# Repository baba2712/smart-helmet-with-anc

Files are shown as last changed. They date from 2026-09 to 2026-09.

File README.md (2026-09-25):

# ANC Safety Helmet

An industrial safety helmet with **hybrid active noise cancellation** (feed-forward + adaptive feedback FxLMS) on an STM32H743. Target: take ~100 dB(A) plant noise down to **≤ 75 dB(A) at the ear** (passive earcup + ANC), below the 85 dB(A) 8-hour limit. Also a built-in **noise dosimeter**, **hear-through** for speech and alarms, a **seal monitor** that measures the cup's attenuation while it is worn and warns when the seal leaks (glasses, hair, a tilted helmet), and an optional **BLE** link.

> Status: **prototype design, not certified PPE.** Nothing has been built or measured on real hardware yet. See [Status](#status).

## Simulated results (100 dB(A) ambient)

| Noise | Open ear | Passive cup | Passive + ANC | Total reduction |
| --- | --- | --- | --- | --- |
| Motor / fan (tonal) | 100.0 | 80.7 | **72.3 dB(A)** | 27.7 dB |
| Compressor | 99.9 | 77.3 | **73.6 dB(A)** | 26.4 dB |
| Broadband (pink) | 99.9 | 72.4 | **69.1 dB(A)** | 30.8 dB |

ANC adds 3–8.5 dB(A) on top of the passive cup; most gain is on tonal machine noise (80–400 Hz). Known limitation: energy below 63 Hz is not reduced. Full report: [`sim/results/summary.md`](sim/results/summary.md).

On **70 real field recordings** (engine, chainsaw, hand saw, helicopter, train, vacuum cleaner, washing machine; ESC-50) the level at the ear ends at 65–75 dB(A): [`sim/results/real_audio.md`](sim/results/real_audio.md). Engine rumble needs ~15 Pa of anti-noise at 63 Hz, which sets a driver requirement (below).

**Seal monitor** (10 noises × 4 seal conditions, one factory baseline): 23/23 leaks that cost ≥ 3 dB flagged in 3–5 s, 0 false alarms: [`sim/results/seal_monitor.md`](sim/results/seal_monitor.md).

## Repository

| Folder | What's in it |
| --- | --- |
| `sim/` | Python plant + noise models, the reference hybrid-FxLMS controller, and the full study (`run_all.py`). Also generates firmware tuning headers. `real_audio.py` runs it on real recordings; `seal_ref.py` / `seal_monitor.py` are the seal monitor's reference and study. |
| `firmware/` | Bare-metal C for STM32H743: 32 kHz ADC→DSP→DAC path, FxLMS core, path identification, dosimeter, hear-through, USB CDC (TinyUSB), BLE UART, flash storage, power/UI. `test/` holds firmware-in-the-loop tests against the sim. |
| `hardware/` | KiCad 7 projects (open fine in KiCad 8/9) for three boards, generated from `hardware/gen/` (Python circuit descriptions → schematic → PCB → Freerouting → fab files). `spice/` verifies the analog chain in ngspice. |
| `mechanical/` | OpenSCAD earcup inserts, driver baffle, outside-mic pod, light pipe / button plunger. Parametric; **measure your earmuff** and edit `params.scad`. `check_fit.py` cross-checks the parts against the PCBs and the cup. |
| `tools/` | `anc_tool.py`: host tool for the USB/BLE command link (status, tuning, calibration, driver test, dose log). `acceptance_test.py`: the per-helmet acceptance / TRL-6 evidence run. |
| `docs/` | Architecture notes; [`bringup_and_test.md`](docs/bringup_and_test.md): order, build, bring-up, calibration and the TRL-6 demonstration. |

## Boards

| Board | Layers | Size | State |
| --- | --- | --- | --- |
| `main-board`: MCU, power, charger, left-ear analog, amp | 4 | 60 × 50 mm, 14 mm corners | Routed; DRC 0 unconnected, 0 electrical errors; fab files in `fab/` |
| `satellite-board`: right-ear mic front ends | 2 | 34 × 26 mm | Routed; DRC 0 errors (silk warnings only); fab files in `fab/` |
| `mic-board`: IM73A135 MEMS mic (×4 per helmet) | 2 | 11 × 13.2 mm | Routed; DRC clean; fab files in `fab/` |

## Build and test

```bash
git clone --recursive <this repo>
pip install -r sim/requirements.txt

python3 sim/run_all.py                 # simulation study + regenerates firmware/inc/anc_tuning.h
python3 sim/real_audio.py --fetch      # ANC on real recordings (downloads ~30 MB of ESC-50 clips)
python3 sim/seal_monitor.py            # seal-monitor study (uses the recordings if present)
cd firmware && make                    # needs arm-none-eabi-gcc; -> build/anc_helmet.bin (~79 KB)
python3 test/test_fil.py               # firmware DSP vs simulation (all pass)

cd .. && python3 hardware/spice/run_spice.py   # analog chain in ngspice
python3 mechanical/check_fit.py                # parts vs PCBs vs cup

cd hardware/gen && python3 build.py sch                           # regenerate schematics
python3 pcb_build.py place main-board && python3 pcb_build.py route main-board
python3 pcb_build.py finish main-board && python3 pcb_build.py tie main-board
python3 pcb_build.py fab main-board
```

`pcb_build.py` needs KiCad 7's Python module (Ubuntu: `apt install kicad kicad-footprints kicad-symbols`, run with the system `python3`) and Freerouting 2.x at `../../tools-dl/freerouting2.jar` (or `FREEROUTING_JAR`).

Verified so far:
- Firmware compiles with `-Werror`: 78.8 KB flash, 38 KB DTCM, 4 KB ITCM.
- Firmware-in-the-loop tests all pass. C matches the Python reference to 0.0 dB(A) on all three noise types, and the output matches to about 1e-4 relative. The seal monitor matches its reference to < 0.001 dB with identical decisions.
- Path identification in a quiet room: 16 dB fit, 0.6% model error.
- Dosimeter: a 94 dB calibrator tone reads 93.99 dB(A); NIOSH dose math checks out.
- SPICE ([`hardware/spice/results/spice_results.md`](hardware/spice/results/spice_results.md)): mic front ends match the simulation's plant, noise ~23 dB(A) SPL; VMID buffer 85–87° phase margin (keep the 10 Ω isolation resistor); DAC reconstruction ~26 µs at 1 kHz.
- Mechanical fit: all checks pass; the main board clears the cup wall by only 0.45 mm (measure your earmuff).

## Status

Done:
- [x] Simulation study and tuned parameters
- [x] Firmware (compiles; DSP verified in the loop against the sim)
- [x] Schematics for all three boards
- [x] Satellite and mic boards routed, with Gerber, BOM and CPL files for JLCPCB
- [x] Real-recording ANC study, SPICE verification of the analog chain, mechanical fit check
- [x] Seal monitor (reference, study, firmware, FIL test)
- [x] Main board fully routed (Freerouting + `hardware/gen/finish_route.py`), fab files for all three boards
- [x] Printable STLs (`mechanical/stl/`, nominal earmuff), driver acceptance test in firmware, acceptance-test runner

Remaining:
- [ ] **Order and build** following [`docs/bringup_and_test.md`](docs/bringup_and_test.md).
- [ ] **Driver:** buy 2-3 candidate 40 mm drivers (16 Ω preferred) and keep one that passes `anc_tool.py driver-test` (≥ 17 Pa/V at 63 Hz in the cup).
- [ ] Open all three boards in KiCad 8/9 for a last ERC/DRC and 3D look before ordering (KiCad 7 DRC here is clean apart from two reviewed connector-courtyard overlaps).
- [ ] Measure the real earmuff, update `mechanical/params.scad`, re-run `check_fit.py`, export STLs.
- [ ] Calibrate and accept each helmet: `python3 tools/acceptance_test.py`, then the TRL-6 run (docs/bringup_and_test.md §6).
- [ ] Bring-up and acoustic test on real hardware: SPL meter plus a 94 dB calibrator.

## Safety

This is a research prototype. It is **not certified hearing protection.** Real PPE needs testing to EN 352 / ANSI S3.19 (or IS 9167 in India). The firmware fails safe: it drops to passive-only on divergence, output clipping, fault or low battery. The passive cup still has to protect on its own.

## License

MIT, © Khaja Baba Shaik.

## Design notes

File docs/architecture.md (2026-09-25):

# Architecture

## What the system does

A safety helmet with helmet-mount earmuffs. Each cup has two MEMS microphones and a
40 mm driver. One STM32H743 runs a **hybrid FxLMS** controller for both ears at
32 kHz. It adds anti-noise at the ear, keeps an exposure log (noise dosimeter),
and can pass speech and alarms through at a capped level.

```
 outside noise ~100 dB(A)
        |
        v
  [REF mic] ---+                          (outside the shell, per cup)
               |    [passive cup: -6 dB @63 Hz ... -35 dB @2 kHz]
               v
  +----- preamp + AA filter ----+        ADC1/ADC2 simultaneous, 16-bit, TIM6 @ 32 kHz
  |                             v
  |     x_c = x - F^ * u   (speaker leakage removed)
  |     d^  = e - S^ * u   (IMC disturbance estimate)
  |     y   = W_ff * x_c + W_fb * d^          <- hybrid FxLMS, weighted update
  |     u   = ramp * y + hear_through(x_c)    -> DAC1 -> recon filter -> TPA6132A2 -> driver
  |                             ^
  +----- preamp + AA filter ----+
               ^
  [ERR mic] ---+                          (in the cup, ~8 mm from the ear canal)
```

## Signal chain and latency budget

The controller can only cancel what it can predict. Every microsecond between the
sound reaching the reference mic and the anti-noise leaving the driver has to be
paid for by prediction. So the design avoids anything that buffers.

| Stage | Delay | Why this choice |
| --- | --- | --- |
| Mic + difference preamp | ~0 | Differential MEMS output: common-mode noise on the cable cancels |
| Anti-alias filter (1st-order pole + 2nd-order Sallen-Key, ~9 kHz) | ~30 µs | Kept low-order on purpose. Each pole costs delay |
| SAR ADC (not sigma-delta) | ~1-2 µs | An audio codec's decimation filter would add 0.5-1 ms and kill feed-forward ANC |
| DMA -> ISR -> both outputs computed | ~5 µs | Hot code in ITCM, state in DTCM (zero wait-state), no RTOS in the audio path |
| DAC (unbuffered write, no trigger) | 1 APB clock | Output updates right after the write |
| Zero-order hold + reconstruction filter | ~16 µs + ~25 µs | |
| Amp + driver + acoustic path to error mic | ~30 µs + driver phase | |

The simulation models every one of these as an exact fractional delay
(`sim/plant.py`). The latency sweep in `sim/results/summary.md` shows how much
attenuation each extra 30 µs costs.

## Control algorithm

Hybrid FxLMS, per ear. The files are `firmware/dsp/anc_core.c`, which mirrors
`sim/anc_ref.py` line for line.

* **Feed-forward** (128 taps): the outside mic as reference. Handles tonal machine
  noise (motors, fans, transformer hum) very well, because tonal noise is
  predictable, so causality doesn't limit it.
* **Adaptive feedback, IMC form** (64 taps): the reference is the disturbance
  estimated from the error mic, `d^ = e - S^*u`. It catches what the outside mic
  doesn't see.
* **Secondary-path model S^** (64 taps) and **leakage model F^** (128 taps):
  identified with a white-noise probe. This happens at the factory (quiet room)
  and is then *refined* at every power-on (2 s, ~83 dB SPL at the ear). The
  refinement doubles as a **fit check**: a lifted cup or a dead driver shows up
  as a big model change, and the helmet warns instead of misbehaving.
* **Normalised LMS with leakage**: step size is independent of noise level. Leakage
  (1e-5) keeps the filters bounded.
* **Frequency-weighted update**: a low-shelf (−20 dB below 300 Hz) on the error and
  filtered references. Without it, huge 50/100 Hz tones dominate the gradient,
  and the controller trades a fraction of a dB there for +8 to +20 dB of mid-band
  amplification (found in simulation, see the commit history).
* **30 Hz high-pass on both references**: the driver can't make infrasound. Chasing
  it drives the output into clipping, and the distortion is audible.

Tuned values live in one place, `sim/run_all.py::TUNED`. They are exported to
`firmware/inc/anc_tuning.h`.

## Safety logic (firmware)

| Guard | Trigger | Action |
| --- | --- | --- |
| Divergence watchdog | Error power > 6 dB above the disturbance estimate for 200 ms | Filters reset to zero |
| Clip watchdog | > 5 % of output samples clipped over 100 ms | Filters reset to zero |
| Ear overload | \|p\| at the error mic > 118 dB (sine peak), capped at 90 % of the channel's full scale (~14 Pa), for 50 ms | Forced passive + red LED |
| Output ceiling | Always | Anti-noise clamp at the lower of the DAC range and the amp's 0.9 V swing at the selected gain; hear-through hard-limited to 82 dB SPL |
| Mode changes | Always | 50 ms fades (no clicks) |
| No calibration | `paths_valid == 0` | ANC refuses to run; passive + magenta LED |
| Fit check failure at power-on | Model change > 6 dB or poor fit | Keeps the stored model; amber LED |
| Seal leak (in use) | Per-band cup attenuation >= 3 dB below the factory baseline for 3 s | Amber LED, `seal_leak` in status/BLE, log flag bit 4 |
| HardFault / watchdog reset | Any | DAC to mid-scale and amp muted *before* reset |
| Low battery | < 3.2 V | Saves the log record and powers off |

In every failure the helmet falls back to a **passive earmuff**. That is the safe state.

## Dosimeter

* A-weighted (IEC 61672 biquads at 32 kHz) level at the ear (energy mean of both
  error mics) and outside (reference mic), 1 s LAeq.
* Dose per NIOSH/ISO (85 dB(A), 3 dB exchange) by default. It is configurable for
  OSHA / the Indian Factories Act (90 dB(A), 5 dB exchange).
* A minute-by-minute record (at-ear and outside LAeq, running dose, battery, mode,
  flags) goes into a flash ring in bank 2. That is about 136 h of history, and it
  survives power cycles. The shift dose continues across power-offs until `dose reset`.
* The firmware test checks it against the standard: 94.0 dB at 1 kHz reads
  93.99 dB(A), and 100 dB(A) gives exactly NIOSH's 15 min allowance.

## Seal monitor (in-use protection check)

A cushion leak (safety-glasses temple, hair, a tilted helmet) costs 3-12 dB of
protection, and ANC cannot win it back: the driver's own low-frequency pressure
leaks out too. So the helmet measures its seal continuously and tells the wearer.

It needs no extra sensor or test signal. The ANC core already forms
`x_c = x - F_hat*y` (outside noise without the speaker's leakage) and
`d_hat = e - S_hat*y` (noise that came through the cup, ANC removed). Per ear,
the ISR accumulates octave-band (250 Hz-2 kHz) mean squares of both; once a
second the main loop computes the per-band attenuation `L(x_c) - L(d_hat)`.
Per-band attenuation belongs to the cup and its seal, not to the noise, so one
factory baseline (`seal learn`, reference head, broadband noise) holds for any
noise. Bands within 15 dB of the loudest outside band and above 55 dB count;
their mean shortfall vs the baseline, smoothed over ~4 s, raises the flag at
3 dB (1 dB hysteresis).

Simulation over 10 noises (3 synthetic, 7 real recordings) x 4 seal conditions:
23/23 real leaks flagged in 3-5 s, 0 false alarms (`sim/results/seal_monitor.md`).
C and Python agree to < 0.001 dB (`firmware/test/test_fil.py`). Reference:
`sim/seal_ref.py`; firmware: `seal_*` in `dsp/dsp_misc.c`.

## Boards

| Board | Where | What |
| --- | --- | --- |
| Main (60 × 50 mm, 4-layer) | Left cup | STM32H743VIT6, USB-C, Li-ion charger + power path, 3.3 V buck-boost, 2.8 V analog LDO, left mic front-ends, 2 × DAC reconstruction, TPA6132A2 stereo amp, BLE header, SWD, buttons/LEDs |
| Satellite (34 × 26 mm, 2-layer) | Right cup | Right mic front-ends (so the analog signal crosses the headband cable at line level), speaker connector |
| Mic (11 × 12.5 mm, 2-layer, × 4) | Outside shell and in front of each driver | IM73A135 differential MEMS mic (bottom port) + decoupling |

The pin map lives in one table (`hardware/gen/pinmap.py`). That table generates both
the schematic nets and `firmware/inc/board_pins.h`.

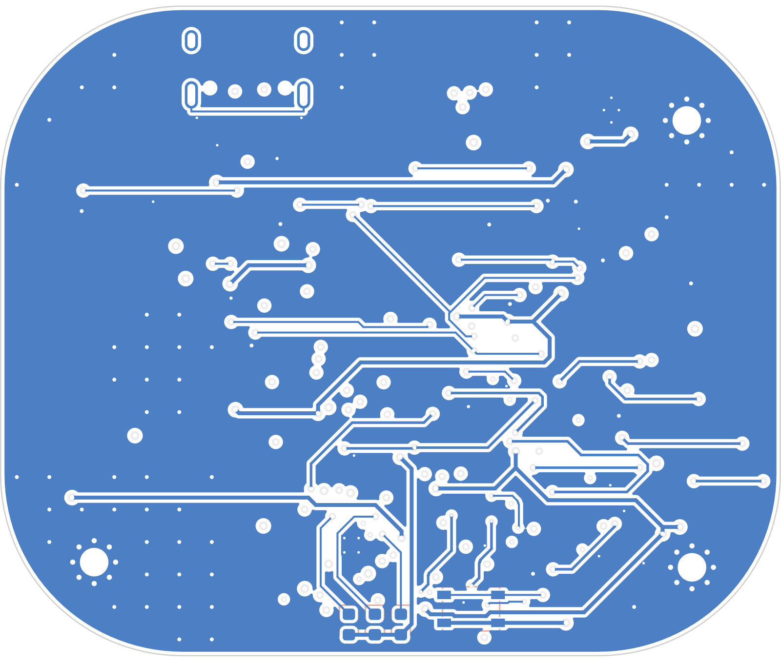
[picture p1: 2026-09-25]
hardware/main-board/fab/main-board-bottom.png

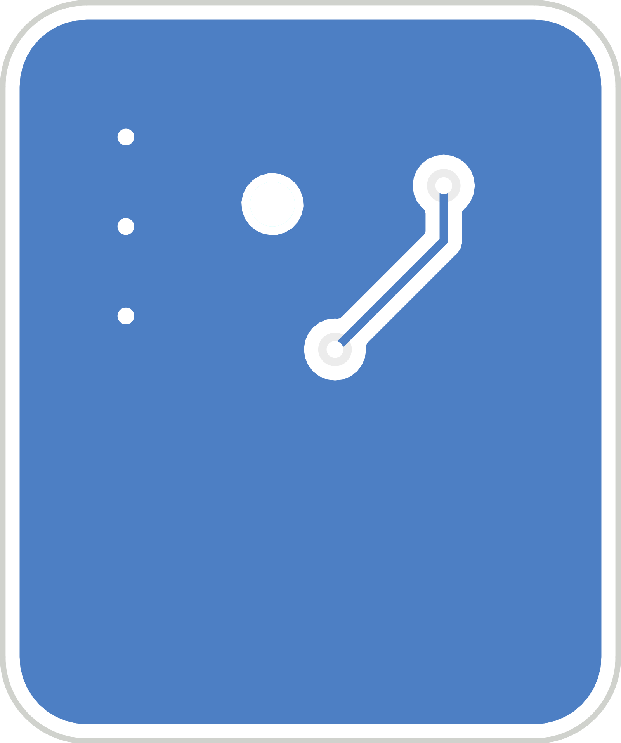
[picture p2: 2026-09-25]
hardware/mic-board/fab/mic-board-bottom.png

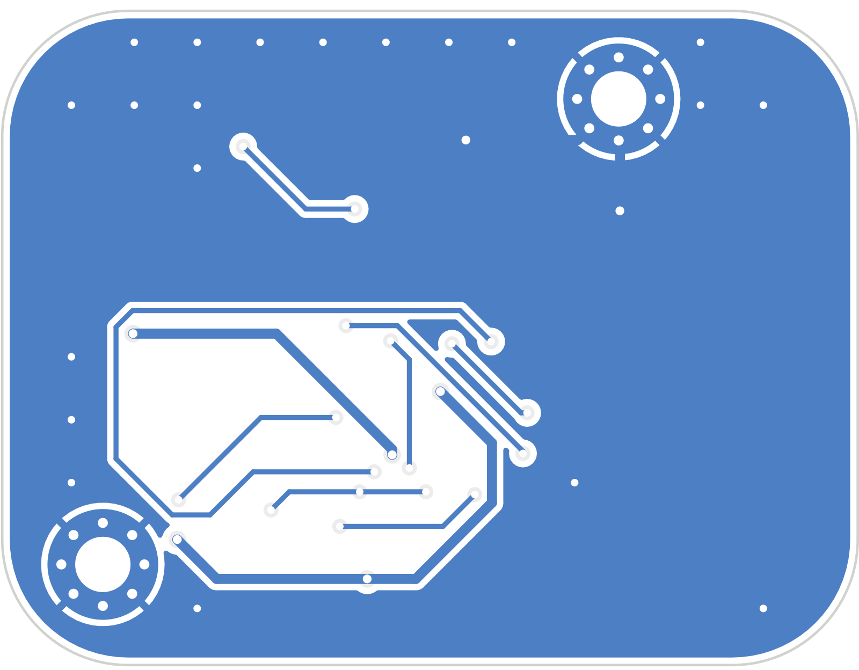
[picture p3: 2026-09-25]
hardware/satellite-board/fab/satellite-board-bottom.png

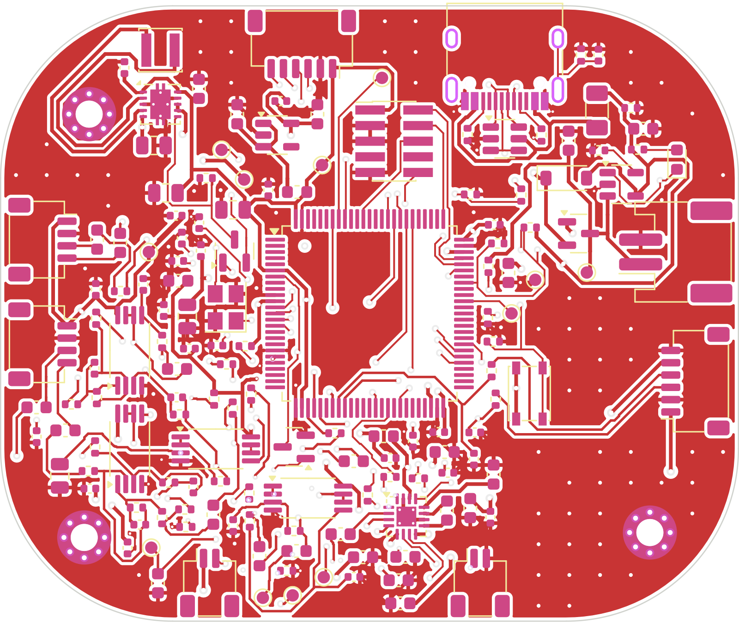
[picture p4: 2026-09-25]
hardware/main-board/fab/main-board-top.png

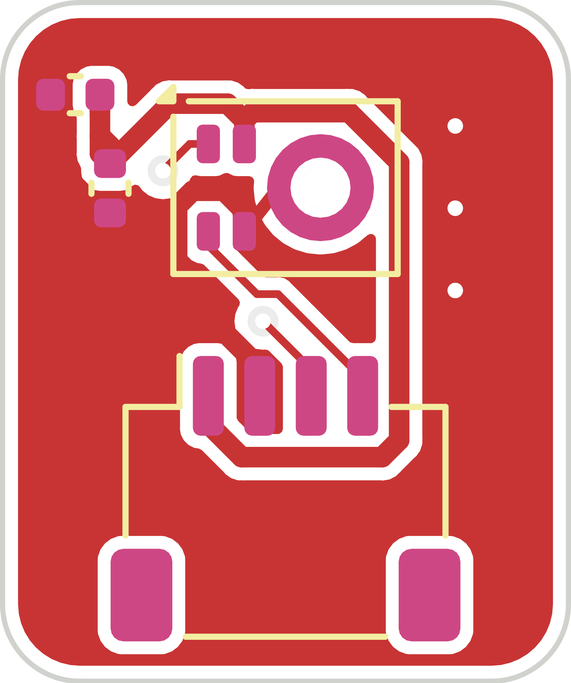
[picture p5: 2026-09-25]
hardware/mic-board/fab/mic-board-top.png

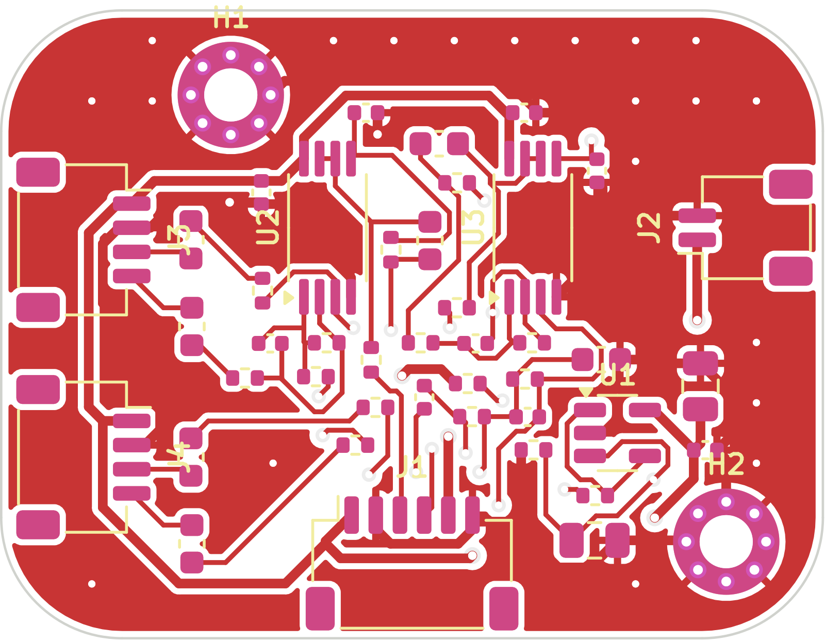
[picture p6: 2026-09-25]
hardware/satellite-board/fab/satellite-board-top.png

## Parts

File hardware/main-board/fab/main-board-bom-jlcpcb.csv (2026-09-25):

Comment | Designator | Footprint | Quantity | Manufacturer Part | LCSC Part # | Notes
4.7n | C1 | C_0402_1005Metric | 1 | 4.7n X7R 50V
4.7u | C16 | C_0603_1608Metric | 1 | 4.7u X7R
2.2u | C18,C19 | C_0603_1608Metric | 2 | 2.2u X7R
4.7u | C2,C3 | C_0603_1608Metric | 2 | 4.7u X5R 10V
12p | C25,C26 | C_0402_1005Metric | 2 | 12p C0G
10u | C27,C62 | C_0805_2012Metric | 2 | 10u X5R |  | BLE module bulk
220p | C32,C33 | C_0402_1005Metric | 2 | 220p C0G
4.7n | C34,C42 | C_0603_1608Metric | 2 | 4.7n C0G
1n | C35,C43 | C_0402_1005Metric | 2 | 1n C0G
2.2n | C37,C45,C46,C47 | C_0402_1005Metric | 4 | 2.2n C0G
100n | C4,C10,C11,C12,C13,C14,C15,C17,C21,C23,C24,C28,C36,C44,C56,C58 | C_0402_1005Metric | 16 | 100n X7R |  | VBAT pin; VDDA; VREF+
100p | C40,C41 | C_0402_1005Metric | 2 | 100p C0G
3.3n | C48,C52 | C_0603_1608Metric | 2 | 3.3n C0G
1.5n | C49,C53 | C_0402_1005Metric | 2 | 1.5n C0G
10u | C5 | C_0805_2012Metric | 1 | 10u X5R 10V
2.2u | C57,C59,C60 | C_0603_1608Metric | 3 | 2.2u X5R
22u | C6,C7 | C_0805_2012Metric | 2 | 22u X5R 10V
1u | C61 | C_0603_1608Metric | 1 | 1u X5R
1u | C8,C20,C22,C29,C30,C31,C38,C39,C50,C51,C54,C55 | C_0603_1608Metric | 12 | 1u X7R |  | VDDA; VREF+
4.7u | C9 | C_0603_1608Metric | 1 | 4.7u X5R
orange | D1 | LED_0603_1608Metric | 1 | 0603 orange LED
B5819W | D2 | D_SOD-123 | 1 | B5819W
BAT54C | D3 | SOT-23 | 1 | BAT54C
red | D4 | LED_0603_1608Metric | 1 | 0603 red LED |  | BOTTOM SIDE (hand-solder, or order 2-sided assembly)
green | D5 | LED_0603_1608Metric | 1 | 0603 green LED |  | BOTTOM SIDE (hand-solder, or order 2-sided assembly)
blue | D6 | LED_0603_1608Metric | 1 | 0603 blue LED |  | BOTTOM SIDE (hand-solder, or order 2-sided assembly)
0.5A | F1 | Fuse_1206_3216Metric | 1 | Littelfuse 1206L050YR
220R@100MHz | FB1,FB2 | L_0603_1608Metric | 2 | BLM18PG221SN1D
USB-C | J1 | USB_C_Receptacle_HRO_TYPE-C-31-M-12 | 1 | HRO TYPE-C-31-M-12
BATTERY 1S Li-ion (protected) | J2 | JST_PH_S2B-PH-SM4-TB_1x02-1MP_P2.00mm_Horizontal | 1 | JST S2B-PH-SM4-TB |  | pin 1 = BAT+ (check your pack's wiring!)
EXT BUTTON | J3 | JST_SH_SM02B-SRSS-TB_1x02-1MP_P1.00mm_Horizontal | 1 | JST SM02B-SRSS-TB |  | optional panel button on the cup
SWD | J4 | PinHeader_2x05_P1.27mm_Vertical_SMD | 1 | Cortex debug 2x5 1.27 mm SMD
LEFT OUTSIDE (REF) MIC | J5 | JST_SH_SM04B-SRSS-TB_1x04-1MP_P1.00mm_Horizontal | 1 | JST SM04B-SRSS-TB
LEFT IN-CUP (ERR) MIC | J6 | JST_SH_SM04B-SRSS-TB_1x04-1MP_P1.00mm_Horizontal | 1 | JST SM04B-SRSS-TB
TO RIGHT CUP | J7 | JST_SH_SM06B-SRSS-TB_1x06-1MP_P1.00mm_Horizontal | 1 | JST SM06B-SRSS-TB
LEFT SPEAKER | J8 | JST_SH_SM02B-SRSS-TB_1x02-1MP_P1.00mm_Horizontal | 1 | JST SM02B-SRSS-TB
BLE UART MODULE | J9 | JST_SH_SM06B-SRSS-TB_1x06-1MP_P1.00mm_Horizontal | 1 | JST SM06B-SRSS-TB
2.2u | L1 | L_Changjiang_FNR3015S | 1 | 2.2 uH >=1.5 A shielded 3x3 (e.g. TDK VLS3015ET-2R2M)
AO3401A | Q1 | SOT-23 | 1 | AO3401A |  | battery -> system when USB absent
MMBT3904 | Q2 | SOT-23 | 1 | MMBT3904
5.1k | R1,R2 | R_0402_1005Metric | 2 | 5.1k 1% 02_1
10k | R16,R17,R21,R22 | R_0402_1005Metric | 4 | 10k 1% 02_1
470 | R20 | R_0402_1005Metric | 1 | 470 1% 02_1
10 | R23 | R_0402_1005Metric | 1 | 10 1% 02_1
22k | R24,R25,R31,R32 | R_0402_1005Metric | 4 | 22k 1% 02_1
75k | R26,R27 | R_0402_1005Metric | 2 | 75k 1% 02_1
8.2k | R28,R29,R35,R36,R40,R41,R42,R43 | R_0402_1005Metric | 8 | 8.2k 1% 02_1
1M | R3 | R_0402_1005Metric | 1 | 1M 1% 02_1
47 | R30,R37,R38,R39 | R_0402_1005Metric | 4 | 47 1% 02_1
150k | R33,R34 | R_0402_1005Metric | 2 | 150k 1% 02_1
100k | R4,R9,R10,R11,R12,R13,R15 | R_0402_1005Metric | 7 | 100k 1% 02_1
200k | R5 | R_0402_1005Metric | 1 | 200k 1% 02_1
2.0k | R6 | R_0402_1005Metric | 1 | 2.0k 1% 02_1 |  | 500 mA charge current
1k | R7,R18,R19 | R_0402_1005Metric | 3 | 1k 1% 02_1
47k | R8,R14 | R_0402_1005Metric | 2 | 47k 1% 02_1
POWER | SW1 | SW_SPST_PTS810 | 1 | C&K PTS810 SJM 250 SMTR LFS |  | BOTTOM SIDE (hand-solder, or order 2-sided assembly)
BOOT | SW2 | SW_SPST_PTS810 | 1 | C&K PTS810 SJM 250 SMTR LFS |  | hold while powering on -> USB DFU
USBLC6-2SC6 | U1 | SOT-23-6 | 1 | USBLC6-2SC6
TPA6132A2 | U10 | WQFN-16-1EP_3x3mm_P0.5mm_EP1.6x1.6mm_ThermalVias | 1 | TPA6132A2RTER
MCP73831-2 | U2 | SOT-23-5 | 1 | MCP73831T-2ACI/OT
TPS63001 | U3 | Texas_DRC0010J_ThermalVias | 1 | TPS63001DRCR |  | PS/SYNC high = forced 1.5 MHz PWM (no PFM bursts in the audio band)
LP5907-2.8 | U4 | SOT-23-5 | 1 | LP5907MFX-2.8/NOPB
STM32H743VIT6 | U5 | LQFP-100_14x14mm_P0.5mm | 1 | STM32H743VIT6
MCP6022 | U6,U7,U8,U9 | TSSOP-8_4.4x3mm_P0.65mm | 4 | MCP6022-I/ST |  | unit B unused (follower)
25MHz | Y1 | Crystal_SMD_3225-4Pin_3.2x2.5mm | 1 | 25 MHz 3225 CL=10pF +-20ppm (e.g. Abracon ABM8)

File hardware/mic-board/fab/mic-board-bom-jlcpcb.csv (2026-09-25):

Comment | Designator | Footprint | Quantity | Manufacturer Part | LCSC Part # | Notes
100n | C1 | C_0402_1005Metric | 1 | 100n X7R
1u | C2 | C_0402_1005Metric | 1 | 1u X5R
MIC | J1 | JST_SH_SM04B-SRSS-TB_1x04-1MP_P1.00mm_Horizontal | 1 | JST SM04B-SRSS-TB
IM73A135V01 | MK1 | Infineon_PG-LLGA-5-2 | 1 | IM73A135V01XTSA1 |  | bottom port: sound enters through the PCB hole - mount the plain back side toward the sound

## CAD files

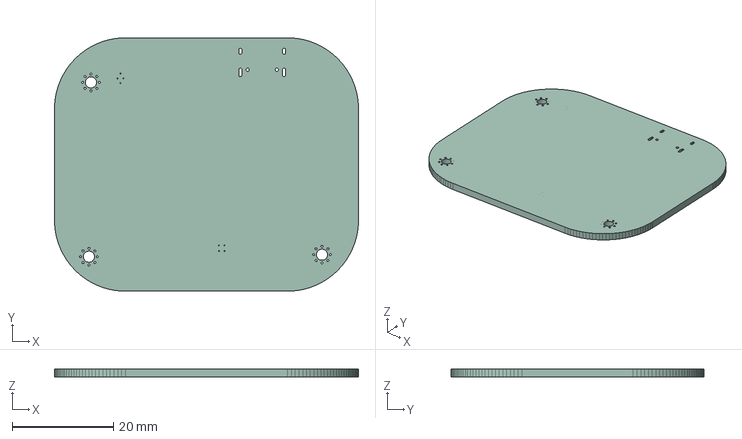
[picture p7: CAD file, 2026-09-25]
hardware/main-board/fab/main-board.step
60.0 x 50.0 x 1.60 mm

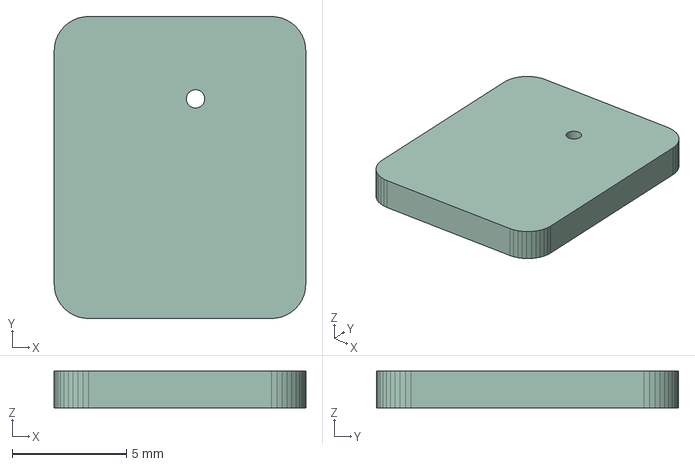
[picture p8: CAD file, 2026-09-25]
hardware/mic-board/fab/mic-board.step
11.0 x 13.2 x 1.60 mm

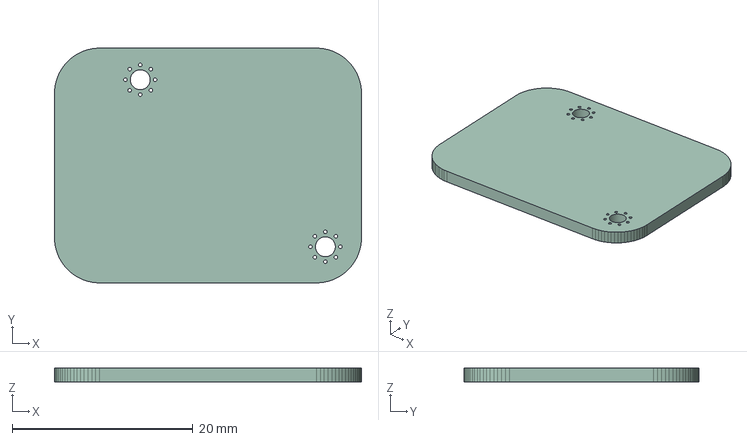
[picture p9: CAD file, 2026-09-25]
hardware/satellite-board/fab/satellite-board.step
34.0 x 26.0 x 1.60 mm

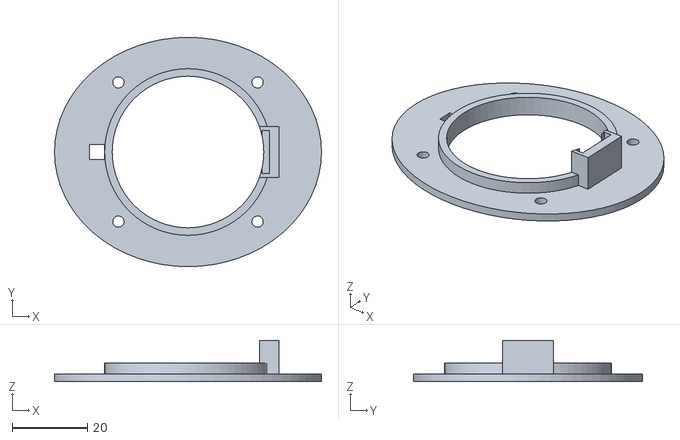
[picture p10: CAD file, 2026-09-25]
mechanical/stl/cup_insert_right-baffle.stl
70.8 x 60.8 x 11.0

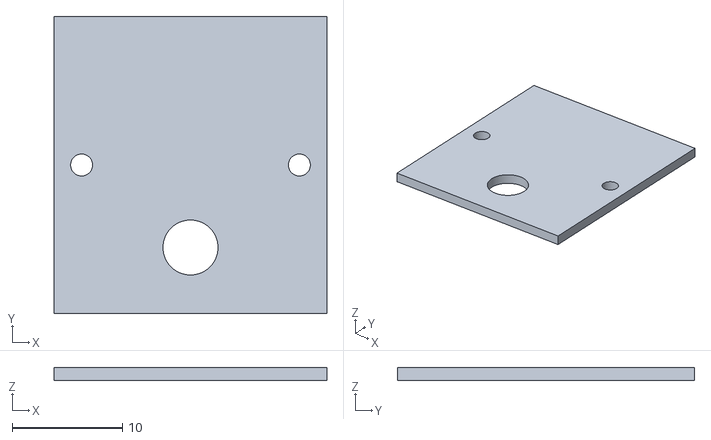
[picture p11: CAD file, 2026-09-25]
mechanical/stl/mic_pods-template.stl
24.8 x 27.0 x 1.20

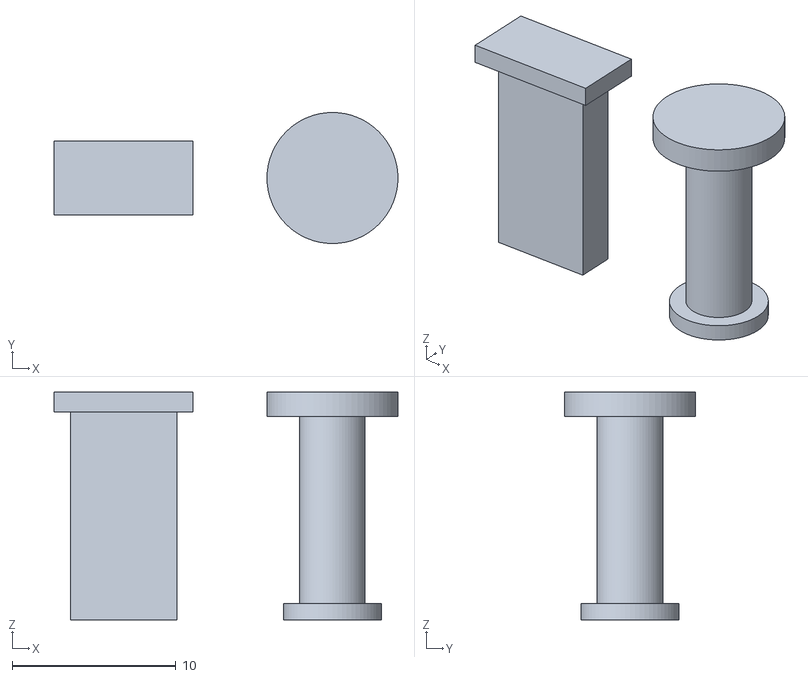
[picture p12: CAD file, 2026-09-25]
mechanical/stl/light_pipe_button.stl
21.0 x 8.00 x 13.9

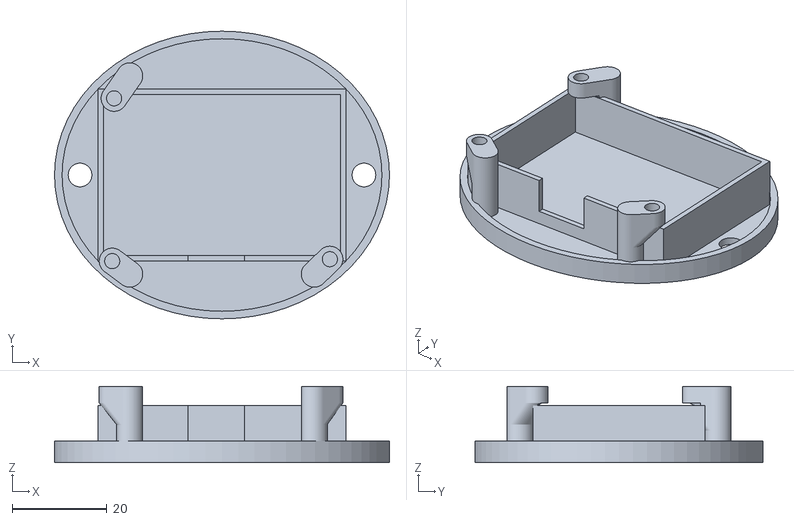
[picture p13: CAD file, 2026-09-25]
mechanical/stl/cup_insert_left-tray.stl
70.8 x 60.8 x 16.1

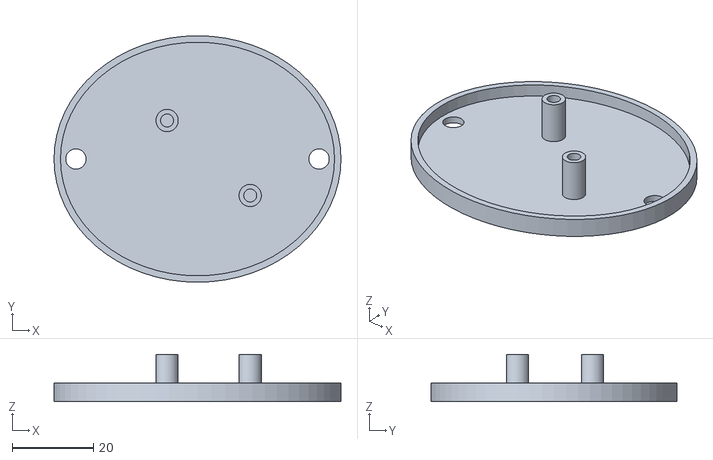
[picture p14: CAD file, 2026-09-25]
mechanical/stl/cup_insert_right-tray.stl
70.8 x 60.8 x 11.6

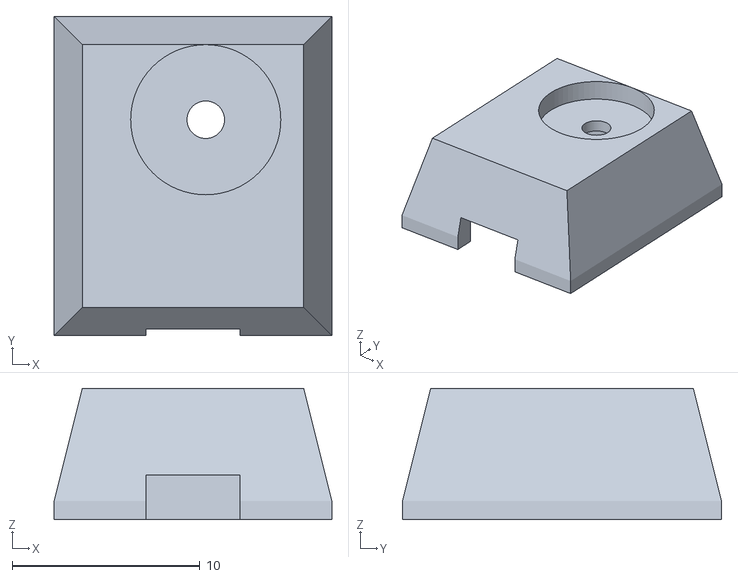
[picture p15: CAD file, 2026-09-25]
mechanical/stl/mic_pods-pod.stl
14.8 x 17.0 x 7.00

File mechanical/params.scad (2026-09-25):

// ANC helmet - shared mechanical parameters (mm).
// MEASURE YOUR EARMUFF and edit the "cup" block; everything else follows.

// ---- helmet-mount earmuff cup (inside, after removing the stock foam insert) ----
cup_a        = 72;    // inner long axis (vertical when worn)
cup_b        = 62;    // inner short axis
cup_depth    = 32;    // inner depth, rim to back wall
cup_wall     = 2.5;   // shell thickness where the outside mic sits

// ---- boards (must match hardware/gen/layouts.py; `python3 check_fit.py` verifies) ----
main_w = 60;  main_h = 50;  main_r = 14;
main_holes = [[7.2, 8.8], [52.8, 42.8], [6.8, 43.2]];  // from the board's top-left corner
sat_w  = 34;  sat_h  = 26;  sat_r  = 5;
sat_holes  = [[9.5, 3.5], [30, 22]];
mic_w  = 11;  mic_h  = 13.2;
mic_port   = [6.18, 3.6];                           // sound hole on the mic board (PCB underside)
pcb_t  = 1.6;

// ---- parts that live in the cups ----
driver_d      = 40.2;   // 40 mm headphone driver
driver_depth  = 6.0;
batt          = [50, 34, 10.5];   // 103450 LiPo pouch, 2000 mAh (with protection PCB)
m2_clear      = 2.3;
m2_insert_d   = 3.2;    // heat-set insert hole
standoff_h    = 4.0;

$fn = 64;

module rounded_rect(w, h, r, t) {
    linear_extrude(t) offset(r) offset(-r) square([w, h]);
}

module ellipse(a, b, t) { linear_extrude(t) scale([a / 2, b / 2]) circle(1); }

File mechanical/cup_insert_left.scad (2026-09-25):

// Left cup insert: holds the main board + battery against the back wall of the cup,
// and carries the 40 mm driver on a baffle in front of them (toward the ear).
//
//   back wall of cup | battery | main board (components facing the ear) | baffle + driver | foam | ear
//
// Print in PETG or ASA (PLA softens in a hot car/plant), 0.2 mm layers, 3 perimeters.
include <params.scad>

part = "all";   // openscad -D 'part="..."' exports one part

tray_t   = 1.6;
gap      = 0.6;            // clearance to the cup wall
clip_h   = 3;

module outline(t, shrink = 0) {
    ellipse(cup_a - 2 * (gap + shrink), cup_b - 2 * (gap + shrink), t);
}

// ---------------- rear tray: battery pocket + board standoffs ----------------
boss_gap = 0.5;            // air between the battery top and the underside of a board boss
standoff_d = 5.5;
pillar_x_max = 19.5;       // pillars move toward the centre, where the elliptical cup has room

// pillar centre for a board hole: just outside the battery fence (in y), and no further out
// in x than pillar_x_max so the pillar stays inside the cup
function pillar_xy(h) = let (x = h[0] - main_w / 2, y = main_h / 2 - h[1])
    [sign(x) * min(abs(x), pillar_x_max), sign(y) * (batt[1] / 2 + 1.2 + standoff_d / 2)];

module standoff(h) {
    x = h[0] - main_w / 2;
    y = main_h / 2 - h[1];
    p = pillar_xy(h);
    z_boss = tray_t + batt[2] + boss_gap;       // boss underside, just above the battery
    z_top  = tray_t + batt[2] + standoff_h;     // board underside (unchanged)
    reach  = norm([p[0] - x, p[1] - y]);        // horizontal pillar-to-boss distance
    translate([p[0], p[1], 0]) cylinder(d = standoff_d, h = z_top);
    // lug: 45-degree underside from the pillar up to the boss, so it prints without support
    hull() {
        translate([p[0], p[1], z_boss - reach]) cylinder(d = standoff_d, h = z_top - z_boss + reach);
        translate([x, y, z_boss]) cylinder(d = standoff_d, h = z_top - z_boss);
    }
}
module rear_tray() {
    difference() {
        union() {
            outline(tray_t);
            // rim wall so the tray self-centres in the cup
            difference() { outline(clip_h + tray_t); translate([0, 0, -1]) outline(clip_h + 3, 1.6); }
            // battery fence
            translate([-batt[0] / 2 - 1.2, -batt[1] / 2 - 1.2, 0])
                difference() {
                    cube([batt[0] + 2.4, batt[1] + 2.4, tray_t + batt[2]]);
                    translate([1.2, 1.2, tray_t]) cube([batt[0], batt[1], batt[2] + 1]);
                    translate([batt[0] / 2 - 6, -1, tray_t + 3]) cube([12, 5, batt[2]]);   // lead exit
                }
            // main-board standoffs: the board's holes sit over the battery's corners, so each
            // standoff is a pillar just outside the battery fence plus a lug bridging over the
            // battery to a boss under the hole (checked by check_fit.py)
            difference() {
                for (h = main_holes) standoff(h);
                translate([-batt[0] / 2 - 0.2, -batt[1] / 2 - 0.2, tray_t])
                    cube([batt[0] + 0.4, batt[1] + 0.4, batt[2] + boss_gap]);
            }
        }
        for (h = main_holes)
            translate([h[0] - main_w / 2, main_h / 2 - h[1], tray_t + batt[2] + boss_gap + 0.6])
                cylinder(d = m2_insert_d, h = 40);
        // cable pass-throughs to the outside mic and the right cup (headband cable)
        translate([-cup_a / 2 + 6, 0, -1]) cylinder(d = 5, h = 10);
        translate([cup_a / 2 - 6, 0, -1]) cylinder(d = 5, h = 10);
    }
}

// ---------------- front baffle: driver + error-mic arm ----------------
module baffle() {
    t = 2.0;
    difference() {
        union() {
            outline(t);
            translate([0, 0, 0]) cylinder(d = driver_d + 4, h = t + driver_depth * 0.5);
            // error-mic arm: puts the mic ~8 mm in front of the driver, near the ear canal
            translate([driver_d / 2 - 2, -mic_w / 2 - 1.2, 0]) cube([6, mic_w + 2.4, t + 9]);
        }
        translate([0, 0, -1]) cylinder(d = driver_d, h = 20);              // driver seat
        translate([0, 0, -1]) cylinder(d = driver_d - 3, h = 20);
        // mic board slot (plain back toward the ear, sound hole facing out)
        translate([driver_d / 2 - 0.5, -mic_w / 2 - 0.2, t + 1]) cube([pcb_t + 0.4, mic_w + 0.4, 20]);
        // rear-volume vent (tuning: tape over partially to change the driver's LF response)
        for (a = [45, 135, 225, 315]) rotate(a) translate([driver_d / 2 + 6, 0, -1]) cylinder(d = 3, h = 10);
        // wire slot
        translate([-driver_d / 2 - 6, -2, -1]) cube([4, 4, 10]);
    }
}

// layout for printing
if (part == "all") rear_tray();
if (part == "tray") rear_tray();
if (part == "all") translate([0, cup_b + 10, 0]) baffle();
if (part == "baffle") baffle();

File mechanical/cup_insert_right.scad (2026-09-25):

// Right cup insert: satellite board + driver baffle (same baffle as the left cup).
include <params.scad>

part = "all";   // openscad -D 'part="..."' exports one part
use <cup_insert_left.scad>

tray_t = 1.6;
gap    = 0.6;

module right_tray() {
    difference() {
        union() {
            ellipse(cup_a - 2 * gap, cup_b - 2 * gap, tray_t);
            difference() {
                ellipse(cup_a - 2 * gap, cup_b - 2 * gap, tray_t + 3);
                translate([0, 0, -1]) ellipse(cup_a - 2 * gap - 3.2, cup_b - 2 * gap - 3.2, 6);
            }
            for (h = sat_holes)
                translate([h[0] - sat_w / 2, sat_h / 2 - h[1], 0]) cylinder(d = 5.5, h = tray_t + standoff_h + 6);
        }
        for (h = sat_holes)
            translate([h[0] - sat_w / 2, sat_h / 2 - h[1], tray_t + 1]) cylinder(d = m2_insert_d, h = 20);
        translate([-cup_a / 2 + 6, 0, -1]) cylinder(d = 5, h = 10);     // outside mic cable
        translate([cup_a / 2 - 6, 0, -1]) cylinder(d = 5, h = 10);      // headband cable
    }
}

if (part == "all") right_tray();
if (part == "tray") right_tray();
if (part == "all") translate([0, cup_b + 10, 0]) baffle();
if (part == "baffle") baffle();

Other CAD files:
mechanical/stl/cup_insert_left-baffle.stl
mechanical/light_pipe_button.scad
mechanical/mic_pods.scad

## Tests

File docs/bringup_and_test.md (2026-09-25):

# Build, bring-up and TRL-6 demonstration

What it takes to go from this repository to a demonstrated prototype. TRL 6 means the
system prototype works in a relevant environment, so for this helmet that means real
industrial-level noise, a real or simulated head, and measured results.
Everything up to "Order" is done in the repository. The rest needs hands and hardware.

## 1. Order the boards (JLCPCB)

| Board | Files | Settings |
| --- | --- | --- |
| main (×1 per helmet) | `hardware/main-board/fab/main-board-gerbers-jlcpcb.zip`, `-bom-jlcpcb.csv`, `-cpl-jlcpcb.csv` | 4 layers, 1.6 mm, JLC04161H-7628 stack-up, **ENIG** (LQFP-100 and 0.5 mm WQFN pads), min track/gap 0.127 mm, min via 0.45/0.2 mm |
| satellite (×1) | `hardware/satellite-board/fab/…` | 2 layers, 1.6 mm, HASL lead-free is fine |
| mic (×4) | `hardware/mic-board/fab/…` | 2 layers, **1.0 mm** so the MEMS sound port is short; ENIG |

Assembly: upload the BOM and CPL. The BOM has values, dielectrics and exact MPNs but no
LCSC numbers on purpose. Let JLCPCB's matcher propose parts, and check each proposal
against the value, package and MPN column before you confirm. A wrong LCSC number means a
wrong part soldered. Parts on the bottom side (D4–D6 status LEDs, SW1 power button) need
two-sided assembly, or solder them by hand.

Hand-solder: the JST connectors if the matcher has no stock, the battery lead and the drivers.

## 2. Buy

| Item | Qty | Notes |
| --- | --- | --- |
| 40 mm headphone drivers, 16 Ω preferred | 2-3 candidate models × 2 | Qualified in the cup with `test driver` (step 5): need ≥ 17 Pa/V at 63 Hz. |
| 103450 Li-ion pouch, 2000 mAh, with protection PCB | 1 | 50 × 34 × 10.5 mm max; JST PH 2.0 lead |
| Helmet-mount earmuffs (SNR ~27 dB) | 1 pair | The passive cup the ANC adds to |
| Industrial safety helmet with earmuff slots | 1 | |
| JST SH 1.0 mm cables (2, 4, 6 pin) | set | mics, speakers, left-right cable |
| M2 heat-set inserts + M2 × 4 screws | 5 + 5 | |
| ST-Link V2/V3 + 2×5 1.27 mm cable | 1 | SWD flashing |
| Class 1/2 SPL meter, 94 dB 1 kHz calibrator | 1 each | measurement reference |

## 3. Mechanical

1. Remove the earmuff's foam insert and measure the cup inside with calipers: long axis,
   short axis, depth, and wall thickness where the outside mic goes.
2. Put the numbers in `mechanical/params.scad`, then run `python3 mechanical/check_fit.py`.
   It must pass. The main board has only 0.45 mm of clearance in the nominal cup.
3. Run `mechanical/export_stl.sh`. Print in PETG or ASA with 0.2 mm layers and 3 perimeters.
   The light pipe is clear PETG, the button plunger TPU.

## 4. Bring-up (before the battery)

1. Look for solder bridges on U5 (LQFP-100), U10 (WQFN-16) and U3 (QFN).
2. Put a bench supply on the battery connector J2: **3.7 V, 100 mA current limit**.
   Current should settle below about 60 mA with no firmware.
3. Rails: 3V3 = 3.30 V ± 3 %, 2V8A = 2.80 V ± 2 %, VMID = 1.40 V ± 20 mV.
4. Flash over SWD: `cd firmware && make flash`, or `make dfu` over USB with BOOT held.
5. Connect USB-C. The charge LED should light, and `python3 tools/anc_tool.py status` should
   print one JSON line.
6. Connect the battery and check that `vbat` reads within 50 mV of a multimeter.

## 5. Calibrate and accept (per helmet)

```bash
python3 tools/acceptance_test.py --serial proto-01
```

It runs, prompting the operator where needed:

| Step | What | Pass |
| --- | --- | --- |
| health | firmware reply, battery, CPU load, worst ISR time | CPU ≤ 80 %, ISR ≤ 25 µs |
| mics | 94 dB calibrator on each of the 4 mics, trims stored | trim within ± 6 dB |
| paths | factory speaker-path identification, quiet room | fit ≥ 10 dB |
| driver | 63 Hz tone, in-cup Pa/V per ear | ≥ 17 Pa/V |
| seal_learn | factory seal baseline, good fit, broadband noise | baseline stored |
| noise | ~100 dB(A) industrial noise: passive vs ANC | ear ≤ 80 dB(A), ANC ≥ 3 dB(A), helmet vs meter ≤ 2 dB |
| seal | glasses temple under a cushion, then reseat | flagged ≤ 15 s, cleared ≤ 20 s |
| soak | 10 min ANC in noise | no trips, overruns or overloads |

The report goes to `reports/<serial>-<date>/acceptance.md` and `.json`. Every limit names
the study it comes from.

## 6. TRL-6 demonstration

**Relevant environment:** broadband industrial noise at 95–105 dB(A). Use a recording of real
plant noise (motors, compressors, a press line) through a PA speaker in a small room, or run
it on site. **Test head:** an acoustic test fixture (a head-and-torso simulator, or a DIY head
with an ear-simulator mic) rather than a person. Hearing protection is the device under test,
so nobody should rely on it at 100 dB(A) before it has passed.

Evidence pack:
1. Acceptance reports for two helmets (repeatability).
2. Ear level with ANC on and off, from the helmet's error mic **and** from the fixture's
   ear mic, for three noise types.
3. Seal monitor with three glasses frames (thin, medium, thick): time to flag, and the
   measured drop against the fixture's measured loss.
4. A 2-hour run on battery: dose log download (`anc_tool.py log`) against a reference dosimeter.
5. Photos and video of the setup, the firmware version and the git commit.

**After TRL 6** (for PPE certification, TRL 7+): lab testing of the passive cup and then the
active system to EN 352-4/-5 / ANSI S12.42 / IS 9167, and the electrical safety and EMC
tests for a battery product.

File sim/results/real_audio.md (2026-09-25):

# ANC on real recorded noise (ESC-50 clips)

10 clips per category, silence-trimmed and joined into 20 s, scaled to 100 dB(A) outside. Levels at the ear over the last 5 s; same plant, factory calibration and tuned controller as `run_all.py`.

| Noise | Open ear | Passive cup | Passive + ANC | ANC adds | Best 1/3-oct ANC gain, 80-500 Hz | Watchdog trips | + ANC, 20 Pa headroom (trips) |
| --- | --- | --- | --- | --- | --- | --- | --- |
| engine | 99.7 | 78.3 | **74.8** | 3.6 dB | 8.9 dB | 6 | 73.9 (0) |
| chainsaw | 100.6 | 73.4 | **69.0** | 4.3 dB | 17.5 dB | 0 | 69.0 (0) |
| hand_saw | 99.8 | 69.5 | **68.8** | 0.8 dB | 12.5 dB | 0 | 68.8 (0) |
| helicopter | 97.3 | 72.7 | **69.9** | 2.7 dB | 9.9 dB | 0 | 69.9 (0) |
| train | 101.3 | 78.6 | **71.8** | 6.7 dB | 17.3 dB | 2 | 71.8 (0) |
| vacuum_cleaner | 98.0 | 73.7 | **65.3** | 8.4 dB | 27.0 dB | 0 | 65.3 (0) |
| washing_machine | 102.1 | 74.9 | **68.4** | 6.5 dB | 27.9 dB | 0 | 68.4 (0) |

Watchdog trips are all from output clipping (the anti-noise wanted more than the 10 Pa clamp, i.e. more than the driver/amp is assumed to deliver), not from divergence: every trip resets the filters and costs ~1 dB. Low-frequency engine rumble needs ~15 Pa peak at the ear. With 20 Pa of headroom there are no trips; whether the TPA6132A2 + 40 mm driver can deliver that is the hardware question the SPICE study answers.

Source: ESC-50, K. J. Piczak, CC BY-NC 3.0 (https://github.com/karolpiczak/ESC-50). Consumer field recordings: content below ~50 Hz is under-represented.

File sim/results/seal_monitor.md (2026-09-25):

# Seal-aware protection: self-measured attenuation while worn

Ambient 100 dB(A). Four seal conditions (passive insertion loss scaled to 100 %, 85 %, 70 %, 55 %) x 10 noises (3 synthetic + real ESC-50 recordings). The leak also raises the driver's low-frequency leak corner (35 Hz / seal^2: 35, 48, 71, 116 Hz), so the factory secondary-path model is wrong under a leak, as it would be on a real head. Estimates use only signals the firmware already has (outside mic, error mic, controller output, factory S_hat/F_hat), 1 s windows. Detection uses the firmware's logic (`seal_ref.py`): octave bands 250 Hz-2 kHz against **one** factory baseline measured once (good seal, pink noise: 250 Hz 17.0 dB, 500 Hz 24.6 dB, 1000 Hz 31.0 dB, 2000 Hz 34.7 dB), used for every noise.

- **Passive-attenuation estimate error:** mean +0.24 dB, worst 1.04 dB (estimate vs. the plant's true attenuation on the same noise).
- **Leak detection** (band attenuation 3 dB below the factory baseline): 23 of 23 leaks that really cost >= 3 dB flagged, 0 false alarms on 10 good-seal runs, flagged 3-5 s after switch-on.
- **What a one-time fit test misses:** it certifies the good-seal level. A thick glasses temple later in the shift raises the real dose 3.9-8.7x, a poor fit 9.2-26.5x (NIOSH 3 dB exchange), with ANC running. Here it is measured continuously (1 s windows) and flagged.
- **ANC cannot make up for a leak:** its average gain falls from 4.3 -> 3.3 -> 2.1 -> 1.4 dB(A) as the seal worsens, and watchdog resets rise (4 -> 24 -> 57 -> 108 across all noises), because the driver's own low-frequency pressure leaks out too. Re-identifying the secondary path on the head was tested and does not restore it on tonal noise. The only fix is the wearer reseating the cup, so the product's response to a flag is an alert (tone + LED + log), not silent compensation.

| Noise | Seal | True passive IL (A) | Estimated IL (A) | True loss | Band drop vs factory | Flagged (s) | At ear, ANC on | ANC adds | Measured PAR | Dose vs fit |
| --- | --- | --- | --- | --- | --- | --- | --- | --- | --- | --- |
| motor | good seal | 19.4 | 20.5 | 0.0 | 1.1 | no | 72.4 | 8.2 | 27.6 | 1.0x |
| motor | thin glasses temple | 17.4 | 18.0 | 2.0 | 4.7 | yes (3) | 75.6 | 7.0 | 24.4 | 2.1x |
| motor | thick glasses temple | 15.1 | 15.3 | 4.3 | 8.3 | yes (3) | 81.5 | 3.4 | 18.5 | 8.2x |
| motor | poor fit / hair | 12.6 | 12.5 | 6.8 | 12.0 | yes (3) | 85.5 | 1.9 | 14.5 | 20.5x |
| compressor | good seal | 22.8 | 23.0 | 0.0 | 0.6 | no | 74.3 | 2.9 | 25.7 | 1.0x |
| compressor | thin glasses temple | 20.7 | 20.8 | 2.2 | 4.3 | yes (3) | 76.5 | 2.8 | 23.5 | 1.7x |
| compressor | thick glasses temple | 18.1 | 18.0 | 4.7 | 8.0 | yes (3) | 80.2 | 1.6 | 19.8 | 3.9x |
| compressor | poor fit / hair | 15.1 | 14.9 | 7.7 | 11.8 | yes (3) | 84.2 | 0.6 | 15.8 | 9.9x |
| pink | good seal | 27.5 | 27.9 | 0.0 | -0.0 | no | 69.2 | 3.2 | 30.7 | 1.0x |
| pink | thin glasses temple | 24.5 | 24.8 | 2.9 | 3.8 | yes (3) | 73.2 | 2.2 | 26.7 | 2.5x |
| pink | thick glasses temple | 21.1 | 21.3 | 6.3 | 7.6 | yes (3) | 77.6 | 1.2 | 22.3 | 6.9x |
| pink | poor fit / hair | 17.2 | 17.4 | 10.3 | 11.4 | yes (3) | 82.2 | 0.5 | 17.7 | 20.2x |
| engine | good seal | 23.9 | 23.2 | 0.0 | 0.3 | no | 75.6 | -1.0 | 23.0 | 1.0x |
| engine | thin glasses temple | 21.7 | 20.8 | 2.2 | 4.1 | yes (3) | 80.0 | -3.1 | 18.6 | 2.7x |
| engine | thick glasses temple | 19.0 | 18.1 | 4.9 | 7.9 | yes (3) | 82.6 | -3.1 | 15.9 | 5.1x |
| engine | poor fit / hair | 15.7 | 15.1 | 8.3 | 11.8 | yes (3) | 85.2 | -2.3 | 13.4 | 9.2x |
| chainsaw | good seal | 26.1 | 26.4 | 0.0 | -0.1 | no | 68.7 | 4.6 | 30.6 | 1.0x |
| chainsaw | thin glasses temple | 22.9 | 23.1 | 3.2 | 3.8 | yes (3) | 73.1 | 3.3 | 26.2 | 2.8x |
| chainsaw | thick glasses temple | 19.4 | 19.7 | 6.6 | 7.6 | yes (3) | 77.6 | 2.2 | 21.7 | 7.9x |
| chainsaw | poor fit / hair | 15.7 | 16.2 | 10.3 | 11.4 | yes (3) | 82.1 | 1.5 | 17.2 | 22.3x |
| hand_saw | good seal | 32.0 | 32.0 | 0.0 | -1.1 | no | 66.9 | 0.4 | 32.4 | 1.0x |
| hand_saw | thin glasses temple | 27.5 | 27.6 | 4.5 | 2.9 | yes (5) | 71.4 | 0.3 | 27.8 | 2.8x |
| hand_saw | thick glasses temple | 22.9 | 23.0 | 9.1 | 7.0 | yes (3) | 76.0 | 0.3 | 23.2 | 8.3x |
| hand_saw | poor fit / hair | 18.2 | 18.3 | 13.8 | 11.0 | yes (3) | 80.8 | 0.3 | 18.5 | 24.8x |
| helicopter | good seal | 22.2 | 23.2 | 0.0 | 0.9 | no | 68.7 | 7.8 | 30.0 | 1.0x |
| helicopter | thin glasses temple | 20.0 | 20.8 | 2.2 | 4.5 | yes (3) | 71.8 | 6.8 | 26.8 | 2.1x |
| helicopter | thick glasses temple | 17.6 | 18.2 | 4.6 | 8.1 | yes (3) | 75.7 | 5.3 | 22.9 | 5.1x |
| helicopter | poor fit / hair | 14.7 | 15.2 | 7.5 | 11.7 | yes (3) | 80.3 | 3.6 | 18.3 | 14.7x |
| train | good seal | 20.7 | 21.4 | 0.0 | 0.8 | no | 70.5 | 7.9 | 28.6 | 1.0x |
| train | thin glasses temple | 18.2 | 18.8 | 2.5 | 4.2 | yes (3) | 74.2 | 6.6 | 24.8 | 2.4x |
| train | thick glasses temple | 15.5 | 16.1 | 5.1 | 7.6 | yes (3) | 78.0 | 5.5 | 21.1 | 5.7x |
| train | poor fit / hair | 12.7 | 13.3 | 8.0 | 11.0 | yes (3) | 82.3 | 4.1 | 16.8 | 15.3x |
| vacuum_cleaner | good seal | 30.3 | 30.5 | 0.0 | 0.1 | no | 65.8 | 3.5 | 33.8 | 1.0x |
| vacuum_cleaner | thin glasses temple | 26.6 | 26.8 | 3.7 | 3.9 | yes (3) | 70.4 | 2.6 | 29.2 | 2.9x |
| vacuum_cleaner | thick glasses temple | 22.6 | 22.7 | 7.7 | 7.7 | yes (3) | 75.2 | 1.9 | 24.4 | 8.7x |
| vacuum_cleaner | poor fit / hair | 18.1 | 18.3 | 12.2 | 11.5 | yes (3) | 80.0 | 1.5 | 19.6 | 26.5x |
| washing_machine | good seal | 25.0 | 25.7 | 0.0 | 0.4 | no | 69.5 | 6.0 | 31.0 | 1.0x |
| washing_machine | thin glasses temple | 22.3 | 22.9 | 2.7 | 4.1 | yes (3) | 73.8 | 4.5 | 26.7 | 2.7x |
| washing_machine | thick glasses temple | 19.2 | 19.7 | 5.8 | 7.9 | yes (3) | 78.2 | 3.1 | 22.3 | 7.5x |
| washing_machine | poor fit / hair | 15.7 | 16.2 | 9.2 | 11.6 | yes (3) | 82.8 | 2.0 | 17.8 | 21.4x |

Levels in dB(A). IL = passive attenuation on that noise (ANC contribution removed); PAR = total protection with ANC. The error mic sits in the cup, not at the eardrum: a fixed per-design offset has to be calibrated on a head-and-torso simulator before these become compliance numbers.

Figure: `seal_monitor.png`.

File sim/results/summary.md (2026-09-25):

# Simulation results

Ambient 100 dB(A) outside the helmet, fs = 32000 Hz, secondary-path low-frequency group delay 9.0 samples. Levels at the ear, last 5 s of a 8 s run.

| Noise | Open ear dB(A) | Passive dB(A) | Passive + ANC dB(A) | ANC adds | Total reduction | Watchdog trips |
| --- | --- | --- | --- | --- | --- | --- |
| motor | 99.9 | 80.5 | 72.1 | 8.4 dB | **27.8 dB** | 0 |
| compressor | 99.9 | 77.0 | 74.0 | 3.0 dB | **25.9 dB** | 0 |
| pink | 99.9 | 72.3 | 69.0 | 3.3 dB | **30.9 dB** | 0 |

## Known limitation: sub-63 Hz rumble

The update is weighted toward 150 Hz-1 kHz, where the A-weighted (hearing-damage) dose is. Energy below 63 Hz is left roughly as the passive cup leaves it:

| Noise | Passive <=63 Hz (dB, unweighted) | Passive + ANC <=63 Hz |
| --- | --- | --- |
| motor | 95.7 | 96.4 |
| compressor | 100.7 | 102.4 |
| pink | 88.3 | 90.7 |

Figures: `paths.png`, `spectra_*.png`, `convergence.png`, `latency_sweep.png`, `robustness.png`.

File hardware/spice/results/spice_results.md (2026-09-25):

# SPICE verification of the analog chain (ngspice)

Generated by `hardware/spice/run_spice.py` from the component values in `hardware/gen/boards.py`. Op-amp: behavioural MCP6022 (A0 110 dB, GBW 10 MHz, 65 deg PM, 8.7 nV/rtHz, rail-to-rail). Amp: behavioural TPA6132A2 with a 0.9 V peak output clamp. Driver: a typical-class 40 mm Thiele-Small model, swept; replace with the chosen driver's measured parameters.

## 1. Mic front ends

| Channel | Gain (V/V) | -3 dB band | Noise, input-referred | Clips at |
| --- | --- | --- | --- | --- |
| REF (outside) | 3.42 | 7.6 Hz - 9.5 kHz | 3.9 uV(A) = 23.8 dB(A) SPL | 31.9 Pa = 124.0 dB peak |
| ERR (in-cup) | 6.84 | 7.6 Hz - 9.5 kHz | 3.4 uV(A) = 22.6 dB(A) SPL | 15.9 Pa = 118.0 dB peak |

- Response matches the simulation's plant (`sim/plant.py`: 10 Hz high-pass, 3rd-order ~10 kHz anti-alias), so the ANC results stand on the real circuit.
- Electronics noise is about the mic's own self-noise (21 dB(A) SPL): fine for ANC at 100 dB(A) and for quiet-room dosimetry.
- **Finding - ear-overload cut-out cannot fire:** the in-cup channel saturates at 15.9 Pa, but the firmware trips at 22.5 Pa (`EAR_OVERLOAD_DB` 118 as a sine peak). Fixed in `firmware/src/app.c`: the threshold is capped below the channel's full scale.

## 2. VMID bias buffer (MCP6022 follower, 10 R + 1 uF)

| Op-amp output R | Isolation R | Loop crossover | Phase margin | 1 mA load step |
| --- | --- | --- | --- | --- |
| 50 R | 10 R | 1679 kHz | 85 deg | 10.0 mV dip |
| 150 R | 10 R | 631 kHz | 87 deg | 10.0 mV dip |
| 400 R | 10 R | 251 kHz | 86 deg | 10.0 mV dip |
| 150 R | 0.1 R | 106 kHz | 4 deg | 1.6 mV dip |
| 150 R | 47 R | 2371 kHz | 84 deg | 46.2 mV dip |

- Stable with the 10 R isolation resistor over the whole plausible output-resistance range (PM >= 85 deg). Without it the 1 uF load leaves 4 deg: ringing. **Keep the 10 R** (the datasheet asks for a series R above ~60 pF).

## 3. DAC reconstruction + coupling into the amp

| Amp input R | Pass band | Group delay @ 1 kHz | @ 200 Hz |
| --- | --- | --- | --- |
| 10 k | 16.6 Hz - 8.7 kHz | 27.5 us | 87.7 us |
| 20 k | 8.3 Hz - 8.7 kHz | 26.3 us | 56.3 us |
| 40 k | 4.2 Hz - 8.7 kHz | 25.6 us | 40.5 us |

- Matches the plant model's 2nd-order 9 kHz reconstruction (~25 us at 1 kHz; about 0.8 sample at 32 kHz). The extra delay at 200 Hz is the 1 uF coupling high-pass - a phase lead the identified secondary-path model absorbs, not added latency.

## 4. Amp + driver + earcup: is there enough anti-noise?

The real-noise study needs ~15 Pa peak at 63 Hz for engine rumble (`sim/results/real_audio.md`).

| Driver | Seal | Pa/V @ 63 Hz | Max clean 63 Hz anti-noise | Meets 15 Pa |
| --- | --- | --- | --- | --- |
| Bl 0.8 Tm, 32 R | good | 14.9 | 13.4 Pa (116.5 dB peak) | **no** |
| Bl 1.2 Tm, 32 R | good | 22.4 | 20.2 Pa (120.1 dB peak) | yes |
| Bl 1.6 Tm, 32 R | good | 29.8 | 26.9 Pa (122.6 dB peak) | yes |
| Bl 0.8 Tm, 16 R | good | 29.9 | 26.9 Pa (122.6 dB peak) | yes |
| Bl 1.2 Tm, 32 R | leaky | 18.3 | 16.5 Pa (118.3 dB peak) | yes |

- **Driver requirement:** >= 17 Pa/V at 63 Hz in the cup (with the TPA6132A2's 0.9 V peak swing). A weak 32 R driver (Bl 0.8) falls short; a **16 R driver** doubles the pressure per volt from the same amp and supply.
- **Finding - the amp clips before the controller's clamp:** at 0 dB amp gain the amp saturates at 0.9 V, i.e. 7.2 controller units (1/`OUT_PA_PER_V` V per unit), while `y_max` is 10 units (set by the DAC range only). The controller's clip detector never saw amp clipping. Fixed in `firmware/src/app.c`: `y_max` is also capped by the amp swing at the selected gain.

Figures: `frontend.png`, `vmid.png`, `recon.png`, `driver.png`.

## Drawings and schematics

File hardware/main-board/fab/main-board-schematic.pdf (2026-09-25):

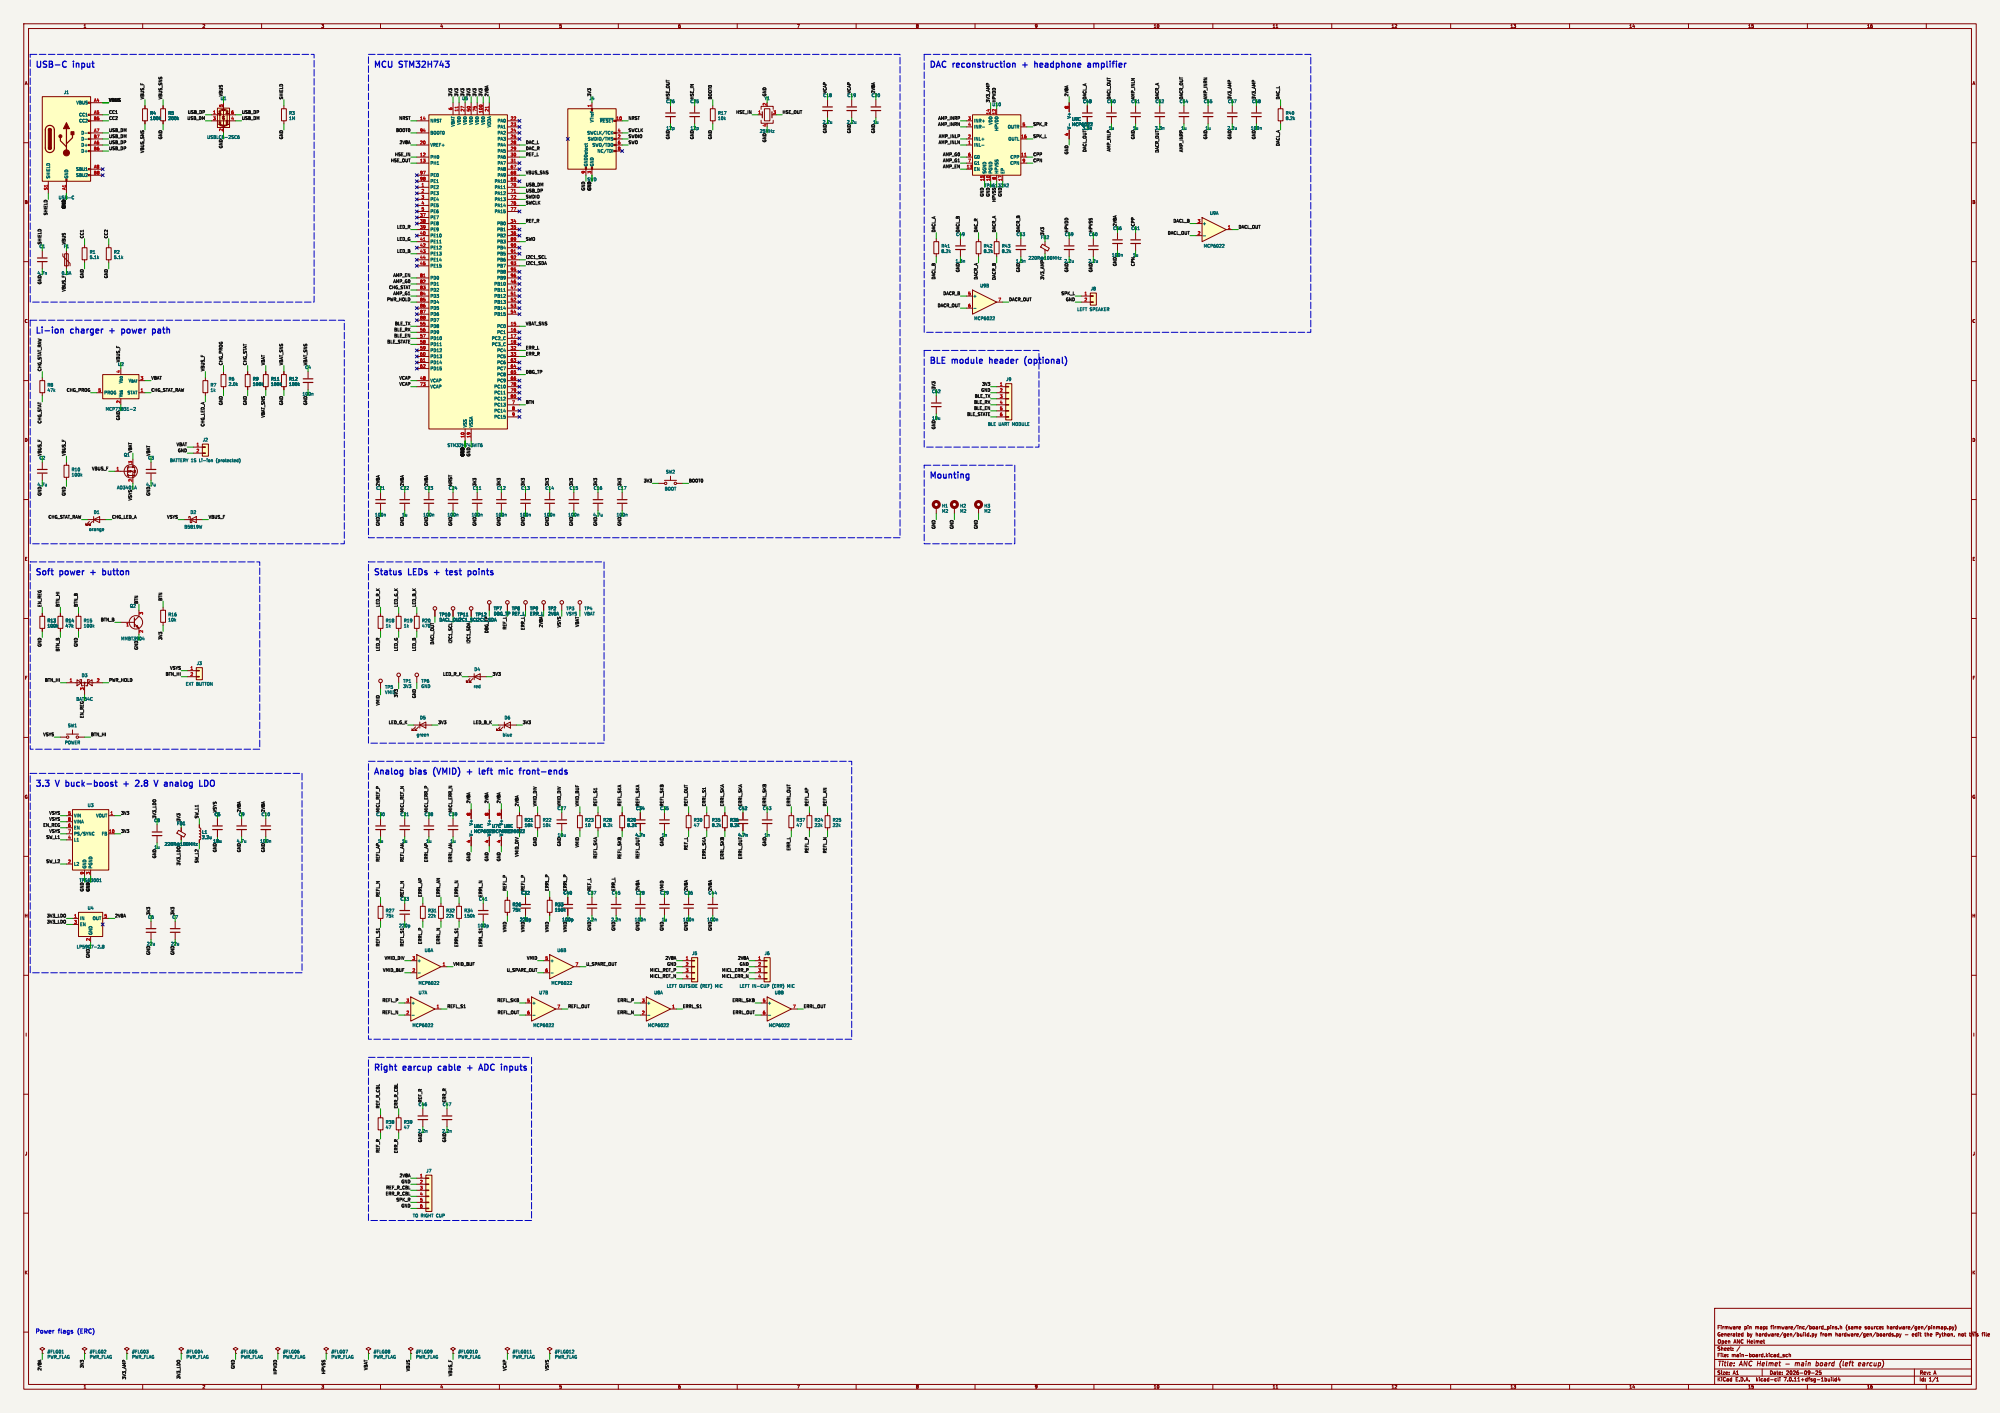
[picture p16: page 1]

BLE module header (optional)

Status LEDs + test points

Analog bias (VMID) + left mic front-ends

LEFT OUTSIDE (REF) MIC

LEFT IN-CUP (ERR) MIC

Right earcup cable + ADC inputs

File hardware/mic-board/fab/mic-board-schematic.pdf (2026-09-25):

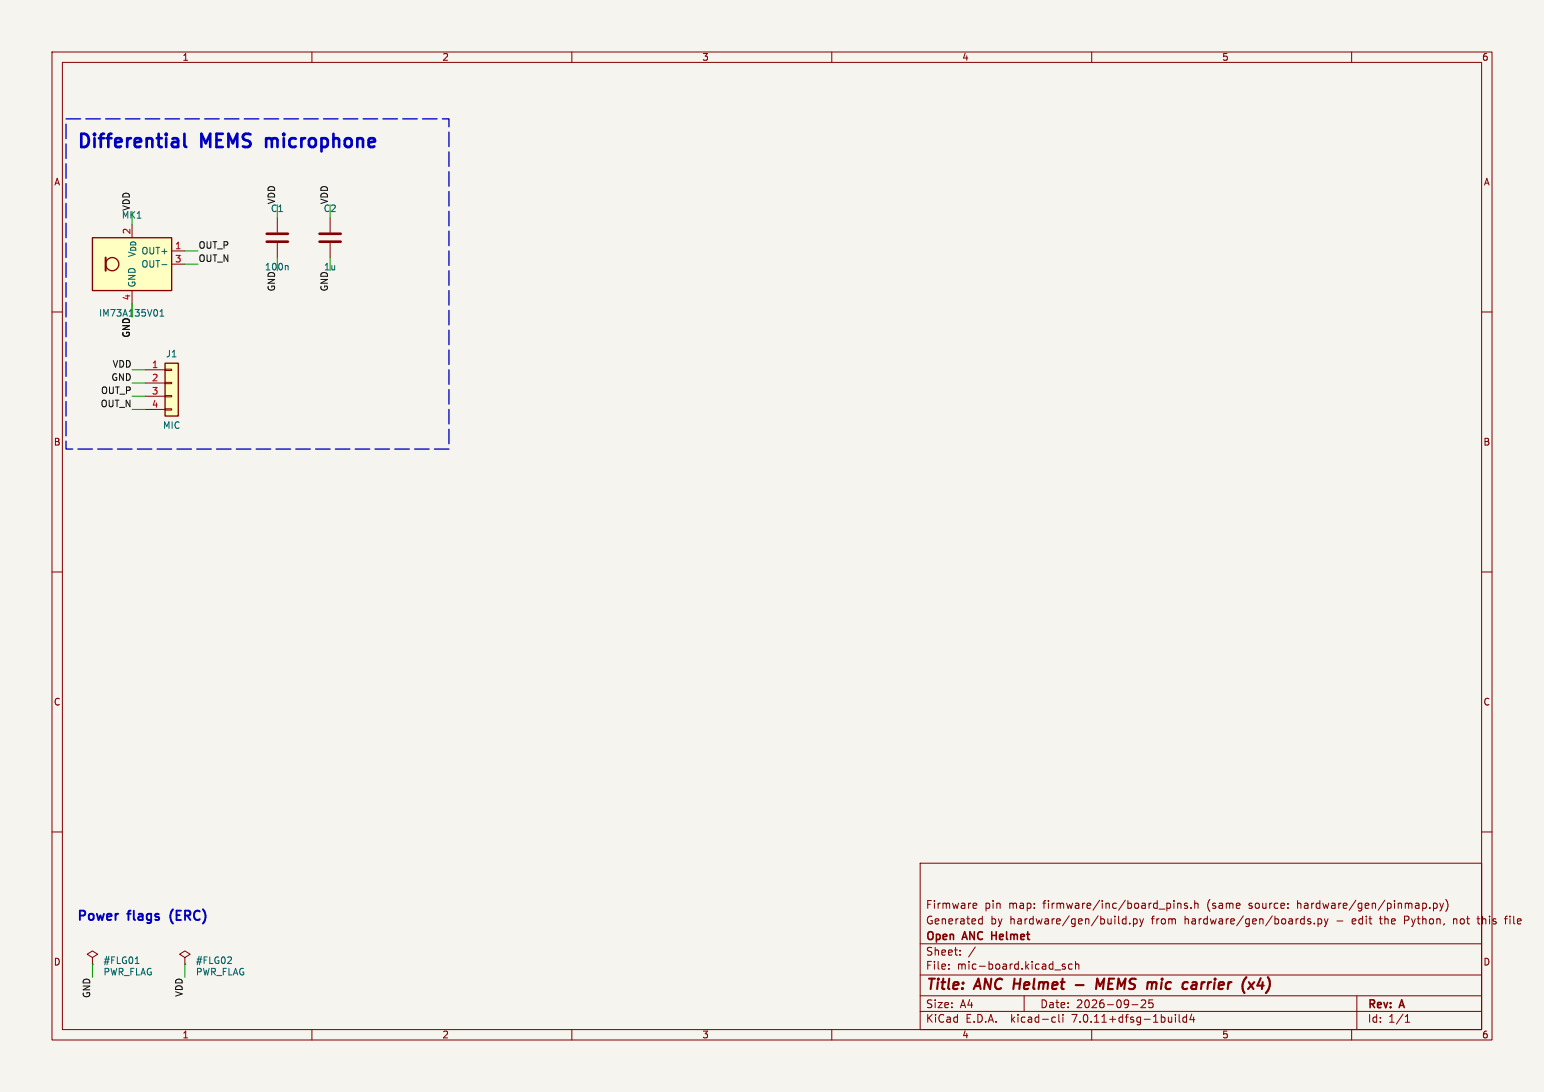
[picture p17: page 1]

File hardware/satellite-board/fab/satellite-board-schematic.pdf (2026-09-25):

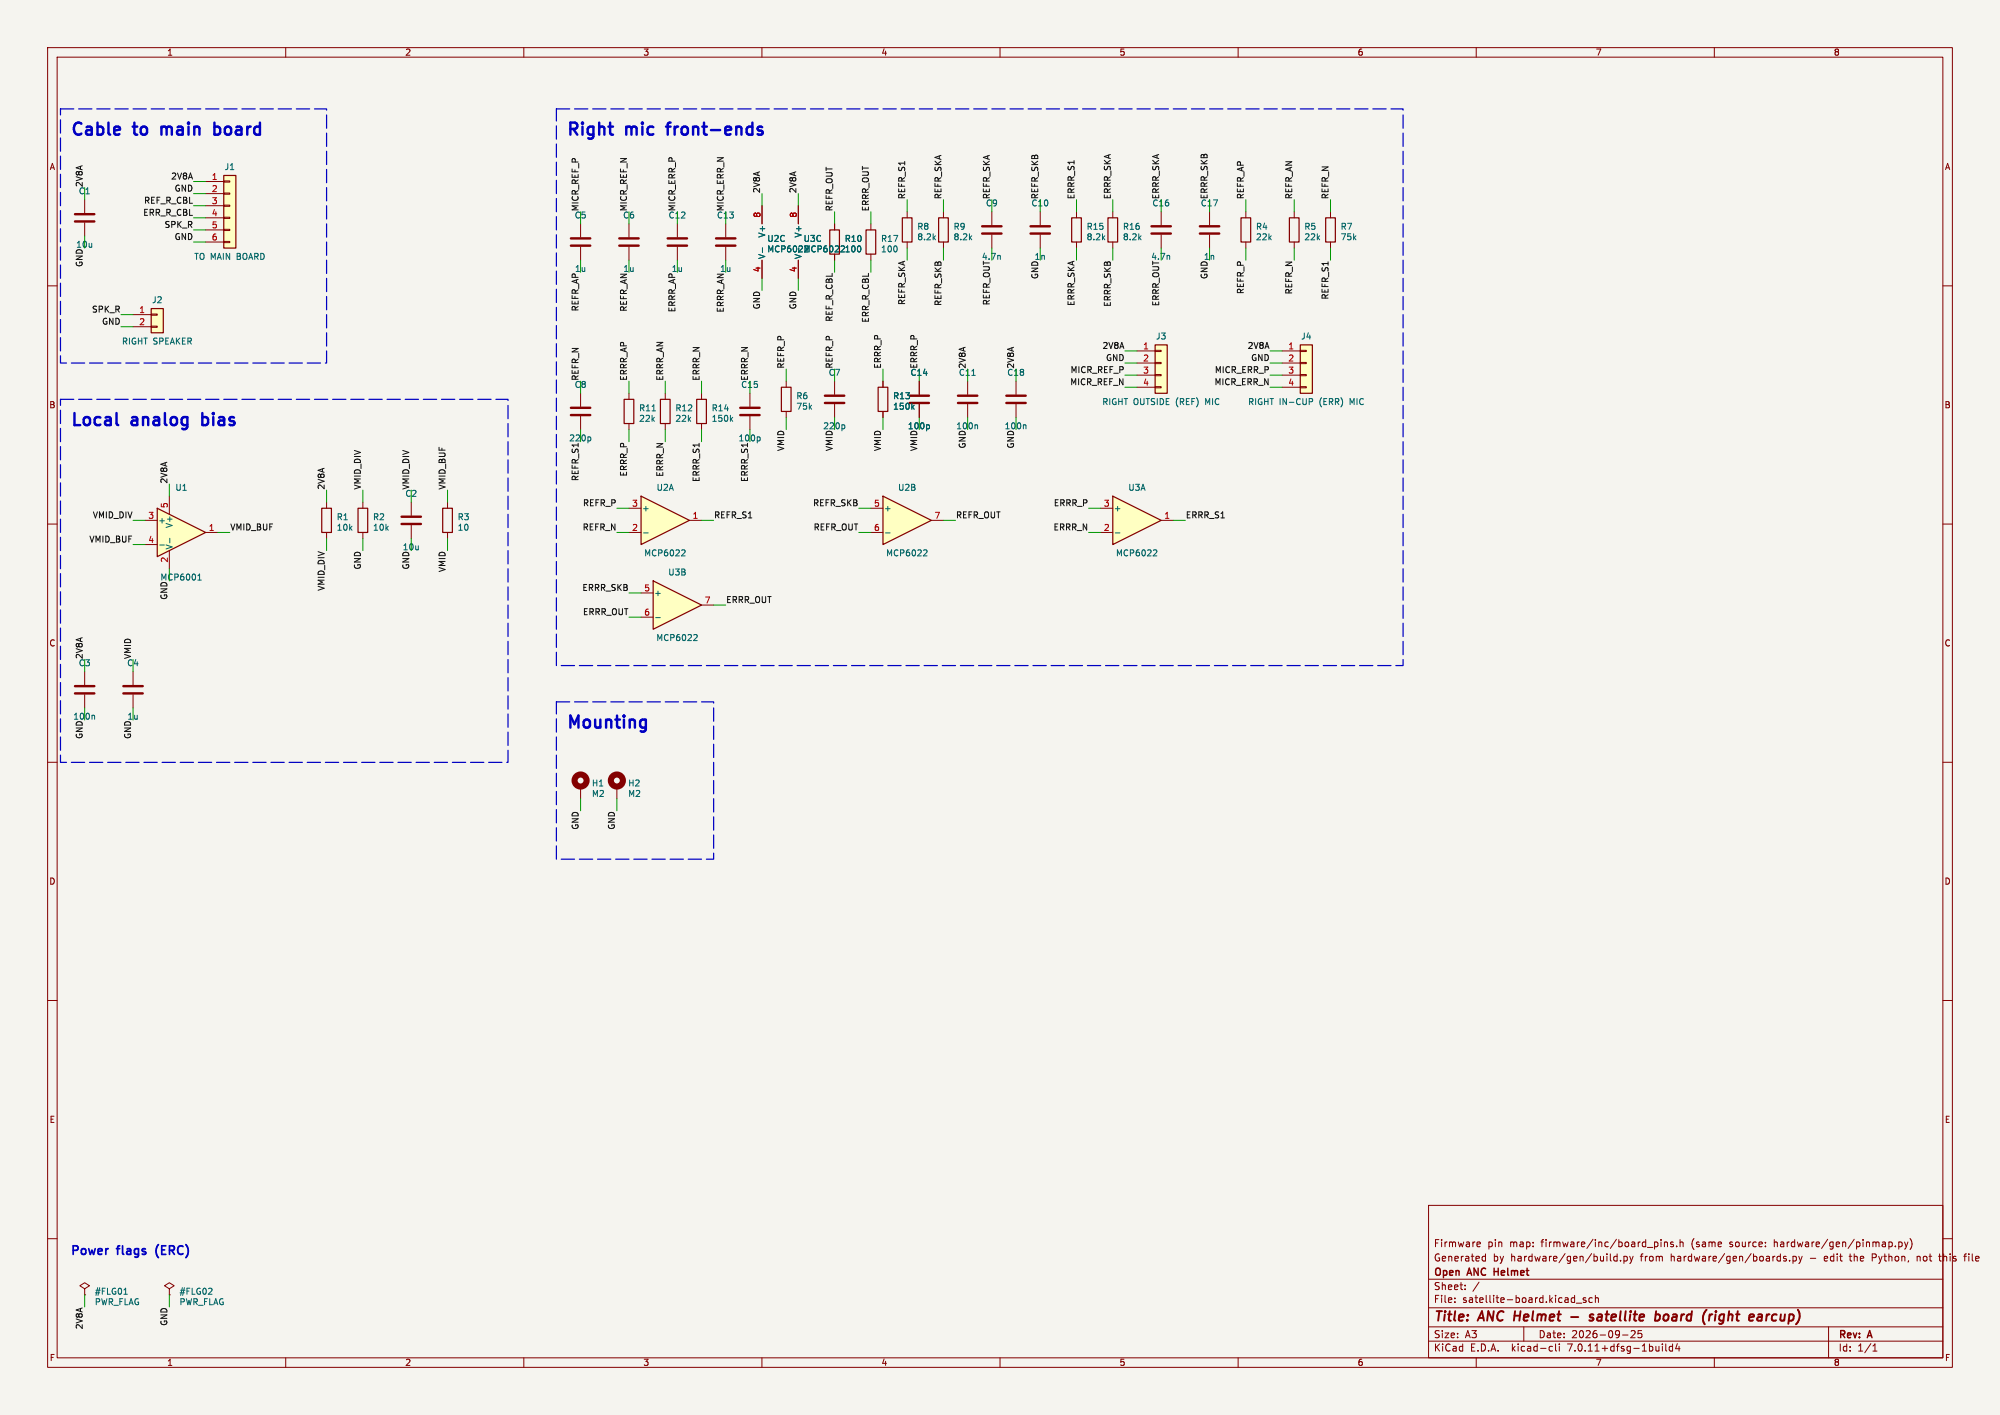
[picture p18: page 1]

Right mic front-ends

J3 RIGHT OUTSIDE (REF) MIC

J4 RIGHT IN-CUP (ERR) MIC

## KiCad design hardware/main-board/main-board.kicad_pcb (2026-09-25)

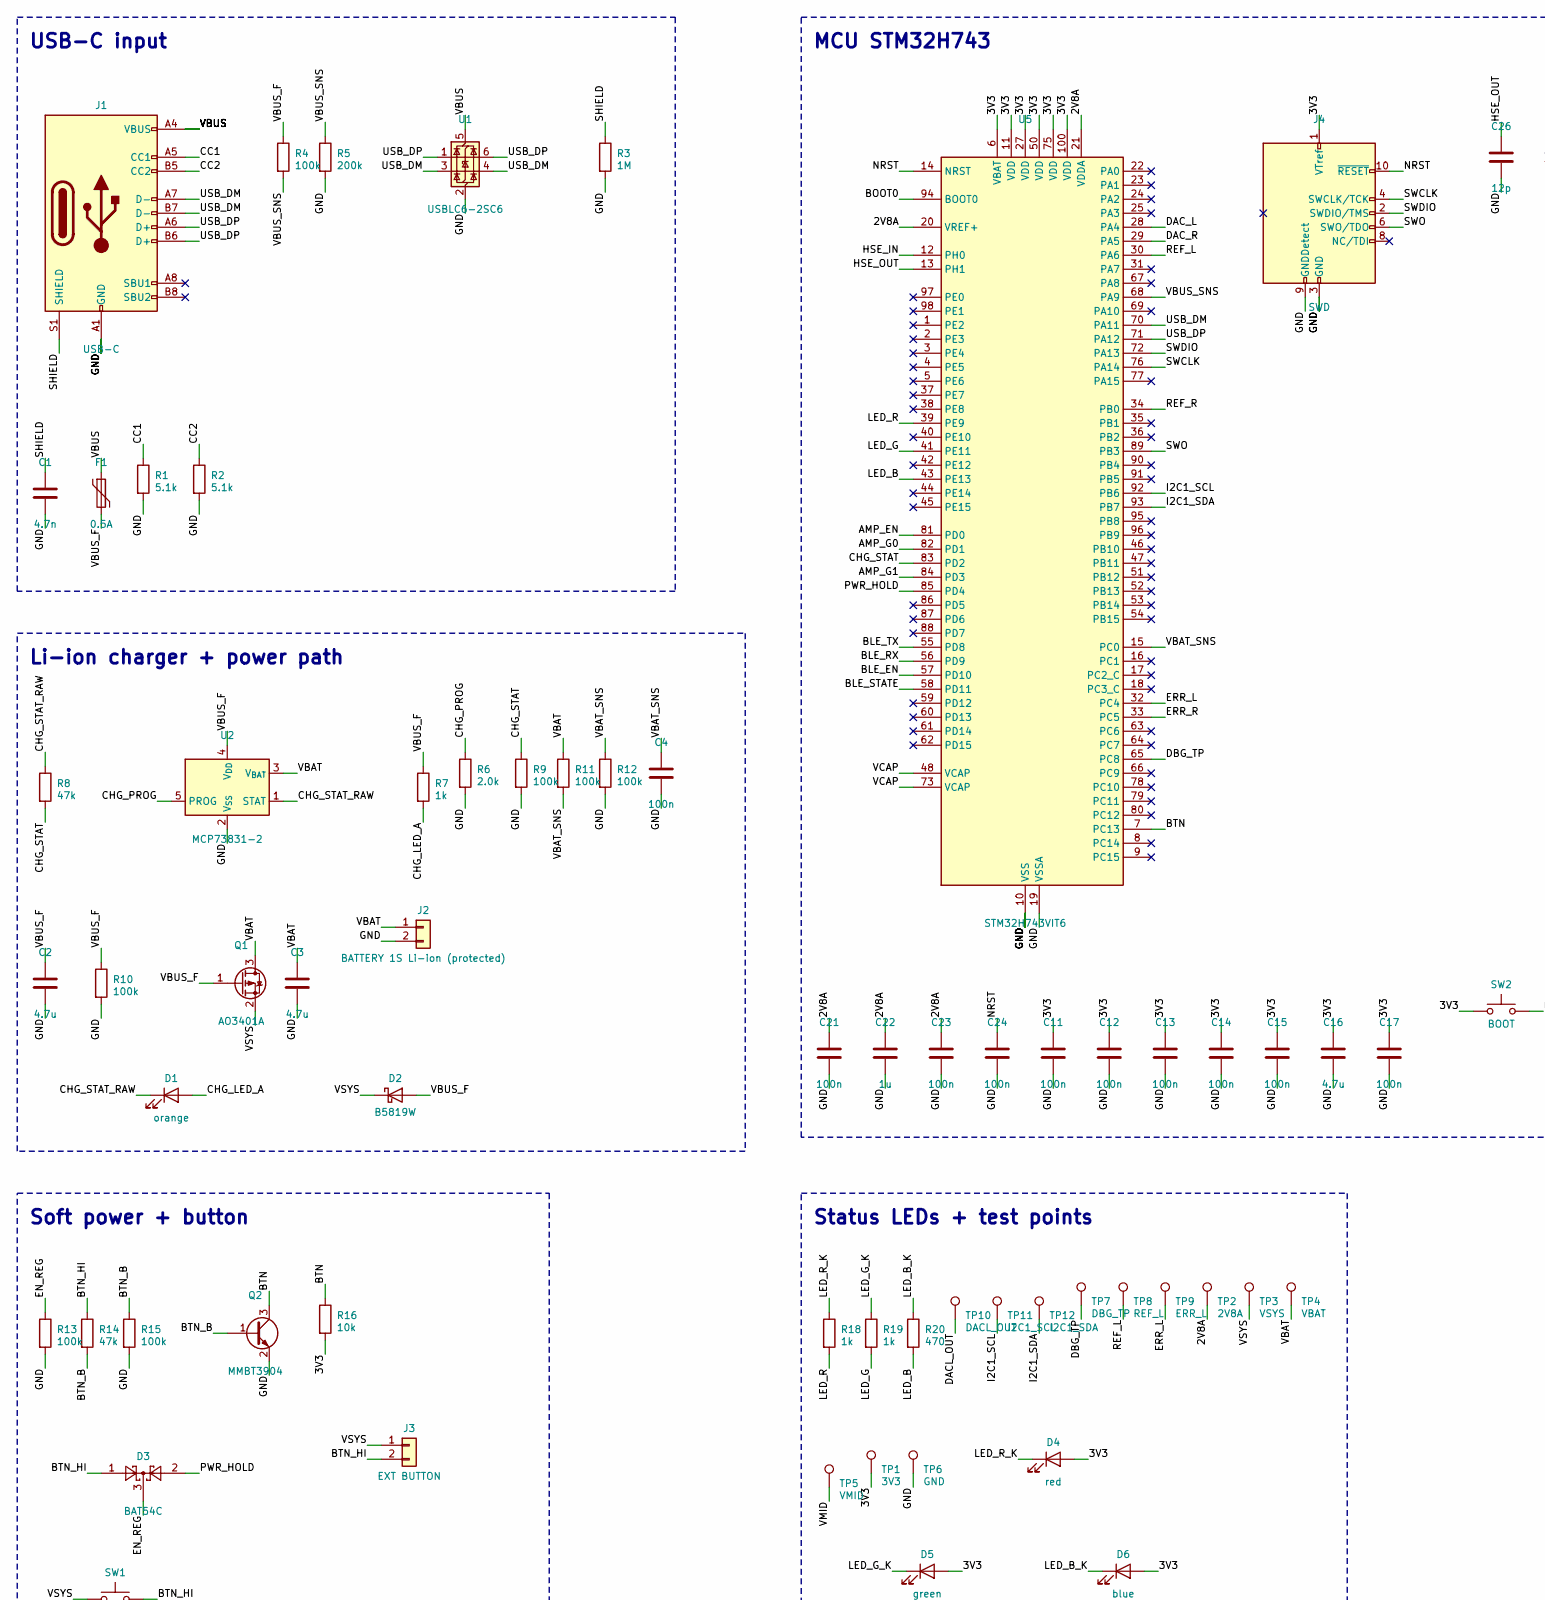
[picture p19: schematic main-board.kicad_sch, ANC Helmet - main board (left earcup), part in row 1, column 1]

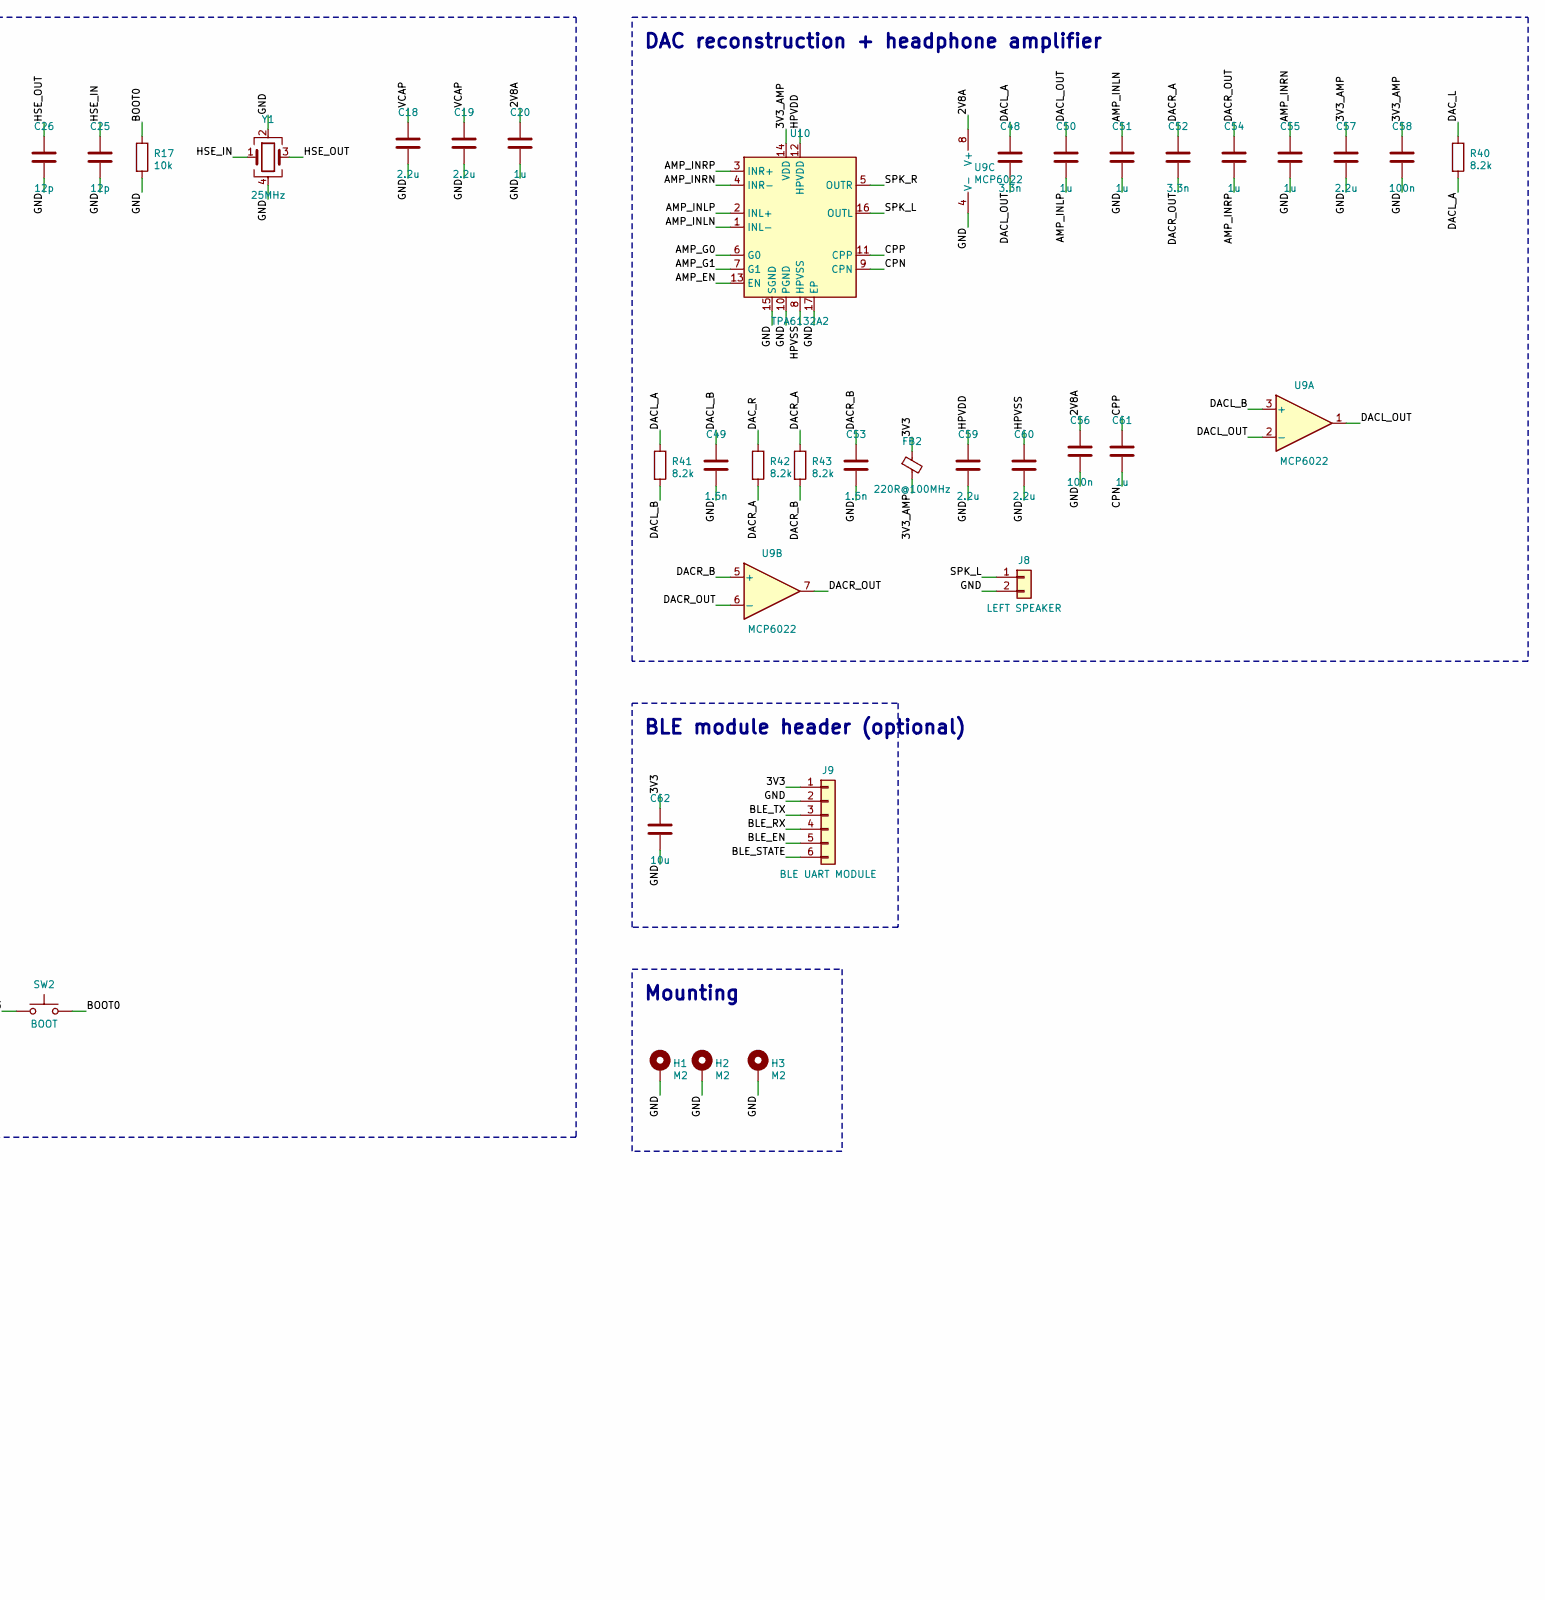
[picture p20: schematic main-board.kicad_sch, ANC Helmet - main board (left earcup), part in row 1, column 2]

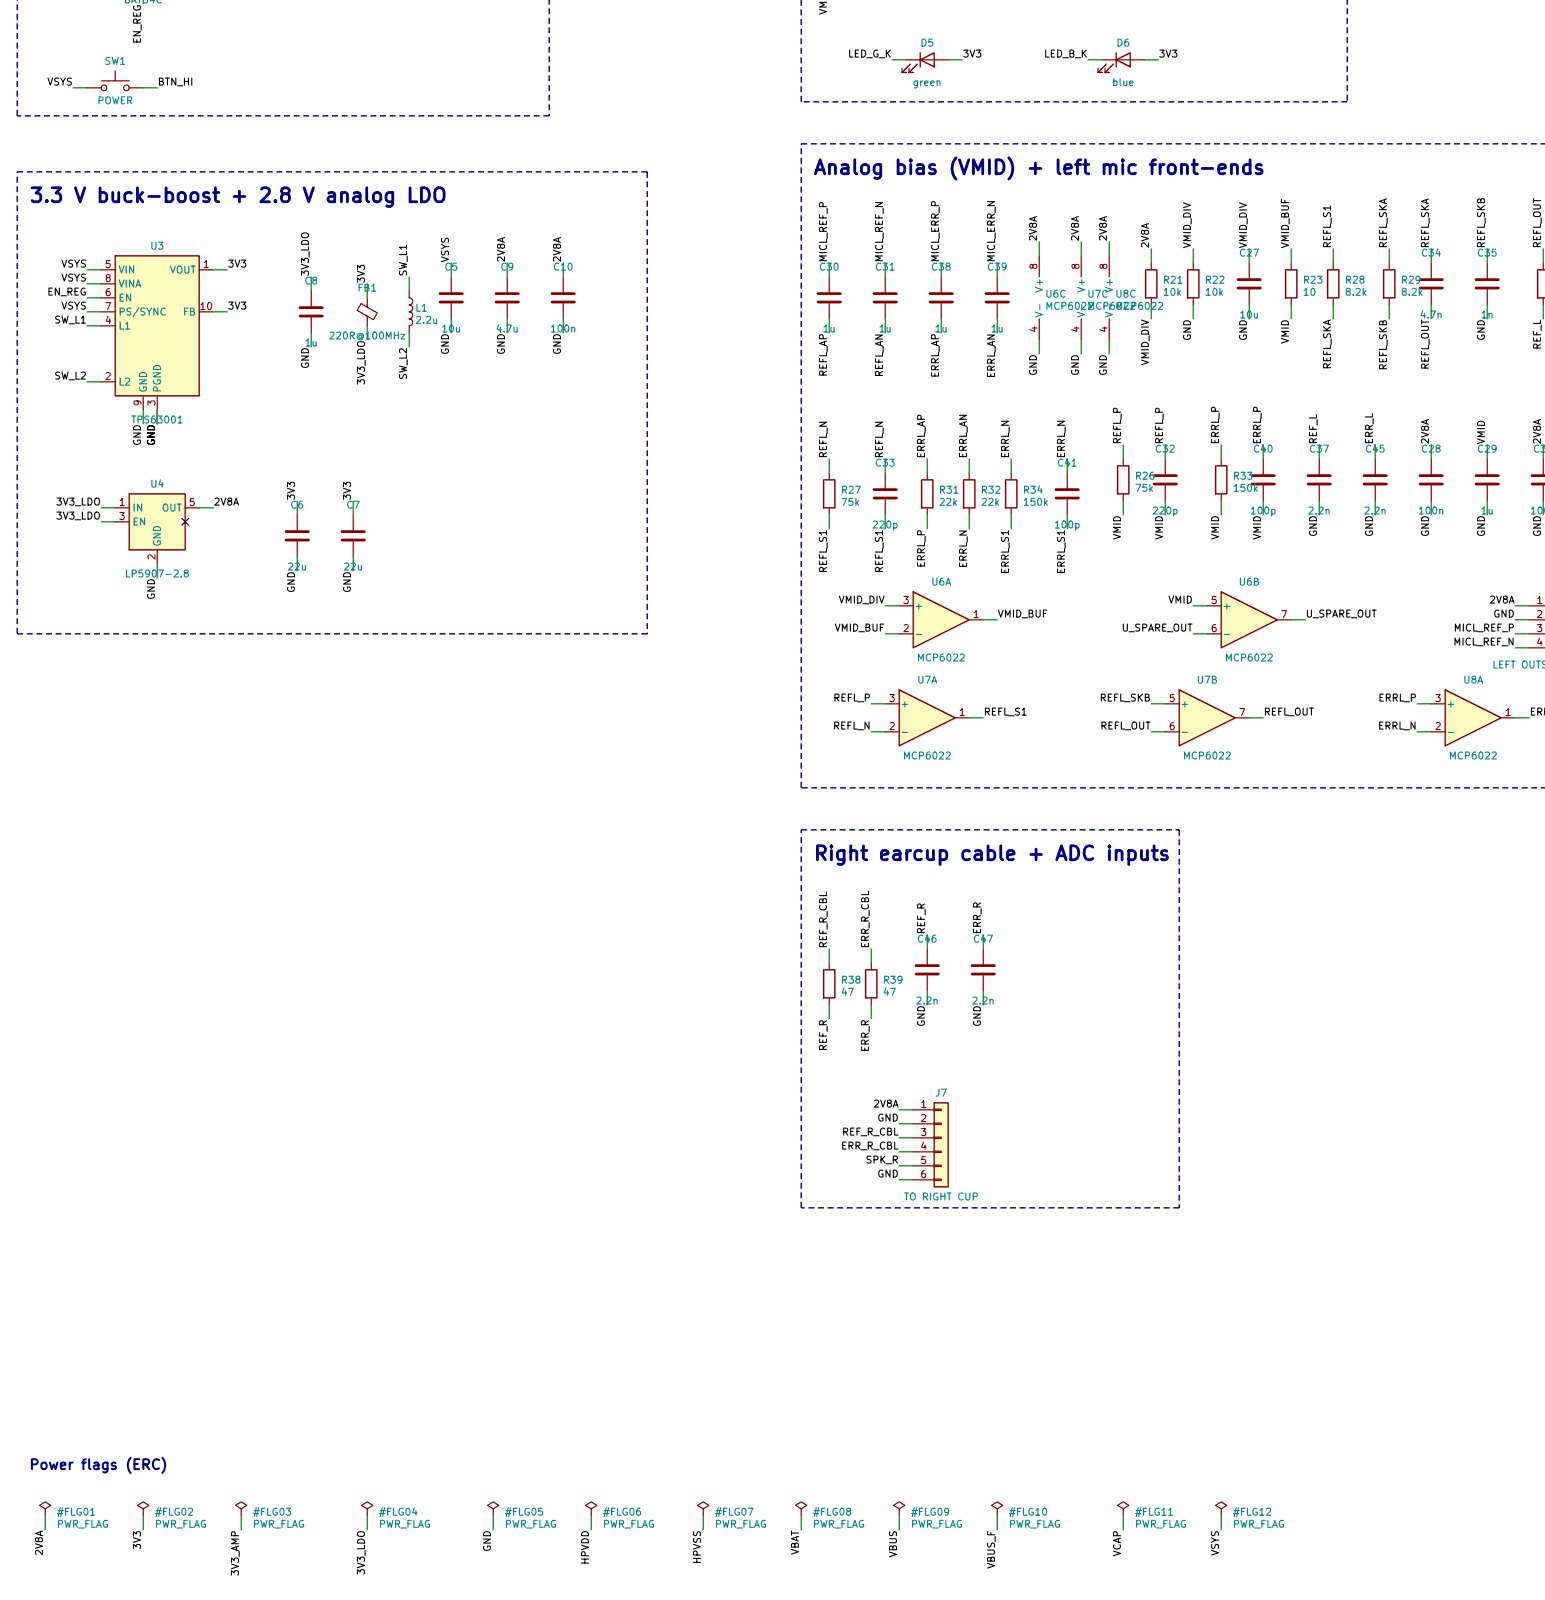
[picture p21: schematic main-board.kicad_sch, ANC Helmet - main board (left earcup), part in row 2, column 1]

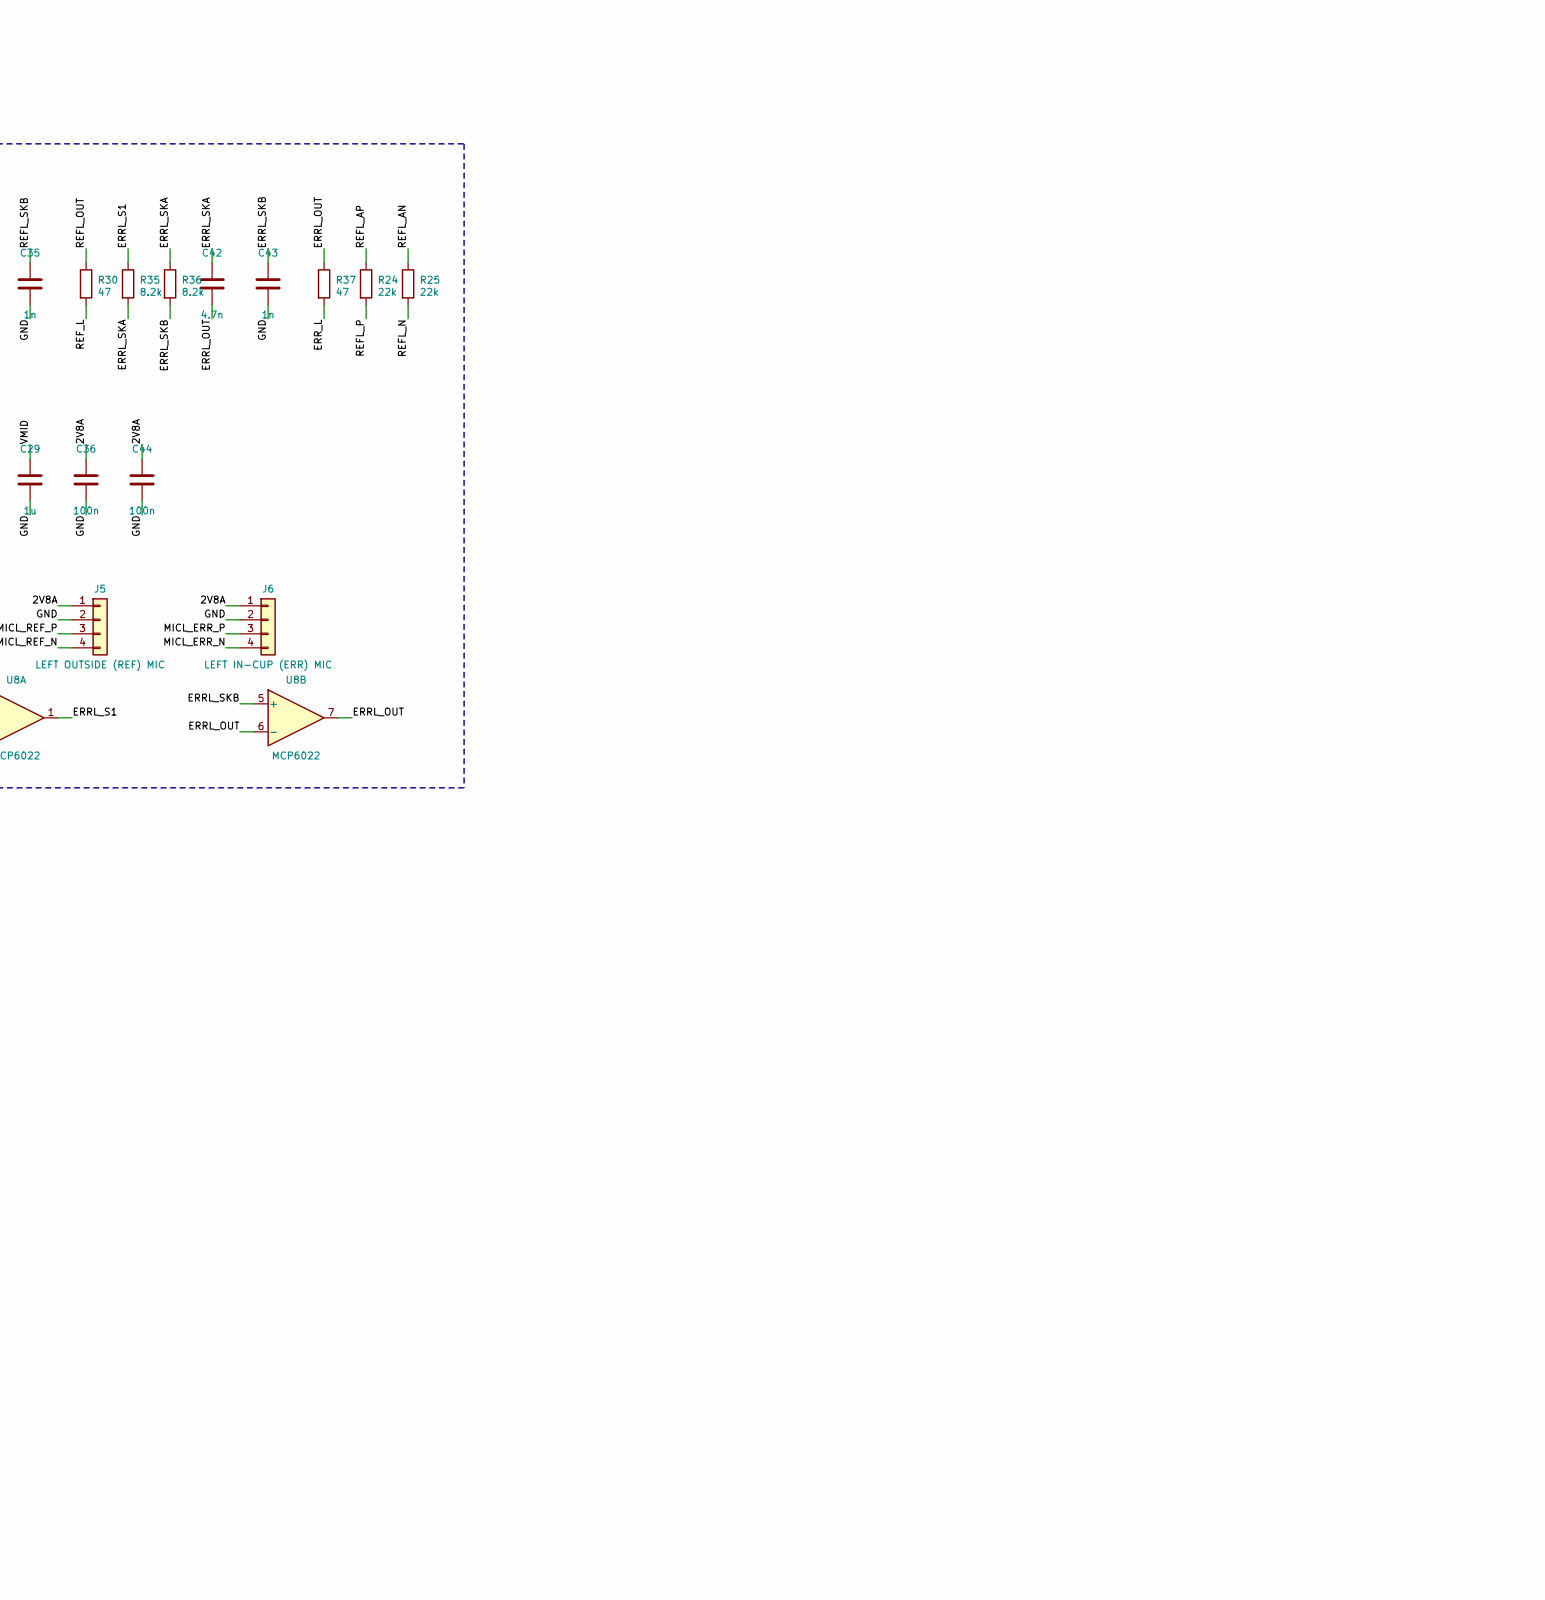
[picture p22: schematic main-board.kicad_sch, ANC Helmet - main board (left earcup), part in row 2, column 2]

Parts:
C1: 4.7n; C_0402_1005Metric; MPN 4.7n X7R 50V
C2, C3: 4.7u; C_0603_1608Metric; MPN 4.7u X5R 10V
C4, C10, C11, C12, C13, C14, C15, C17, C21, C23, C24, C28, C36, C44, C56, C58: 100n; C_0402_1005Metric; MPN 100n X7R
C5: 10u; C_0805_2012Metric; MPN 10u X5R 10V
C6, C7: 22u; C_0805_2012Metric; MPN 22u X5R 10V
C8, C20, C22, C29, C30, C31, C38, C39, C50, C51, C54, C55: 1u; C_0603_1608Metric; MPN 1u X7R
C9: 4.7u; C_0603_1608Metric; MPN 4.7u X5R
C16: 4.7u; C_0603_1608Metric; MPN 4.7u X7R
C18, C19: 2.2u; C_0603_1608Metric; MPN 2.2u X7R
C25, C26: 12p; C_0402_1005Metric; MPN 12p C0G
C27, C62: 10u; C_0805_2012Metric; MPN 10u X5R
C32, C33: 220p; C_0402_1005Metric; MPN 220p C0G
C34, C42: 4.7n; C_0603_1608Metric; MPN 4.7n C0G
C35, C43: 1n; C_0402_1005Metric; MPN 1n C0G
C37, C45, C46, C47: 2.2n; C_0402_1005Metric; MPN 2.2n C0G
C40, C41: 100p; C_0402_1005Metric; MPN 100p C0G
C48, C52: 3.3n; C_0603_1608Metric; MPN 3.3n C0G
C49, C53: 1.5n; C_0402_1005Metric; MPN 1.5n C0G
C57, C59, C60: 2.2u; C_0603_1608Metric; MPN 2.2u X5R
C61: 1u; C_0603_1608Metric; MPN 1u X5R
D1: orange; LED_0603_1608Metric; MPN 0603 orange LED
D2: B5819W; D_SOD-123; MPN B5819W
D3: BAT54C; SOT-23; MPN BAT54C
D4: red; LED_0603_1608Metric; MPN 0603 red LED
D5: green; LED_0603_1608Metric; MPN 0603 green LED
D6: blue; LED_0603_1608Metric; MPN 0603 blue LED
F1: 0.5A; Fuse_1206_3216Metric; MPN Littelfuse 1206L050YR
FB1, FB2: 220R@100MHz; L_0603_1608Metric; MPN BLM18PG221SN1D
H1, H2, H3: M2; MountingHole_2.2mm_M2_Pad_Via
J1: USB-C; USB_C_Receptacle_HRO_TYPE-C-31-M-12; MPN HRO TYPE-C-31-M-12
J2: BATTERY 1S Li-ion (protected); JST_PH_S2B-PH-SM4-TB_1x02-1MP_P2.00mm_Horizontal; MPN JST S2B-PH-SM4-TB
J3: EXT BUTTON; JST_SH_SM02B-SRSS-TB_1x02-1MP_P1.00mm_Horizontal; MPN JST SM02B-SRSS-TB
J4: SWD; PinHeader_2x05_P1.27mm_Vertical_SMD; MPN Cortex debug 2x5 1.27 mm SMD
J5: LEFT OUTSIDE (REF) MIC; JST_SH_SM04B-SRSS-TB_1x04-1MP_P1.00mm_Horizontal; MPN JST SM04B-SRSS-TB
J6: LEFT IN-CUP (ERR) MIC; JST_SH_SM04B-SRSS-TB_1x04-1MP_P1.00mm_Horizontal; MPN JST SM04B-SRSS-TB
J7: TO RIGHT CUP; JST_SH_SM06B-SRSS-TB_1x06-1MP_P1.00mm_Horizontal; MPN JST SM06B-SRSS-TB
J8: LEFT SPEAKER; JST_SH_SM02B-SRSS-TB_1x02-1MP_P1.00mm_Horizontal; MPN JST SM02B-SRSS-TB
J9: BLE UART MODULE; JST_SH_SM06B-SRSS-TB_1x06-1MP_P1.00mm_Horizontal; MPN JST SM06B-SRSS-TB
L1: 2.2u; L_Changjiang_FNR3015S; MPN 2.2 uH >=1.5 A shielded 3x3 (e.g. TDK V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
Q1: AO3401A; SOT-23; MPN AO3401A
Q2: MMBT3904; SOT-23; MPN MMBT3904
R1, R2: 5.1k; R_0402_1005Metric; MPN 5.1k 1% 02_1
R3: 1M; R_0402_1005Metric; MPN 1M 1% 02_1
R4, R9, R10, R11, R12, R13, R15: 100k; R_0402_1005Metric; MPN 100k 1% 02_1
R5: 200k; R_0402_1005Metric; MPN 200k 1% 02_1
R6: 2.0k; R_0402_1005Metric; MPN 2.0k 1% 02_1
R7, R18, R19: 1k; R_0402_1005Metric; MPN 1k 1% 02_1
R8, R14: 47k; R_0402_1005Metric; MPN 47k 1% 02_1
R16, R17, R21, R22: 10k; R_0402_1005Metric; MPN 10k 1% 02_1
R20: 470; R_0402_1005Metric; MPN 470 1% 02_1
R23: 10; R_0402_1005Metric; MPN 10 1% 02_1
R24, R25, R31, R32: 22k; R_0402_1005Metric; MPN 22k 1% 02_1
R26, R27: 75k; R_0402_1005Metric; MPN 75k 1% 02_1
R28, R29, R35, R36, R40, R41, R42, R43: 8.2k; R_0402_1005Metric; MPN 8.2k 1% 02_1
R30, R37, R38, R39: 47; R_0402_1005Metric; MPN 47 1% 02_1
R33, R34: 150k; R_0402_1005Metric; MPN 150k 1% 02_1
SW1: POWER; SW_SPST_PTS810; MPN C&K PTS810 SJM 250 SMTR LFS
SW2: BOOT; SW_SPST_PTS810; MPN C&K PTS810 SJM 250 SMTR LFS
TP1: 3V3; TestPoint_Pad_D1.0mm
TP2: 2V8A; TestPoint_Pad_D1.0mm
TP3: VSYS; TestPoint_Pad_D1.0mm
TP4: VBAT; TestPoint_Pad_D1.0mm
TP5: VMID; TestPoint_Pad_D1.0mm
TP6: GND; TestPoint_Pad_D1.0mm
TP7: DBG_TP; TestPoint_Pad_D1.0mm
TP8: REF_L; TestPoint_Pad_D1.0mm
TP9: ERR_L; TestPoint_Pad_D1.0mm
TP10: DACL_OUT; TestPoint_Pad_D1.0mm
TP11: I2C1_SCL; TestPoint_Pad_D1.0mm
TP12: I2C1_SDA; TestPoint_Pad_D1.0mm
U1: USBLC6-2SC6; SOT-23-6; MPN USBLC6-2SC6
U2: MCP73831-2; SOT-23-5; MPN MCP73831T-2ACI/OT
U3: TPS63001; Texas_DRC0010J_ThermalVias; MPN TPS63001DRCR
U4: LP5907-2.8; SOT-23-5; MPN LP5907MFX-2.8/NOPB
U5: STM32H743VIT6; LQFP-100_14x14mm_P0.5mm; MPN STM32H743VIT6
U6, U7, U8, U9: MCP6022; TSSOP-8_4.4x3mm_P0.65mm; MPN MCP6022-I/ST
U10: TPA6132A2; WQFN-16-1EP_3x3mm_P0.5mm_EP1.6x1.6mm_ThermalVias; MPN TPA6132A2RTER
Y1: 25MHz; Crystal_SMD_3225-4Pin_3.2x2.5mm; MPN 25 MHz 3225 CL=10pF +-20ppm (e.g. Abrac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

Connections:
2V8A: C9.1, C10.1, C20.1, C21.1, C22.1, C23.1, C28.1, C36.1, C44.1, C56.1, J5.1, J6.1, J7.1, R21.1, TP2.1, U4.5 (OUT), U5.20 (VREF+), U5.21 (VDDA), U6.8 (V+), U7.8 (V+), U8.8 (V+), U9.8 (V+)
3V3: C6.1, C7.1, C11.1, C12.1, C13.1, C14.1, C15.1, C16.1, C17.1, C62.1, D4.2 (A), D5.2 (A), D6.2 (A), FB1.1, FB2.1, J4.1 (VTref), J9.1, R16.2, SW2.1, TP1.1, U3.1 (VOUT), U3.10 (FB), U5.6 (VBAT), U5.11 (VDD), U5.27 (VDD), U5.50 (VDD), U5.75 (VDD), U5.100 (VDD)
3V3_AMP: C57.1, C58.1, FB2.2, U10.14 (VDD)
3V3_LDO: C8.1, FB1.2, U4.1 (IN), U4.3 (EN)
AMP_EN: U5.81 (PD0), U10.13 (EN)
AMP_G0: U5.82 (PD1), U10.6 (G0)
AMP_G1: U5.84 (PD3), U10.7 (G1)
AMP_INLN: C51.1, U10.1 (INL-)
AMP_INLP: C50.2, U10.2 (INL+)
AMP_INRN: C55.1, U10.4 (INR-)
AMP_INRP: C54.2, U10.3 (INR+)
BLE_EN: J9.5, U5.57 (PD10)
BLE_RX: J9.4, U5.56 (PD9)
BLE_STATE: J9.6, U5.58 (PD11)
BLE_TX: J9.3, U5.55 (PD8)
BOOT0: R17.1, SW2.2, U5.94 (BOOT0)
BTN: Q2.3 (C), R16.1, U5.7 (PC13)
BTN_B: Q2.1 (B), R14.2, R15.1
BTN_HI: D3.1, J3.2, R14.1, SW1.2
CC1: J1.A5 (CC1), R1.1
CC2: J1.B5 (CC2), R2.1
CHG_LED_A: D1.2 (A), R7.2
CHG_PROG: R6.1, U2.5 (PROG)
CHG_STAT: R8.2, R9.1, U5.83 (PD2)
CHG_STAT_RAW: D1.1 (K), R8.1, U2.1 (STAT)
CPN: C61.2, U10.9 (CPN)
CPP: C61.1, U10.11 (CPP)
DACL_A: C48.1, R40.2, R41.1
DACL_B: C49.1, R41.2, U9.3 (+)
DACL_OUT: C48.2, C50.1, TP10.1, U9.1, U9.2 (-)
DACR_A: C52.1, R42.2, R43.1
DACR_B: C53.1, R43.2, U9.5 (+)
DACR_OUT: C52.2, C54.1, U9.6 (-), U9.7
DAC_L: R40.1, U5.28 (PA4)
DAC_R: R42.1, U5.29 (PA5)
DBG_TP: TP7.1, U5.65 (PC8)
EN_REG: D3.3, R13.1, U3.6 (EN)
ERRL_AN: C39.2, R32.1
ERRL_AP: C38.2, R31.1
ERRL_N: C41.1, R32.2, R34.1, U8.2 (-)
ERRL_OUT: C42.2, R37.1, U8.6 (-), U8.7
ERRL_P: C40.1, R31.2, R33.1, U8.3 (+)
ERRL_S1: C41.2, R34.2, R35.1, U8.1
ERRL_SKA: C42.1, R35.2, R36.1
ERRL_SKB: C43.1, R36.2, U8.5 (+)
ERR_L: C45.1, R37.2, TP9.1, U5.32 (PC4)
ERR_R: C47.1, R39.2, U5.33 (PC5)
ERR_R_CBL: J7.4, R39.1
GND: C1.2, C2.2, C3.2, C4.2, C5.2, C6.2, C7.2, C8.2, C9.2, C10.2, C11.2, C12.2, C13.2, C14.2, C15.2, C16.2, C17.2, C18.2, C19.2, C20.2, C21.2, C22.2, C23.2, C24.2, C25.2, C26.2, C27.2, C28.2, C29.2, C35.2, C36.2, C37.2, C43.2, C44.2, C45.2, C46.2, C47.2, C49.2, C51.2, C53.2, C55.2, C56.2, C57.2, C58.2, C59.2, C60.2, C62.2, H1.1, H2.1, H3.1, J1.A1 (GND), J1.A12 (GND), J1.B1 (GND), J1.B12 (GND), J2.2, J4.3 (GND), J4.5 (GND), J4.9 (GNDDetect), J5.2, J6.2, J7.2, J7.6, J8.2, J9.2, Q2.2 (E), R1.2, R2.2, R3.2, R5.2, R6.2, R9.2, R10.2, R12.2, R13.2, R15.2, R17.2, R22.2, TP6.1, U1.2 (GND), U2.2 (V_{SS}), U3.3 (PGND), U3.9 (GND), U3.11 (PGND), U4.2 (GND), U5.10 (VSS), U5.19 (VSSA), U5.26 (VSS), U5.49 (VSS), U5.74 (VSS), U5.99 (VSS), U6.4 (V-), U7.4 (V-), U8.4 (V-), U9.4 (V-), U10.10 (PGND), U10.15 (SGND), U10.17 (EP), Y1.2, Y1.4
HPVDD: C59.1, U10.12 (HPVDD)
HPVSS: C60.1, U10.8 (HPVSS)
HSE_IN: C25.1, U5.12 (PH0), Y1.1
HSE_OUT: C26.1, U5.13 (PH1), Y1.3
I2C1_SCL: TP11.1, U5.92 (PB6)
I2C1_SDA: TP12.1, U5.93 (PB7)
LED_B: R20.2, U5.43 (PE13)
LED_B_K: D6.1 (K), R20.1
LED_G: R19.2, U5.41 (PE11)
LED_G_K: D5.1 (K), R19.1
LED_R: R18.2, U5.39 (PE9)
LED_R_K: D4.1 (K), R18.1
MICL_ERR_N: C39.1, J6.4
MICL_ERR_P: C38.1, J6.3
MICL_REF_N: C31.1, J5.4
MICL_REF_P: C30.1, J5.3
NRST: C24.1, J4.10 (~RESET), U5.14 (NRST)
PWR_HOLD: D3.2, U5.85 (PD4)
REFL_AN: C31.2, R25.1
REFL_AP: C30.2, R24.1
REFL_N: C33.1, R25.2, R27.1, U7.2 (-)
REFL_OUT: C34.2, R30.1, U7.6 (-), U7.7
REFL_P: C32.1, R24.2, R26.1, U7.3 (+)
REFL_S1: C33.2, R27.2, R28.1, U7.1
REFL_SKA: C34.1, R28.2, R29.1
REFL_SKB: C35.1, R29.2, U7.5 (+)
REF_L: C37.1, R30.2, TP8.1, U5.30 (PA6)
REF_R: C46.1, R38.2, U5.34 (PB0)
REF_R_CBL: J7.3, R38.1
SHIELD: C1.1, J1.S1 (SHIELD), R3.1
SPK_L: J8.1, U10.16 (OUTL)
SPK_R: J7.5, U10.5 (OUTR)
SWCLK: J4.4 (SWCLK/TCK), U5.76 (PA14)
SWDIO: J4.2 (SWDIO/TMS), U5.72 (PA13)
SWO: J4.6 (SWO/TDO), U5.89 (PB3)
SW_L1: L1.1, U3.4 (L1)
SW_L2: L1.2, U3.2 (L2)
USB_DM: J1.A7 (D-), J1.B7 (D-), U1.3 (I/O2), U1.4 (I/O2), U5.70 (PA11)
USB_DP: J1.A6 (D+), J1.B6 (D+), U1.1 (I/O1), U1.6 (I/O1), U5.71 (PA12)
U_SPARE_OUT: U6.6 (-), U6.7
VBAT: C3.1, J2.1, Q1.3 (D), R11.1, TP4.1, U2.3 (V_{BAT})
VBAT_SNS: C4.1, R11.2, R12.1, U5.15 (PC0)
VBUS: F1.1, J1.A4 (VBUS), J1.A9 (VBUS), J1.B4 (VBUS), J1.B9 (VBUS), U1.5 (VBUS)
VBUS_F: C2.1, D2.2 (A), F1.2, Q1.1 (G), R4.1, R7.1, R10.1, U2.4 (V_{DD})
VBUS_SNS: R4.2, R5.1, U5.68 (PA9)
VCAP: C18.1, C19.1, U5.48 (VCAP), U5.73 (VCAP)
VMID: C29.1, C32.2, C40.2, R23.2, R26.2, R33.2, TP5.1, U6.5 (+)
VMID_BUF: R23.1, U6.1, U6.2 (-)
VMID_DIV: C27.1, R21.2, R22.1, U6.3 (+)
VSYS: C5.1, D2.1 (K), J3.1, Q1.2 (S), SW1.1, TP3.1, U3.5 (VIN), U3.7 (PS/SYNC), U3.8 (VINA)

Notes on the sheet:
USB-C input
Li-ion charger + power path
Soft power + button
3.3 V buck-boost + 2.8 V analog LDO
MCU STM32H743
Status LEDs + test points
Analog bias (VMID) + left mic front-ends
Right earcup cable + ADC inputs
DAC reconstruction + headphone amplifier
BLE module header (optional)
Mounting
Power flags (ERC)

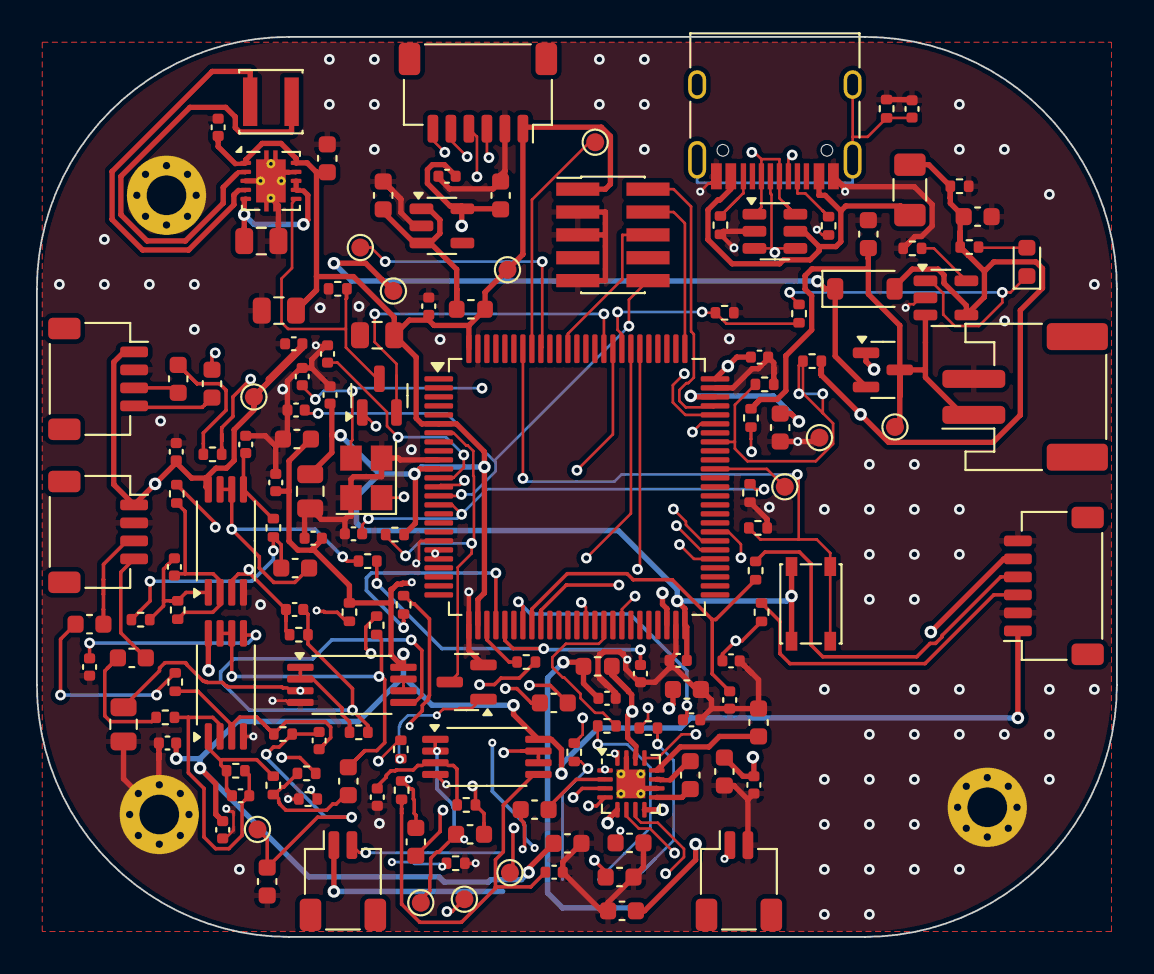
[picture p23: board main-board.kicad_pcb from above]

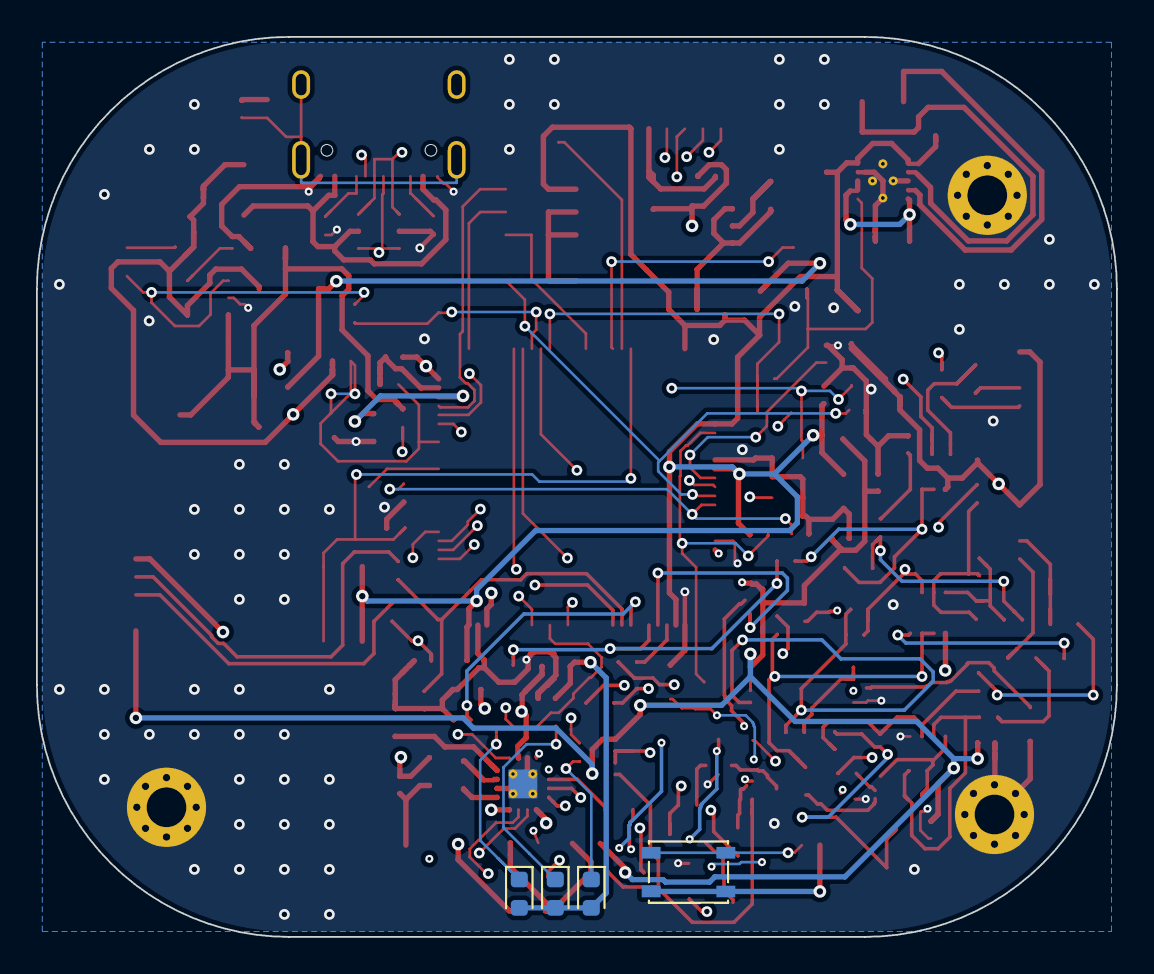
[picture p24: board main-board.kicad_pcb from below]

Board: 4 copper layers, 60.0 x 50.0 mm, 154 parts (4 on the bottom side), 99 nets.

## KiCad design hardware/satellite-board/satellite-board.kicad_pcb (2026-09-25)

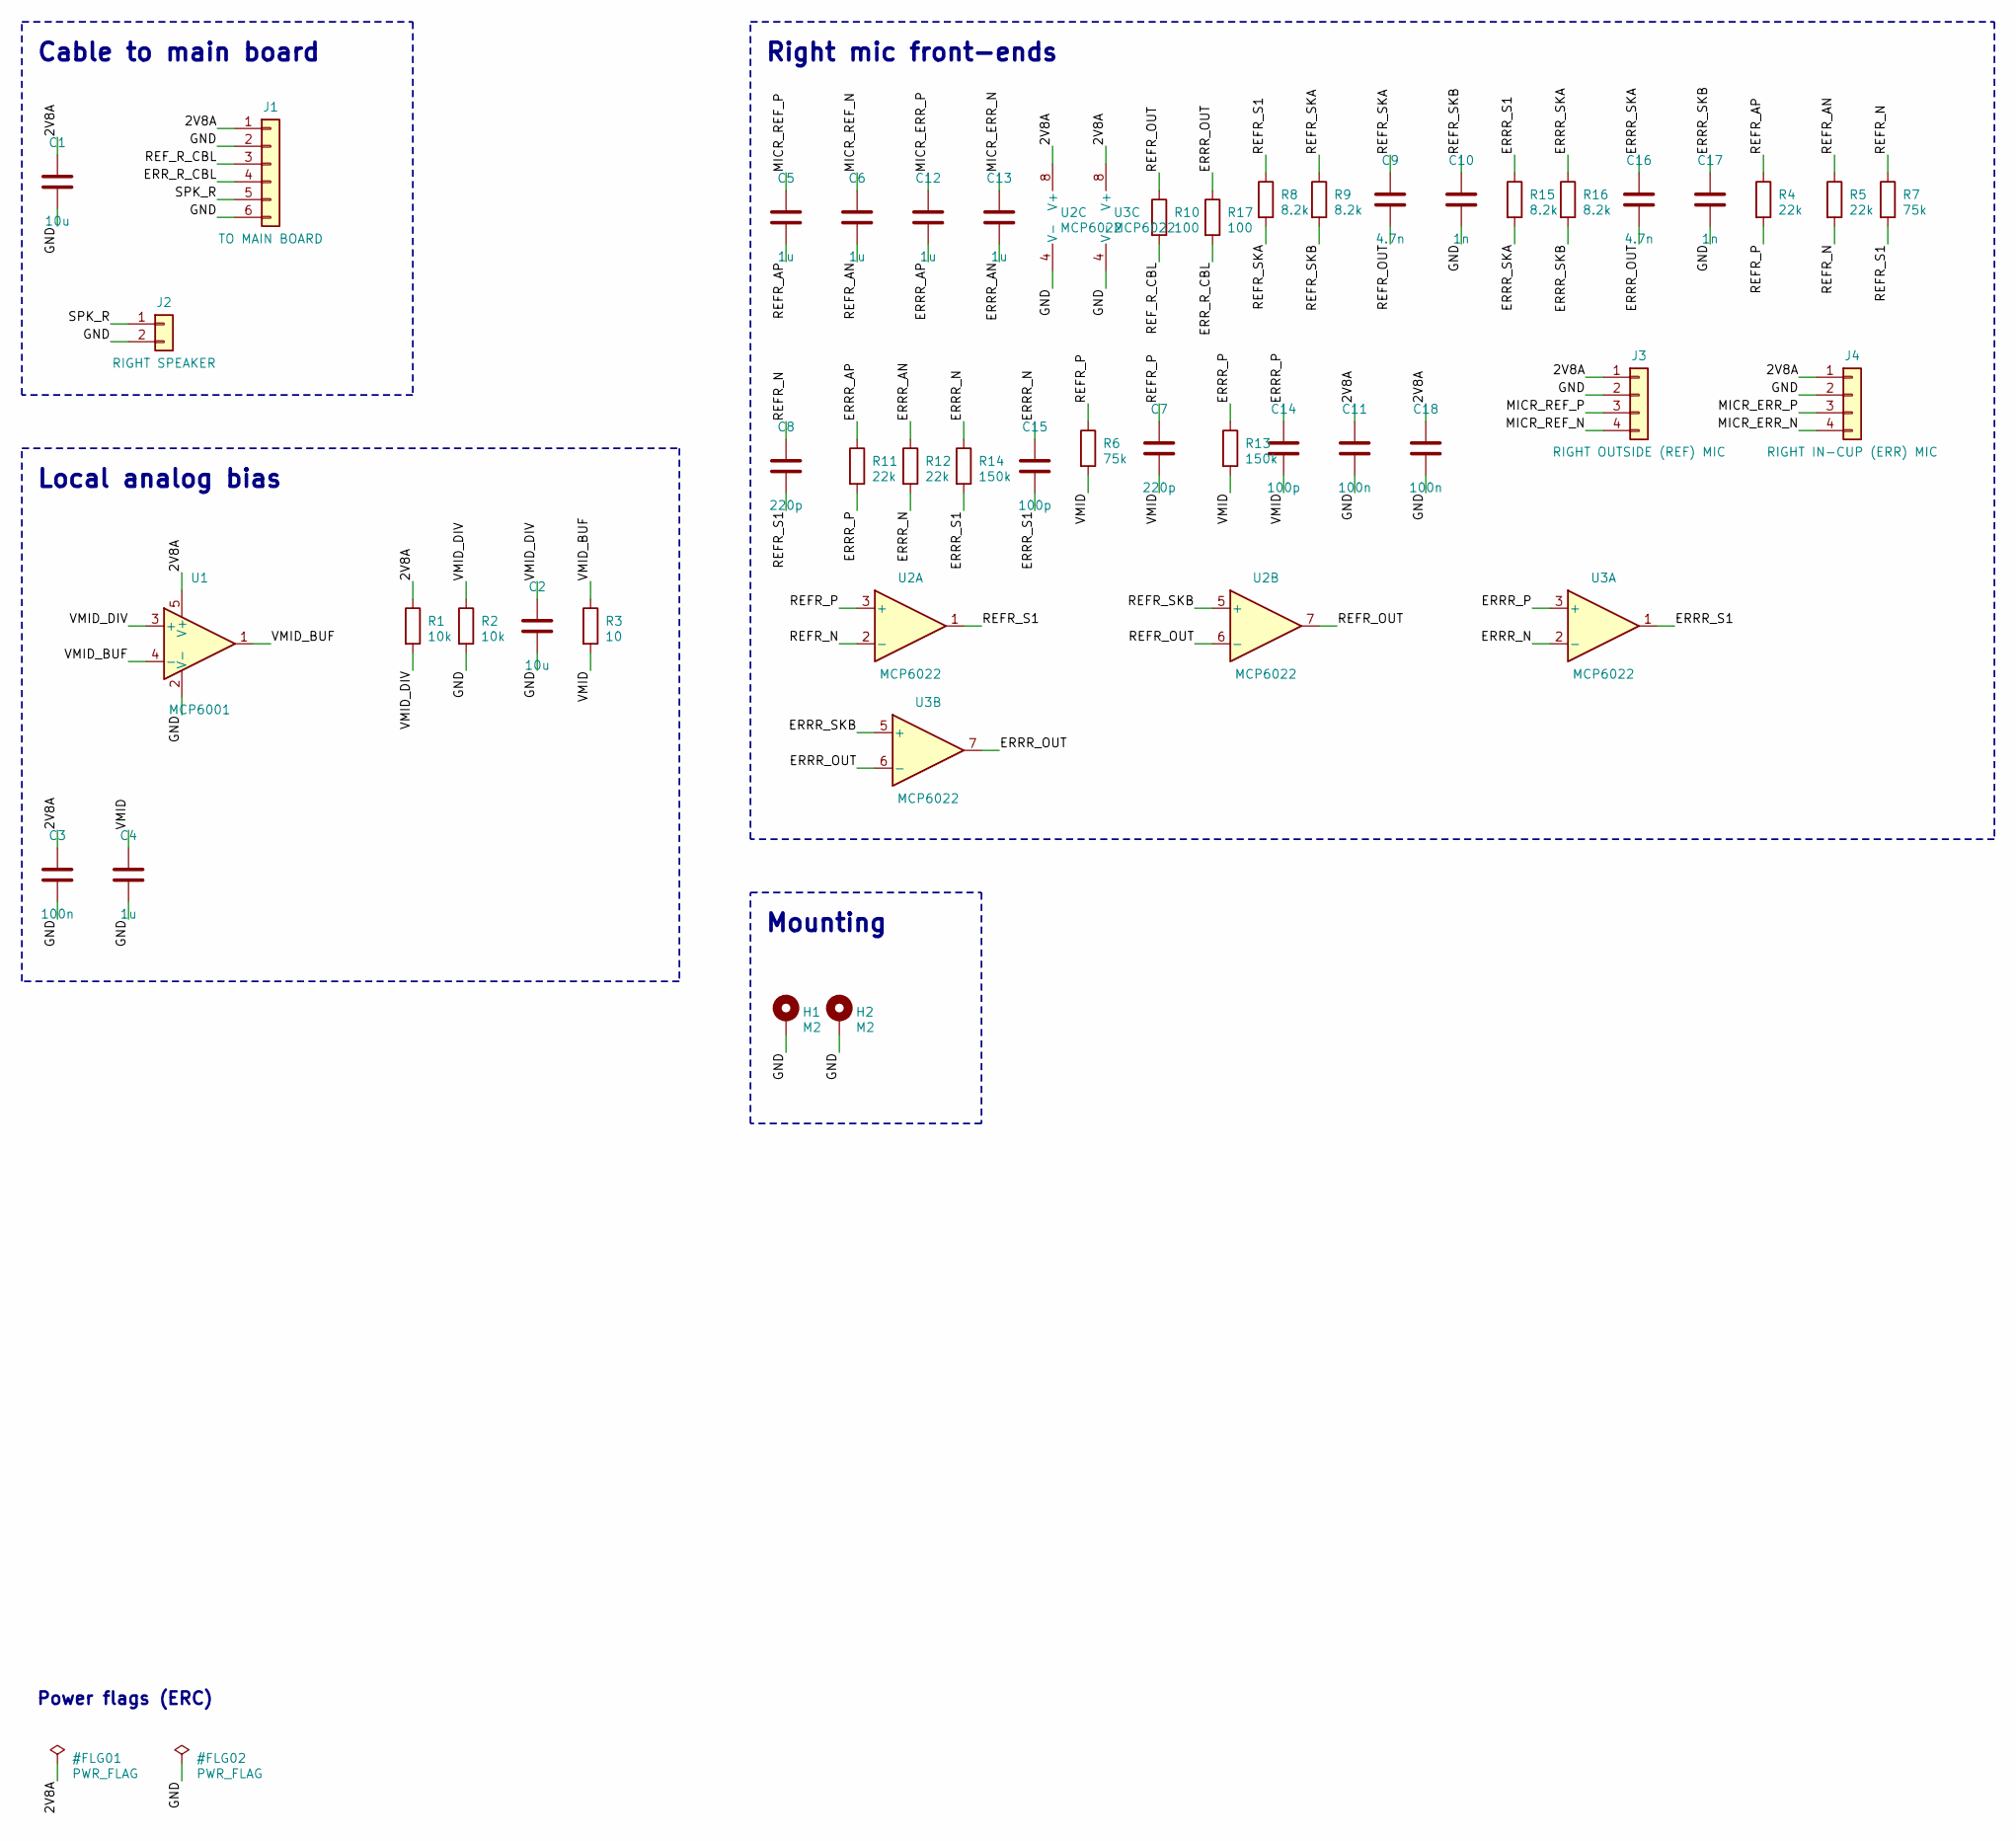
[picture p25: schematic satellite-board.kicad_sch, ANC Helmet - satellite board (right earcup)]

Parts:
C1, C2: 10u; C_0805_2012Metric; MPN 10u X5R
C3, C11, C18: 100n; C_0402_1005Metric; MPN 100n X7R
C4, C5, C6, C12, C13: 1u; C_0603_1608Metric; MPN 1u X7R
C7, C8: 220p; C_0402_1005Metric; MPN 220p C0G
C9, C16: 4.7n; C_0603_1608Metric; MPN 4.7n C0G
C10, C17: 1n; C_0402_1005Metric; MPN 1n C0G
C14, C15: 100p; C_0402_1005Metric; MPN 100p C0G
H1, H2: M2; MountingHole_2.2mm_M2_Pad_Via
J1: TO MAIN BOARD; JST_SH_SM06B-SRSS-TB_1x06-1MP_P1.00mm_Horizontal; MPN JST SM06B-SRSS-TB
J2: RIGHT SPEAKER; JST_SH_SM02B-SRSS-TB_1x02-1MP_P1.00mm_Horizontal; MPN JST SM02B-SRSS-TB
J3: RIGHT OUTSIDE (REF) MIC; JST_SH_SM04B-SRSS-TB_1x04-1MP_P1.00mm_Horizontal; MPN JST SM04B-SRSS-TB
J4: RIGHT IN-CUP (ERR) MIC; JST_SH_SM04B-SRSS-TB_1x04-1MP_P1.00mm_Horizontal; MPN JST SM04B-SRSS-TB
R1, R2: 10k; R_0402_1005Metric; MPN 10k 1% 02_1
R3: 10; R_0402_1005Metric; MPN 10 1% 02_1
R4, R5, R11, R12: 22k; R_0402_1005Metric; MPN 22k 1% 02_1
R6, R7: 75k; R_0402_1005Metric; MPN 75k 1% 02_1
R8, R9, R15, R16: 8.2k; R_0402_1005Metric; MPN 8.2k 1% 02_1
R10, R17: 100; R_0402_1005Metric; MPN 100 1% 02_1
R13, R14: 150k; R_0402_1005Metric; MPN 150k 1% 02_1
U1: MCP6001; SOT-23-5; MPN MCP6001T-I/OT
U2, U3: MCP6022; TSSOP-8_4.4x3mm_P0.65mm; MPN MCP6022-I/ST

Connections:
2V8A: C1.1, C3.1, C11.1, C18.1, J1.1, J3.1, J4.1, R1.1, U1.5 (V+), U2.8 (V+), U3.8 (V+)
ERRR_AN: C13.2, R12.1
ERRR_AP: C12.2, R11.1
ERRR_N: C15.1, R12.2, R14.1, U3.2 (-)
ERRR_OUT: C16.2, R17.1, U3.6 (-), U3.7
ERRR_P: C14.1, R11.2, R13.1, U3.3 (+)
ERRR_S1: C15.2, R14.2, R15.1, U3.1
ERRR_SKA: C16.1, R15.2, R16.1
ERRR_SKB: C17.1, R16.2, U3.5 (+)
ERR_R_CBL: J1.4, R17.2
GND: C1.2, C2.2, C3.2, C4.2, C10.2, C11.2, C17.2, C18.2, H1.1, H2.1, J1.2, J1.6, J2.2, J3.2, J4.2, R2.2, U1.2 (V-), U2.4 (V-), U3.4 (V-)
MICR_ERR_N: C13.1, J4.4
MICR_ERR_P: C12.1, J4.3
MICR_REF_N: C6.1, J3.4
MICR_REF_P: C5.1, J3.3
REFR_AN: C6.2, R5.1
REFR_AP: C5.2, R4.1
REFR_N: C8.1, R5.2, R7.1, U2.2 (-)
REFR_OUT: C9.2, R10.1, U2.6 (-), U2.7
REFR_P: C7.1, R4.2, R6.1, U2.3 (+)
REFR_S1: C8.2, R7.2, R8.1, U2.1
REFR_SKA: C9.1, R8.2, R9.1
REFR_SKB: C10.1, R9.2, U2.5 (+)
REF_R_CBL: J1.3, R10.2
SPK_R: J1.5, J2.1
VMID: C4.1, C7.2, C14.2, R3.2, R6.2, R13.2
VMID_BUF: R3.1, U1.1, U1.4 (-)
VMID_DIV: C2.1, R1.2, R2.1, U1.3 (+)

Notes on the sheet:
Cable to main board
Local analog bias
Right mic front-ends
Mounting
Power flags (ERC)

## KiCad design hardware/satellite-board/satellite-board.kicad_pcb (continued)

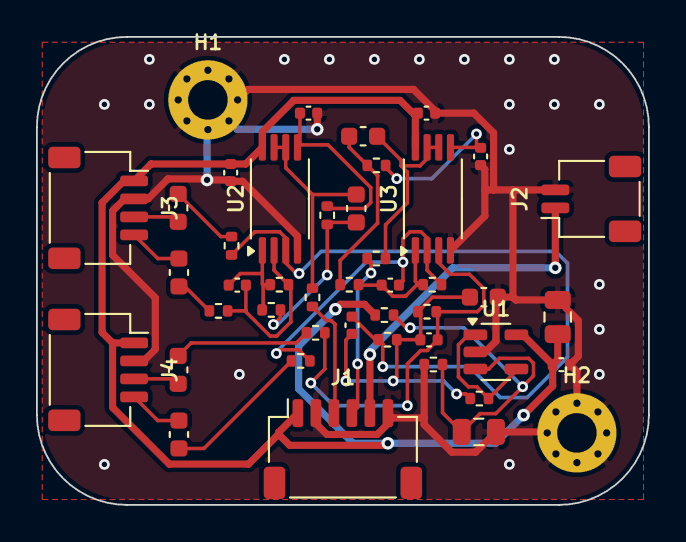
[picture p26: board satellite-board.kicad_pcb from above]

Board: 2 copper layers, 34.0 x 26.0 mm, 44 parts (0 on the bottom side), 28 nets.

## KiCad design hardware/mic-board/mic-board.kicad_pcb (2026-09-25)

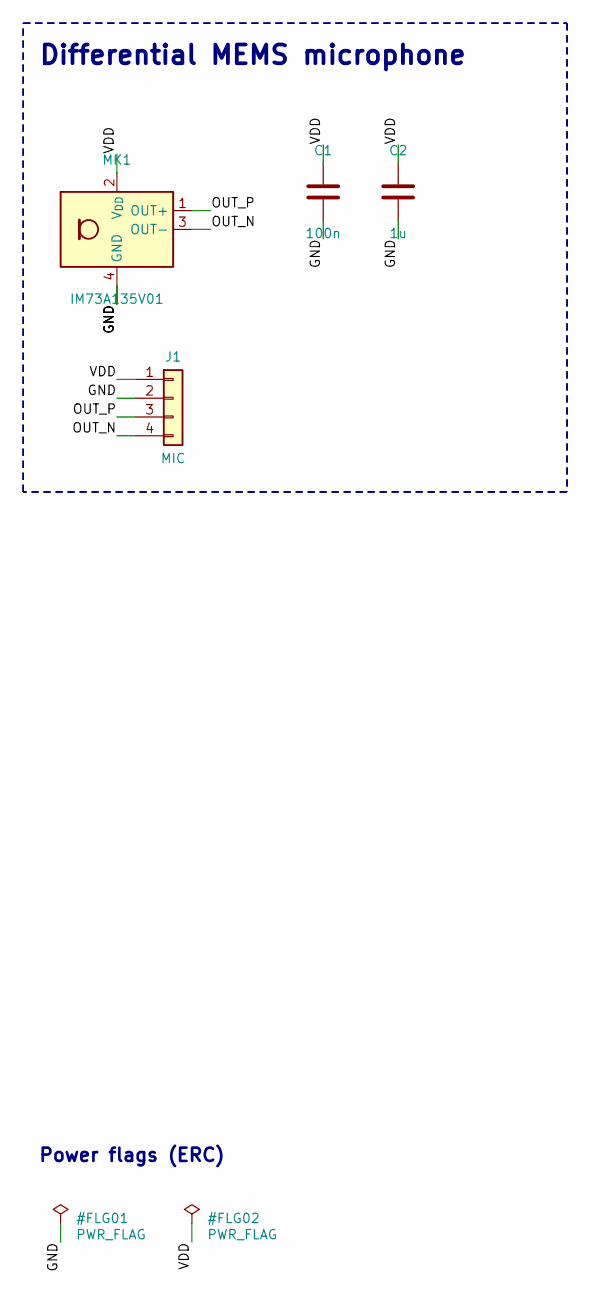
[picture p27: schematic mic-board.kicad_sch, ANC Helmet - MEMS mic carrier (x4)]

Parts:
C1: 100n; C_0402_1005Metric; MPN 100n X7R
C2: 1u; C_0402_1005Metric; MPN 1u X5R
J1: MIC; JST_SH_SM04B-SRSS-TB_1x04-1MP_P1.00mm_Horizontal; MPN JST SM04B-SRSS-TB
MK1: IM73A135V01; Infineon_PG-LLGA-5-2; MPN IM73A135V01XTSA1

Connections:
GND: C1.2, C2.2, J1.2, MK1.4 (GND), MK1.5 (GND)
OUT_N: J1.4, MK1.3 (OUT-)
OUT_P: J1.3, MK1.1 (OUT+)
VDD: C1.1, C2.1, J1.1, MK1.2 (V_{DD})

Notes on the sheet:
Differential MEMS microphone
Power flags (ERC)

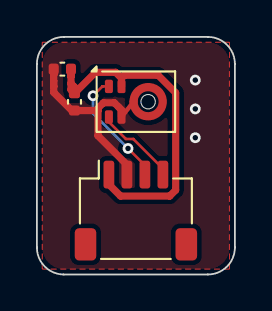
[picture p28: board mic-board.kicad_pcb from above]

Board: 2 copper layers, 11.0 x 13.2 mm, 4 parts (0 on the bottom side), 4 nets.

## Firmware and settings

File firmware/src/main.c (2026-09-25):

/*
 * main.c - boot sequence, main loop, command line (USB CDC and BLE share it).
 *
 * Boot:  hold power -> clocks -> load calibration -> audio up (muted) -> amp on
 *        -> if calibrated: 2 s fit check (probe noise) -> default mode (ANC)
 *        -> if not calibrated: passive + magenta LED, waits for "cal paths"
 * Loop:  USB/BLE commands, button, LED, 1 Hz dose/battery, 1/min log record, watchdog.
 */
#include <stdarg.h>
#include <stdio.h>
#include <stdlib.h>
#include <string.h>
#include <math.h>
#include "hw.h"
#include "audio.h"
#include "app.h"
#include "store.h"
#include "comms.h"
#include "power_ui.h"

/* survives a soft reset: request to enter the ST DFU bootloader */
static volatile uint32_t boot_magic __attribute__((section(".noinit")));
#define BOOT_MAGIC_DFU 0xDF00B007u

static dose_t   g_dose;
static uint32_t minutes_on, sec_in_min;
static double   min_e_ear, min_e_amb;
static uint8_t  min_flags;
static bool     stream[2];
static comms_link_t id_requester = LINK_ALL;
static int      mic_cal_ch = -1;
static float    mic_cal_db;
static comms_link_t mic_cal_link;
static bool     fit_warning;
/* seal monitor: per-ear decision state, factory-baseline learning */
static seal_t       g_seal[2];
static bool         seal_warning;
static seal_learn_t seal_lrn[2];
static uint32_t     seal_learn_left;
static comms_link_t seal_requester = LINK_ALL;
static comms_link_t test_requester = LINK_ALL;
static float        test_hz;
#define DRIVER_MIN_PA_PER_V 17.0f      /* SPICE requirement: ~15 Pa of 63 Hz anti-noise at 0.9 V */

extern uint32_t _sitcm, _itcm_start, _itcm_end;    /* linker */
extern uint32_t _saxi, _eaxi;

/* ------------------------------------------------------------------ output helpers */
static void out(comms_link_t l, const char *fmt, ...) __attribute__((format(printf, 2, 3)));
static void out(comms_link_t l, const char *fmt, ...)
{
    char b[256];
    va_list ap;
    va_start(ap, fmt);
    int n = vsnprintf(b, sizeof b - 2, fmt, ap);
    va_end(ap);
    if (n < 0) return;
    if (n > (int)sizeof b - 3) n = (int)sizeof b - 3;
    b[n++] = '\r'; b[n++] = '\n';
    comms_write(l, b, (uint32_t)n);
}

static float cpu_load_pct(void)
{
    return 100.0f * (float)audio_isr_cycles * (float)ANC_FS_HZ / (float)SystemCoreClock;
}

static void print_status(comms_link_t l)
{
    out(l, "{\"mode\":\"%s\",\"cal\":%u,\"ear_dba\":%.1f,\"amb_dba\":%.1f,\"atten_db\":%.1f,\"dose_pct\":%.2f,"
           "\"dose_unprot_pct\":%.1f,\"laeq_shift\":%.1f,\"vbat\":%.2f,\"chg\":%u,\"usb\":%u,\"ble\":%u,\"cpu_pct\":%.1f,"
           "\"isr_us_max\":%.1f,\"trips\":[%lu,%lu],\"ovl\":%lu,\"adc_ovr\":%lu,\"fit_warn\":%u,"
           "\"seal_cal\":%u,\"seal_loss_db\":[%.1f,%.1f],\"seal_leak\":[%u,%u]}",
        app_mode_name(g_app.mode), g_cal.paths_valid, (double)g_dose.laeq_1s_ear, (double)g_dose.laeq_1s_amb,
        (double)(g_dose.laeq_1s_amb - g_dose.laeq_1s_ear), g_dose.dose_pct, g_dose.dose_amb_pct,
        (double)dose_laeq(g_dose.e_ear, g_dose.seconds), (double)power_vbat(), power_charging(),
        power_usb_present(), comms_ble_connected(), (double)cpu_load_pct(),
        (double)((float)audio_isr_cycles_max * 1e6f / (float)SystemCoreClock),
        (unsigned long)g_app.trips[0], (unsigned long)g_app.trips[1], (unsigned long)g_app.overload_count,
        (unsigned long)audio_overruns, fit_warning, g_cal.seal_valid, (double)g_seal[0].avg, (double)g_seal[1].avg,
        g_seal[0].flag, g_seal[1].flag);
}

static void update_led(void)
{
    if (power_vbat() < VBAT_LOW_V && !power_usb_present()) { led_set(LED_LOW_BATT); return; }
    if (g_app.overload) { led_set(LED_FAULT); return; }
    const bool warn = fit_warning || seal_warning;       /* amber: reseat the cup */
    switch (g_app.mode) {
    case MODE_ID:      led_set(LED_ID); break;
    case MODE_ANC:     led_set(warn ? LED_FIT_WARN : LED_ANC); break;
    case MODE_ANC_HT:  led_set(warn ? LED_FIT_WARN : LED_ANC_HT); break;
    default:           led_set(!g_cal.paths_valid ? LED_NEEDS_CAL : (seal_warning ? LED_FIT_WARN : LED_PASSIVE)); break;
    }
}

static void new_shift(void)
{
    dose_cfg_t dc = { g_cal.dose_lc, g_cal.dose_q, g_cal.dose_thr, 8.0f * 3600.0f };
    dose_init(&g_dose, &dc);
    minutes_on = 0;
    min_flags |= 8u;
}

static void save_state_record(void)
{
    store_rec_t r;
    memset(&r, 0, sizeof r);
    const uint32_t n = sec_in_min ? sec_in_min : 1u;
    r.minutes_on = minutes_on;
    r.laeq_ear = 10.0f * log10f((float)(min_e_ear / n) + 1e-12f);
    r.laeq_amb = 10.0f * log10f((float)(min_e_amb / n) + 1e-12f);
    r.dose_pct = (float)g_dose.dose_pct;
    r.dose_amb_pct = (float)g_dose.dose_amb_pct;
    r.vbat_mv = (uint16_t)(power_vbat() * 1000.0f);
    r.mode = (uint8_t)g_app.mode;
    r.flags = min_flags | (power_charging() ? 4u : 0u);
    store_log_append(&r);
    min_e_ear = min_e_amb = 0.0;
    sec_in_min = 0;
    min_flags = 0;
}

static void shutdown(void)
{
    audio_stop();
    amp_enable(false);
    save_state_record();
    power_off();
}

/* ------------------------------------------------------------------ command line */
static const char *HELP[] = {
    "status                      one JSON line of live values",
    "stream on|off               status every second on this link",
    "mode passive|anc|ht         operating mode",
    "cal paths [s]               FACTORY: speaker-path calibration, quiet room, helmet on head/dummy (default 3 s)",
    "cal check                   in-field fit check (refines the stored model)",
    "cal mic refl|errl|refr|errr [dB]   mic trim with a 1 kHz calibrator (default 94 dB)",
    "seal                        per-band cup attenuation vs the factory baseline, both ears",
    "test driver [Hz] [mVpk]     driver acceptance: tone at the amp output, in-cup Pa/V (default 63 Hz, 100 mV)",
    "seal learn [s]              FACTORY: good fit on a reference head, >= 80 dB(A) broadband noise (default 10 s)",
    "get                         all settings",
    "set <key> <value>           mu_ff mu_fb ht_gain amp_gain dose_lc dose_q dose_thr default_mode boot_check",
    "save                        write settings + calibration to flash",
    "dose [reset]                shift exposure summary / start new shift",
    "log [erase]                 dump minute log as CSV",
    "defaults                    factory settings (keeps path + mic calibration)",
    "version | reboot | dfu | off",
};

static void cmd_get(comms_link_t l)
{
    out(l, "mu_ff=%g mu_fb=%g ht_gain=%g amp_gain=%u dose_lc=%g dose_q=%g dose_thr=%g default_mode=%s boot_check=%u",
        (double)g_cal.mu_ff, (double)g_cal.mu_fb, (double)g_cal.ht_gain, g_cal.amp_gain, (double)g_cal.dose_lc,
        (double)g_cal.dose_q, (double)g_cal.dose_thr, app_mode_name((app_mode_t)g_cal.default_mode), g_cal.boot_refine);
    out(l, "mic_gain refl=%.4f errl=%.4f refr=%.4f errr=%.4f paths_valid=%u serial=%lu",
        (double)g_cal.mic_gain[0], (double)g_cal.mic_gain[1], (double)g_cal.mic_gain[2], (double)g_cal.mic_gain[3],
        g_cal.paths_valid, (unsigned long)g_cal.serial);
}

static bool parse_mode(const char *s, app_mode_t *m)
{
    if (!strcmp(s, "passive")) { *m = MODE_PASSIVE; return true; }
    if (!strcmp(s, "anc"))     { *m = MODE_ANC; return true; }
    if (!strcmp(s, "ht") || !strcmp(s, "anc+ht")) { *m = MODE_ANC_HT; return true; }
    return false;
}

static void cmd_set(comms_link_t l, const char *k, const char *v)
{
    const float f = strtof(v, NULL);
    if (!strcmp(k, "mu_ff") && f > 0 && f < 0.05f) g_cal.mu_ff = f;
    else if (!strcmp(k, "mu_fb") && f > 0 && f < 0.05f) g_cal.mu_fb = f;
    else if (!strcmp(k, "ht_gain") && f >= 0 && f <= 4.0f) g_cal.ht_gain = f;
    else if (!strcmp(k, "amp_gain") && f >= 0 && f <= 3) { g_cal.amp_gain = (uint8_t)f; amp_set_gain(g_cal.amp_gain); }
    else if (!strcmp(k, "dose_lc") && f >= 70 && f <= 100) g_cal.dose_lc = f;
    else if (!strcmp(k, "dose_q") && (f == 3.0f || f == 4.0f || f == 5.0f)) g_cal.dose_q = f;
    else if (!strcmp(k, "dose_thr") && f >= 0 && f <= 90) g_cal.dose_thr = f;
    else if (!strcmp(k, "boot_check") && (f == 0 || f == 1)) g_cal.boot_refine = (uint8_t)f;
    else if (!strcmp(k, "default_mode")) {
        app_mode_t m;
        if (!parse_mode(v, &m)) { out(l, "ERR mode"); return; }
        g_cal.default_mode = (uint8_t)m;
    } else { out(l, "ERR unknown key or value out of range"); return; }
    app_apply_params();
    g_dose.cfg.lc_db = g_cal.dose_lc; g_dose.cfg.q_db = g_cal.dose_q; g_dose.cfg.thr_db = g_cal.dose_thr;
    out(l, "OK (not saved - send 'save')");
}

static void cmd_log(comms_link_t l)
{
    const uint32_t n = store_log_count();
    out(l, "seq,minutes_on,laeq_ear_dba,laeq_amb_dba,dose_pct,dose_unprotected_pct,vbat_mv,mode,flags");
    for (uint32_t i = 0; i < n; i++) {
        store_rec_t r;
        if (!store_log_get(i, &r)) continue;
        out(l, "%lu,%lu,%.1f,%.1f,%.2f,%.1f,%u,%s,%u", (unsigned long)r.seq, (unsigned long)r.minutes_on,
            (double)r.laeq_ear, (double)r.laeq_amb, (double)r.dose_pct, (double)r.dose_amb_pct, r.vbat_mv,
            app_mode_name((app_mode_t)r.mode), r.flags);
        hw_watchdog_kick();
    }
    out(l, "END %lu records", (unsigned long)n);
}

static void on_line(comms_link_t l, char *s)
{
    char *argv[6];
    int argc = 0;
    for (char *t = strtok(s, " \t"); t && argc < 6; t = strtok(NULL, " \t")) argv[argc++] = t;
    if (!argc) return;
    const char *c = argv[0];

    if (!strcmp(c, "help") || !strcmp(c, "?")) {
        for (unsigned i = 0; i < sizeof HELP / sizeof HELP[0]; i++) out(l, "%s", HELP[i]);
    } else if (!strcmp(c, "version")) {
        out(l, "%s fw %s, %s, fs=%u Hz, taps ff/fb/s/f=%u/%u/%u/%u, silicon rev %s", BOARD_NAME, FW_VERSION,
            __DATE__, (unsigned)ANC_FS_HZ, (unsigned)ANC_L_FF, (unsigned)ANC_L_FB, (unsigned)ANC_L_S,
            (unsigned)ANC_L_F, hw_is_rev_v() ? "V" : "Y");
    } else if (!strcmp(c, "status")) {
        print_status(l);
    } else if (!strcmp(c, "stream") && argc > 1) {
        stream[l == LINK_BLE] = !strcmp(argv[1], "on");
        out(l, "OK");
    } else if (!strcmp(c, "mode") && argc > 1) {
        app_mode_t m;
        if (!parse_mode(argv[1], &m)) { out(l, "ERR mode passive|anc|ht"); return; }
        if (m != MODE_PASSIVE && !g_cal.paths_valid) { out(l, "ERR not calibrated - run 'cal paths' first"); return; }
        app_set_mode(m);
        fit_warning = false;
        out(l, "OK %s", app_mode_name(g_app.mode));
    } else if (!strcmp(c, "cal") && argc > 1 && !strcmp(argv[1], "paths")) {
        const float secs = (argc > 2) ? strtof(argv[2], NULL) : 3.0f;
        if (secs < 1.0f || secs > 20.0f) { out(l, "ERR seconds 1..20"); return; }
        id_requester = l;
        if (!app_start_id(false, secs)) { out(l, "ERR busy"); return; }
        out(l, "calibrating speaker paths for %.0f s - keep quiet, helmet on", (double)secs);
    } else if (!strcmp(c, "test") && argc > 1 && !strcmp(argv[1], "driver")) {
        const float hz = (argc > 2) ? strtof(argv[2], NULL) : 63.0f;
        const float mv = (argc > 3) ? strtof(argv[3], NULL) : 100.0f;
        if (!app_start_test(hz, mv * 1e-3f, 2.0f)) { out(l, "ERR busy, or Hz 20..4000, mVpk 1..%u", (unsigned)(AMP_OUT_VPK * 1000.0f)); return; }
        test_requester = l;
        test_hz = hz;
        out(l, "driver test: %.0f Hz, %.0f mV peak at the amp, 2.3 s - helmet on the test head", (double)hz, (double)mv);
    } else if (!strcmp(c, "cal") && argc > 1 && !strcmp(argv[1], "check")) {
        id_requester = l;
        if (!app_start_id(true, 2.0f)) { out(l, "ERR not calibrated or busy"); return; }
        out(l, "fit check (2 s)...");
    } else if (!strcmp(c, "cal") && argc > 2 && !strcmp(argv[1], "mic")) {
        static const char *names[4] = { "refl", "errl", "refr", "errr" };
        mic_cal_ch = -1;
        for (int i = 0; i < 4; i++) if (!strcmp(argv[2], names[i])) mic_cal_ch = i;
        if (mic_cal_ch < 0) { out(l, "ERR mic refl|errl|refr|errr"); return; }
        mic_cal_db = (argc > 3) ? strtof(argv[3], NULL) : 94.0f;
        mic_cal_link = l;
        g_meter.ready = false;
        out(l, "measuring %s for 1 s at %.1f dB...", argv[2], (double)mic_cal_db);
    } else if (!strcmp(c, "get")) {
        cmd_get(l);
    } else if (!strcmp(c, "set") && argc > 2) {
        cmd_set(l, argv[1], argv[2]);
    } else if (!strcmp(c, "save")) {
        out(l, store_save_cal(&g_cal) ? "OK saved" : "ERR flash write failed");
    } else if (!strcmp(c, "dose")) {
        if (argc > 1 && !strcmp(argv[1], "reset")) { new_shift(); out(l, "OK new shift"); return; }
        out(l, "shift: %lu s, LAeq ear %.1f dB(A), LAeq outside %.1f dB(A), dose %.2f %% (would be %.1f %% unprotected), "
               "criterion %.0f dB / %.0f dB exchange, max 1 s at ear %.1f dB(A)",
            (unsigned long)g_dose.seconds, (double)dose_laeq(g_dose.e_ear, g_dose.seconds),
            (double)dose_laeq(g_dose.e_amb, g_dose.seconds), g_dose.dose_pct, g_dose.dose_amb_pct,
            (double)g_dose.cfg.lc_db, (double)g_dose.cfg.q_db, (double)g_dose.max_1s_ear);
    } else if (!strcmp(c, "log")) {
        if (argc > 1 && !strcmp(argv[1], "erase")) { store_log_erase_all(); out(l, "OK log erased"); return; }
        cmd_log(l);
    } else if (!strcmp(c, "defaults")) {
        app_cal_t keep = g_cal;
        app_defaults(&g_cal);
        memcpy(g_cal.s_hat, keep.s_hat, sizeof g_cal.s_hat);
        memcpy(g_cal.f_hat, keep.f_hat, sizeof g_cal.f_hat);
        memcpy(g_cal.mic_gain, keep.mic_gain, sizeof g_cal.mic_gain);
        g_cal.paths_valid = keep.paths_valid;
        g_cal.serial = keep.serial;
        memcpy(g_cal.seal_base, keep.seal_base, sizeof g_cal.seal_base);
        g_cal.seal_valid = keep.seal_valid;
        app_apply_params();
        out(l, "OK defaults (not saved)");
    } else if (!strcmp(c, "seal") && argc > 1 && !strcmp(argv[1], "learn")) {
        const float secs = (argc > 2) ? strtof(argv[2], NULL) : 10.0f;
        if (secs < 3.0f || secs > 60.0f) { out(l, "ERR seconds 3..60"); return; }
        memset(seal_lrn, 0, sizeof seal_lrn);
        seal_requester = l;
        seal_learn_left = (uint32_t)secs;
        out(l, "learning the seal baseline for %u s - keep the helmet still in steady broadband noise", (unsigned)secs);
    } else if (!strcmp(c, "seal")) {
        for (int e = 0; e < 2; e++) {
            const seal_t *m = &g_seal[e];
            out(l, "%s: loss %.1f dB %s%s | IL %.1f %.1f %.1f %.1f dB | base %.1f %.1f %.1f %.1f dB", e ? "R" : "L",
                (double)m->avg, m->flag ? "LEAK" : "ok", m->valid ? "" : " (too quiet to judge)",
                (double)m->il[0], (double)m->il[1], (double)m->il[2], (double)m->il[3],
                (double)m->base[0], (double)m->base[1], (double)m->base[2], (double)m->base[3]);
        }
        if (!g_cal.seal_valid) out(l, "no seal baseline - run 'seal learn' (factory)");
    } else if (!strcmp(c, "reboot")) {
        out(l, "rebooting"); hw_delay_ms(50); NVIC_SystemReset();
    } else if (!strcmp(c, "dfu")) {
        out(l, "entering ST DFU bootloader"); hw_delay_ms(50);
        boot_magic = BOOT_MAGIC_DFU; NVIC_SystemReset();
    } else if (!strcmp(c, "off")) {
        out(l, "powering off"); hw_delay_ms(50); shutdown();
    } else {
        out(l, "ERR unknown command - try 'help'");
    }
}

/* ------------------------------------------------------------------ periodic work */
static void seal_init_all(void)
{
    for (int e = 0; e < 2; e++) seal_init(&g_seal[e], g_cal.seal_base[e]);
    seal_warning = false;
}

static void seal_every_second(void)
{
    if (!g_seal_rt.ready) return;
    g_seal_rt.ready = false;
    if (g_app.mode == MODE_ID || g_app.mode == MODE_TEST) return;   /* probe/tone is not ambient */
    if (seal_learn_left) {
        for (int e = 0; e < 2; e++) seal_learn_add(&seal_lrn[e], g_seal_rt.sec_ms[e][0], g_seal_rt.sec_ms[e][1]);
        if (--seal_learn_left == 0u) {
            bool ok = true;
            for (int e = 0; e < 2; e++) ok = seal_learn_result(&seal_lrn[e], g_cal.seal_base[e]) && ok;
            g_cal.seal_valid = ok;
            seal_init_all();
            out(seal_requester, ok ? "seal baseline L %.1f %.1f %.1f %.1f / R %.1f %.1f %.1f %.1f dB - 'save' to keep"
                                   : "ERR seal baseline: no data",
                (double)g_cal.seal_base[0][0], (double)g_cal.seal_base[0][1], (double)g_cal.seal_base[0][2],
                (double)g_cal.seal_base[0][3], (double)g_cal.seal_base[1][0], (double)g_cal.seal_base[1][1],
                (double)g_cal.seal_base[1][2], (double)g_cal.seal_base[1][3]);
        }
        return;
    }
    if (!g_cal.seal_valid) return;
    for (int e = 0; e < 2; e++) seal_add_second(&g_seal[e], g_seal_rt.sec_ms[e][0], g_seal_rt.sec_ms[e][1]);
    seal_warning = g_seal[0].flag || g_seal[1].flag;
    if (seal_warning) min_flags |= 16u;
}

static void every_second(void)
{
    const float ms_ear = 0.5f * (g_dosi.sec_ms[0] + g_dosi.sec_ms[1]);
    const float pk = fmaxf(g_dosi.sec_peak[0], g_dosi.sec_peak[1]);
    dose_add_second(&g_dose, ms_ear, g_dosi.sec_ms[2], pk);
    min_e_ear += pow(10.0, (double)g_dose.laeq_1s_ear / 10.0);
    min_e_amb += pow(10.0, (double)g_dose.laeq_1s_amb / 10.0);
    if (g_app.overload) min_flags |= 1u;
    seal_every_second();
    if (++sec_in_min >= 60u) { minutes_on++; save_state_record(); }

    power_poll();
    if (power_vbat() < VBAT_CUTOFF_V && !power_usb_present()) shutdown();
    update_led();
    for (int k = 0; k < 2; k++) if (stream[k]) print_status((comms_link_t)k);
}

static void finish_id_if_done(void)
{
    if (g_app.mode != MODE_ID || !sysid_done(&g_id[0]) || !sysid_done(&g_id[1])) return;
    char msg[200];
    const bool factory = !g_app.id_refine;
    const int rc = app_finish_id(msg, sizeof msg);
    out(id_requester, "%s", msg);
    if (rc == 0 && factory) out(id_requester, store_save_cal(&g_cal) ? "calibration saved" : "ERR flash write failed");
    fit_warning = (rc == 1);
    if (rc == 1) min_flags |= 2u;
    if (rc == 2) g_app.mode = MODE_PASSIVE;
    id_requester = LINK_ALL;
    update_led();
}
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
int main(void)
{
    if (boot_magic == BOOT_MAGIC_DFU) { boot_magic = 0; hw_jump_to_bootloader(); }
    power_hold();                           /* before anything else: keep the regulator on */
    copy_ram_sections();
    hw_clock_init();
    hw_systick_init();
    hw_watchdog_init(2000);

    led_init();
    led_set(LED_BOOT);
    button_init();
    amp_init();
    power_init();

    app_defaults(&g_cal);
    const bool have_cal = store_load_cal(&g_cal);
    if (!have_cal) app_defaults(&g_cal);
    store_log_init();
    new_shift();
    store_rec_t last;
    if (store_log_last(&last) && !(last.flags & 8u)) {          /* continue the running shift */
        g_dose.dose_pct = last.dose_pct;
        g_dose.dose_amb_pct = last.dose_amb_pct;
        minutes_on = last.minutes_on;
        min_flags &= ~8u;
    }

    app_init();
    seal_init_all();
    audio_init();
    comms_init();
    audio_start();
    hw_delay_ms(100);                        /* let the DAC settle at mid-scale before the amp wakes */
    amp_set_gain(g_cal.amp_gain);
    amp_enable(true);
    hw_delay_ms(50);

    if (g_cal.paths_valid) {
        g_app.mode = (app_mode_t)g_cal.default_mode;
        if (g_cal.boot_refine) app_start_id(true, 2.0f);
    } else {
        g_app.mode = MODE_PASSIVE;
    }
    update_led();

    uint32_t t_sec = hw_millis(), t_10 = hw_millis();
    for (;;) {
        hw_watchdog_kick();
        comms_poll(on_line);
        finish_id_if_done();
        if (app_test_done()) {
            const float l = app_test_result(EAR_L), r = app_test_result(EAR_R);
            const bool lf = test_hz < 100.0f;          /* the pass limit is defined at low frequency */
            out(test_requester, "driver test %.0f Hz: L %.1f Pa/V, R %.1f Pa/V%s", (double)test_hz, (double)l, (double)r,
                !lf ? "" : (l >= DRIVER_MIN_PA_PER_V && r >= DRIVER_MIN_PA_PER_V) ? " - PASS (>= 17 Pa/V)"
                                                                                   : " - FAIL (need >= 17 Pa/V)");
            update_led();
        }
        mic_cal_poll();

        if (g_dosi.ready) { g_dosi.ready = false; every_second(); t_sec = hw_millis(); }
        else if (hw_millis() - t_sec > 3000u) { update_led(); t_sec = hw_millis(); }   /* audio stalled? */

        if (hw_millis() - t_10 >= 10u) {
            t_10 = hw_millis();
            led_poll();
            switch (button_poll()) {
            case BTN_SHORT:
                if (!g_cal.paths_valid) break;
                if (g_app.mode == MODE_ANC) app_set_mode(MODE_ANC_HT);
                else if (g_app.mode == MODE_ANC_HT) app_set_mode(MODE_PASSIVE);
                else if (g_app.mode == MODE_PASSIVE) app_set_mode(MODE_ANC);
                fit_warning = false;
                update_led();
                break;
            case BTN_DOUBLE:                     /* re-check the fit, e.g. after adjusting the helmet */
                if (g_cal.paths_valid) app_start_id(true, 2.0f);
                update_led();
                break;
            case BTN_LONG:
                shutdown();
                break;
            default: break;
            }
        }
        __WFI();                                 /* woken by the 32 kHz audio ISR at the latest */
    }
}

/* any fault: mute the speakers first, then reset */
void HardFault_Handler(void)
{
    DAC1->DHR12RD = (2048u << DAC_DHR12RD_DACC2DHR_Pos) | 2048u;
    GPIOD->BSRR = 1u << (PIN_AMP_EN_PIN + 16u);
    NVIC_SystemReset();
}
void MemManage_Handler(void) { HardFault_Handler(); }
void BusFault_Handler(void) { HardFault_Handler(); }
void UsageFault_Handler(void) { HardFault_Handler(); }

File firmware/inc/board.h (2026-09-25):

/*
 * board.h - electrical constants of the ANC helmet main board (rev A).
 * Pin assignments live in board_pins.h (generated from hardware/gen/pinmap.py).
 * Values marked [CAL] are nominal and get replaced by per-unit calibration
 * stored in flash (see docs/calibration.md).
 */
#ifndef BOARD_H
#define BOARD_H

#include "board_pins.h"

#define BOARD_NAME           "ANC-Helmet rev A"
#define FW_VERSION           "1.0.0"

/* clocks */
#define HSE_HZ               25000000u
#define SYSCLK_HZ            400000000u   /* VOS1: valid on every H743 silicon revision */
#define HCLK_HZ              200000000u
#define APB1_TIMER_HZ        200000000u
#define ADC_KER_HZ           36000000u    /* PLL2P */

/* analog front end */
#define VREF_V               2.8f         /* VREF+ = VDDA = 2V8A rail (LP5907-2.8) */
#define ADC_FULL_SCALE       65536.0f     /* 16-bit */
#define ADC_MID              32768.0f     /* preamps are biased at VREF/2 */
#define MIC_SENS_V_PER_PA    0.012589f    /* IM73A135: -38 dBV/Pa differential [CAL] */
#define GAIN_REF             3.409f       /* 75k/22k difference amp (outside mics) */
#define GAIN_ERR             6.818f       /* 150k/22k difference amp (in-cup mics) */

/* output: DAC (12-bit, 0..VREF) -> 2nd-order recon filter -> TPA6132A2 */
#define DAC_MID              2048.0f
#define DAC_MAX_CODE         4095.0f
/* nominal anti-noise scale: pascal at the ear per DAC volt at amp gain 0 dB.
 * Only sets the unit of the controller output; the identified S_hat absorbs
 * the real value. [CAL] */
#define OUT_PA_PER_V         8.0f
#define AMP_GAIN_DEFAULT     1u           /* TPA6132A2 G1:G0 -> 0=-6 dB 1=0 dB 2=+3 dB 3=+6 dB */
/* TPA6132A2 output swing, V peak (25 mW into 16 R). At 0 dB and above the amp clips
 * before the DAC does - see hardware/spice/results/spice_results.md */
#define AMP_OUT_VPK          0.9f

/* battery: VBAT -> 100k/100k -> ADC3 */
#define VBAT_DIV             2.0f
#define VBAT_LOW_V           3.40f        /* warn */
#define VBAT_CUTOFF_V        3.20f        /* save state and power off */

/* safety */
#define HT_LIMIT_DB_SPL      82.0f        /* hear-through can never exceed this at the ear */
#define EAR_OVERLOAD_DB      118.0f       /* sustained unweighted peak at the error mic -> passive
                                             (capped below the channel's full scale in app.c) */

#endif

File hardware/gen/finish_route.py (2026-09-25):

"""Finish the connections the autorouter leaves: a small grid maze router (A*) on a
finished board, working directly in the .kicad_pcb (KiCad 7 pcbnew API).

Two jobs:
  * a two-pad signal connection (e.g. AMP_INLN U10.1 -> C51.1): A* between the pads over
    F.Cu / In2.Cu / B.Cu with vias, avoiding other-net copper with clearance;
  * a GND pad whose pour island has no path to the inner GND plane: A* from the pad to the
    nearest spot where a via fits, then a via down to the plane.

    python3 finish_route.py main-board [REF.PAD ...] [--islands]   # SIGNALS/RIPUP + GND fan-outs
    python3 finish_route.py main-board --gnd-only REF.PAD ... [--islands]
    python3 finish_route.py main-board --rip NET --fan REF.PAD         # whole-net rip-up + re-route
    python3 finish_route.py main-board --rip-local NET --fan REF.PAD   # rip only segments near the pad
The --rip modes save only when everything re-connects. Afterwards run `pcb_build.py tie <board>`
in a fresh process (refill + DRC).

How the main board was finished (from 11 unrouted after autorouting):
    finish_route.py main-board                          AMP_INLN (+ SPK_L rip-up / re-route)
    finish_route.py main-board --gnd-only C44.2 R1.2 U2.2 R15.2 --islands
    finish_route.py main-board --rip DACL_OUT --fan R15.2
    finish_route.py main-board --rip DACL_B --fan U9.4
    finish_route.py main-board --rip ERRL_SKA --fan R22.2
    finish_route.py main-board --rip-local 2V8A --fan U5.19
"""
from __future__ import annotations

import heapq
import math
import os
import sys

import pcbnew

HERE = os.path.dirname(os.path.abspath(__file__))
HW = os.path.dirname(HERE)
MM = pcbnew.FromMM
TO = pcbnew.ToMM

GRID = 0.05                 # mm
WINDOW = 8.0                # search window margin around the endpoints (mm)
VIA = (0.45, 0.2)           # diameter, drill (board min drill 0.2 mm; JLCPCB 4-layer ok)
MASK_WEB = 0.1              # via edge to a same-net pad: solder-mask web, not electrical clearance
VIA_COST = 30               # in grid steps
LAYERS = [pcbnew.F_Cu, pcbnew.In2_Cu, pcbnew.B_Cu]   # In1 is the GND plane: never routed on

# per-board signal connections to finish: (net, (ref, pad), (ref, pad), track width, clearance)
SIGNALS = {
    "main-board": [("AMP_INLN", ("U10", "1"), ("C51", "1"), 0.15, 0.18)],   # 0.15: board min 0.127
}
# two-pad nets to rip up first and re-route after the signals above (they wall a pad in):
# (net, (ref, pad), (ref, pad), width, clearance)
RIPUP = {
    # SPK_L leaves U10.16 and curls round U10.1, sealing AMP_INLN in on F.Cu (EP copper below)
    "main-board": [("SPK_L", ("U10", "16"), ("J8", "1"), 0.20, 0.18)],   # <= 56 mA peak: 0.2 mm is ample
}


class Obstacles:
    """Other-net copper as inflatable primitives, per layer (vias/PTH on all)."""

    def __init__(self, board, net_code, box):
        x0, y0, x1, y1 = box
        self.segs = {L: [] for L in LAYERS + [pcbnew.In1_Cu]}
        self.rects = {L: [] for L in LAYERS + [pcbnew.In1_Cu]}
        self.circles = []                                        # through all layers
        near = lambda ax, ay, bx, by, r: not (max(ax, bx) + r < x0 or min(ax, bx) - r > x1 or
                                              max(ay, by) + r < y0 or min(ay, by) - r > y1)
        for t in board.Tracks():
            if t.GetNetCode() == net_code:
                continue
            if t.Type() == pcbnew.PCB_VIA_T:
                c = t.GetPosition()
                r = TO(t.GetWidth()) / 2
                if near(TO(c.x), TO(c.y), TO(c.x), TO(c.y), r):
                    self.circles.append((TO(c.x), TO(c.y), r))
            else:
                a, b = t.GetStart(), t.GetEnd()
                hw = TO(t.GetWidth()) / 2
                if t.GetLayer() in self.segs and near(TO(a.x), TO(a.y), TO(b.x), TO(b.y), hw):
                    self.segs[t.GetLayer()].append((TO(a.x), TO(a.y), TO(b.x), TO(b.y), hw))
        for fp in board.GetFootprints():
            for p in fp.Pads():
                bb = p.GetBoundingBox()
                r = (TO(bb.GetLeft()), TO(bb.GetTop()), TO(bb.GetRight()), TO(bb.GetBottom()))
                if not near(r[0], r[1], r[2], r[3], 0):
                    continue
                if p.GetAttribute() in (pcbnew.PAD_ATTRIB_PTH, pcbnew.PAD_ATTRIB_NPTH):
                    if p.GetNetCode() != net_code or p.GetAttribute() == pcbnew.PAD_ATTRIB_NPTH:
                        for L in self.rects:
                            self.rects[L].append(r)
                    continue
                if p.GetNetCode() == net_code:
                    continue
                for L in self.rects:
                    if p.IsOnLayer(L):
                        self.rects[L].append(r)
        # rule areas (keep-outs) block tracks and vias on every layer
        for z in board.Zones():
            if z.GetIsRuleArea():
                bb = z.GetBoundingBox()
                r = (TO(bb.GetLeft()), TO(bb.GetTop()), TO(bb.GetRight()), TO(bb.GetBottom()))
                if near(r[0], r[1], r[2], r[3], 0):
                    for L in self.rects:
                        self.rects[L].append(r)

    @staticmethod
    def _seg_d(px, py, s):
        x1, y1, x2, y2, _ = s
        dx, dy = x2 - x1, y2 - y1
        L = dx * dx + dy * dy
        u = 0 if L == 0 else max(0.0, min(1.0, ((px - x1) * dx + (py - y1) * dy) / L))
        return math.hypot(px - (x1 + u * dx), py - (y1 + u * dy))

    def free(self, x, y, layer, r):
        """A disc of radius r at (x, y) on this layer clears all other-net copper."""
        for s in self.segs[layer]:
            if self._seg_d(x, y, s) < s[4] + r:
                return False
        for (a, b, c, d) in self.rects[layer]:
            if a - r < x < c + r and b - r < y < d + r:
                return False
        for (cx, cy, cr) in self.circles:
            if math.hypot(x - cx, y - cy) < cr + r:
                return False
        return True

    def via_free(self, x, y, clear, plane_ok):
        r = VIA[0] / 2 + clear
        layers = LAYERS + ([] if plane_ok else [pcbnew.In1_Cu])
        return all(self.free(x, y, L, r) for L in layers)
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

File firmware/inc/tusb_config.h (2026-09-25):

/* TinyUSB configuration: one CDC-ACM interface on USB2_OTG_FS (PA11/PA12, TinyUSB rhport 0). */
#ifndef TUSB_CONFIG_H
#define TUSB_CONFIG_H

#ifndef CFG_TUSB_MCU
#define CFG_TUSB_MCU            OPT_MCU_STM32H7
#endif
#define CFG_TUSB_OS             OPT_OS_NONE
#define CFG_TUSB_DEBUG          0
#define BOARD_TUD_RHPORT        0
#define CFG_TUD_ENABLED         1
#define CFG_TUD_MAX_SPEED       OPT_MODE_FULL_SPEED
#define CFG_TUSB_RHPORT0_MODE   (OPT_MODE_DEVICE | OPT_MODE_FULL_SPEED)
#define CFG_TUD_ENDPOINT0_SIZE  64

#define CFG_TUD_CDC             1
#define CFG_TUD_MSC             0
#define CFG_TUD_HID             0
#define CFG_TUD_MIDI            0
#define CFG_TUD_VENDOR          0

#define CFG_TUD_CDC_RX_BUFSIZE  512
#define CFG_TUD_CDC_TX_BUFSIZE  2048
#define CFG_TUD_CDC_EP_BUFSIZE  64

#endif

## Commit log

2026-09-25 a massive dump of pervious work so far
    [cup_insert_left.scad, cup_insert_right.scad, light_pipe_button.scad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]
2026-09-25 a structural change
    [cup_insert_left.scad, cup_insert_right.scad, light_pipe_button.scad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]
2026-09-25 Add mechanical/check_fit.py: board-vs-cup fit check
    Cross-checks params.scad, hardware/gen/layouts.py and the .kicad_pcb files
    (board size, corner radius, mounting holes, mic sound port), then checks
    board/battery/driver fit in the elliptical cup and the left-cup stack depth.
    Currently fails: all three main-board standoffs in cup_insert_left.scad
    overlap the 50 x 34 mm battery pocket, and the main board clears the
    72 x 62 cup wall by only 0.45 mm.
    Claude-Session: https://claude.ai/code/session_011tw1Ap8ThDgVV2SB1vJK8Q
2026-09-25 main-board: fix status-LED pad overlap, allow 0.2 mm thermal-via drills
    - D4-D6 (0603, back side, 2 mm pitch under the light pipe) rotated 90 deg:
    at rot 0 the pads of neighbouring LEDs touched (DRC clearance/short).
    - Board min drill 0.3 -> 0.2 mm: the TPS63001 / TPA6132A2 footprints'
    own thermal-pad vias are 0.2 mm (JLCPCB 4-layer supports 0.15 mm).
    Found by a first Freerouting pass; the board is not re-routed yet.
    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
    [layouts.py, pcb_build.py]
2026-09-25 sim: test the ANC on real recorded noise (ESC-50)
    sim/real_audio.py runs the tuned controller on 70 real field recordings
    (engine, chainsaw, hand saw, helicopter, train, vacuum cleaner, washing
    machine), 100 dB(A) outside. Passive + ANC lands at 65-75 dB(A) at the ear.
    Finding: engine and train trip the watchdog (6 and 2 resets). All trips
    are output clipping, not divergence: 63 Hz rumble needs ~15 Pa peak of
    anti-noise vs the 10 Pa clamp. With 20 Pa headroom there are no trips.
    Driver/amp headroom is now a hardware requirement to verify.
    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
2026-09-25 sim: seal-aware protection - self-measured attenuation while worn
    sim/seal_monitor.py estimates the cup's passive attenuation every second
    from signals the controller already has (x_c = x - F_hat*y outside,
    d_hat = e - S_hat*y inside, ANC removed) and flags a >= 3 dB drop from the
    fitted baseline. Leaks modelled as lower passive IL plus a higher driver
    leak corner, so the factory S_hat is wrong under a leak.
    Over 10 noises (3 synthetic + 7 real ESC-50 recordings) x 4 seals:
    estimate within 1.04 dB of truth, 23/23 leaks flagged, 0 false alarms.
    A thick glasses temple raises the real dose 3.9-8.7x vs the fitted level;
    ANC gain collapses (4.3 -> 1.4 dB(A)) and online S re-ID does not recover
    i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
2026-09-25 firmware: restore the third_party submodule links
    .gitmodules listed cmsis_device_h7, CMSIS_6 and tinyusb, but the
    restructuring commit dropped their gitlinks, so 'git clone --recursive'
    fetched nothing and the firmware could not build from a fresh clone.
    Re-added at current upstream heads; 'make' builds with -Werror
    (75.8 KB flash, 36 KB DTCM).
    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
2026-09-25 SPICE-verify the analog chain; fix two output/safety limits it exposed
    hardware/spice/run_spice.py (ngspice, values from hardware/gen/boards.py):
    - mic front ends match the sim's plant (7.6 Hz - 9.5 kHz, gains 3.42 /
    6.84), electronics noise ~23 dB(A) SPL (about the mic's self-noise)
    - VMID buffer: 85-87 deg phase margin with the 10 R isolation resistor,
    4 deg without it - keep it
    - DAC reconstruction: ~26 us group delay at 1 kHz, as the plant assumes
    - amp + driver + cup (Thiele-Small): driver requirement >= 17 Pa/V at
    63 Hz for the ~15 Pa real engine rumble needs; a 16 R driver doubles it
    Firmware fixes:
    - ear-overload cut-out could never fire: the in-cup channel saturates at
    15.9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
    [app.c, board.h]
2026-09-25 Seal monitor in firmware: per-band in-use attenuation vs a factory baseline
    The simulated study compared each noise with its own good-seal baseline,
    which a real shift can't do: broadband attenuation moves with the noise
    spectrum. Per-octave-band attenuation (250 Hz-2 kHz) belongs to the cup
    and seal, so one factory baseline works for every noise and a bad fit is
    caught at power-on too.
    - sim/seal_ref.py: reference (filters, per-second maths, decisions)
    - sim/seal_monitor.py: one factory baseline for 10 noises x 4 seals:
    23/23 real leaks flagged in 3-5 s, 0 false alarms
    - firmware: seal_rt_sample() in the audio ISR on x_c / d_hat (raw mics
    when idle), seal_add_second() at 1 Hz; amber LE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
    [anc_tool.py, app.c, main.c]
2026-09-25 mechanical: move the main-board standoffs off the battery
    All three board holes sit over the corners of the 50 x 34 mm battery
    pocket, so the straight standoffs went through the battery. Each standoff
    is now a pillar just outside the battery fence (pulled in to |x| <= 19.5
    mm to stay inside the elliptical cup) plus a lug that bridges over the
    battery to a boss 0.5 mm above it. Board height and hole positions are
    unchanged; the lug underside is 45 degrees so it prints without supports.
    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
    [cup_insert_left.scad]
2026-09-25 main-board: routed except 11 connections; power tracks fit fine-pitch pads
    - Power net class 0.40 -> 0.30 mm: a 0.4 mm track can't reach the 0.5 mm
    pitch pads of the LQFP-100, WQFN/QFN parts and USB-C at 0.18 mm
    clearance, so every power/GND pin of those parts was left unrouted
    - tie_gnd_islands(): outer-layer GND pour islands without a via get one
    down to the inner plane (clearing other-net copper on every layer, no
    via-in-pad); islands too small for a via get a short fan-out track
    - new stages: 'tie' (islands + refill + DRC on a finished board) and
    'complete' (one more autorouter round, then tie in a fresh process -
    works around KiCad 7 SWIG wrappers going stale after an SES im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
    [main-board.kicad_pcb]
2026-09-25 README: real-recording, SPICE, fit-check and seal-monitor results; honest main-board status
    Main board: autorouted except 11 connections, listed with what to do.
    Adds the driver requirement from SPICE, build commands for the new
    tools, current firmware size, and the factory calibration steps.
    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
2026-09-25 check_fit: compare every anchored footprint's position, rotation and side
    Review feedback: the three-source check only compared mounting holes, so
    a layouts.py change the .kicad_pcb didn't pick up (the D4-D6 rotation
    in 5202890, before the board was regenerated) went unnoticed. Now every
    anchor in layouts.py is checked against the placed footprint on all
    three boards, with B.Cu orientations un-mirrored. Current boards: 44/44
    match; the board file from 5202890 fails on D4, D5, D6.
    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
2026-09-25 Review fixes: project min drill 0.2 mm; check Edge.Cuts corner radii
    - pcb_build.write_project() still wrote min_through_hole_diameter 0.3
    while the board setting is 0.2 (the WQFN/QFN thermal vias); the
    generated project rules now agree with the board.
    - check_fit compared only the outline's bounding box, so a different
    corner radius with the same width/height passed. It now computes the
    radius of every Edge.Cuts arc and checks all four against layouts.py
    (main 14, satellite 5, mic 1.5 mm: all match).
    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
    [pcb_build.py]
2026-09-25 firmware: driver acceptance test (tone + lock-in, in-cup Pa/V)
    'test driver [Hz] [mVpk]' plays a sine at a known amp-output voltage on
    both ears (ANC off, new MODE_TEST), lock-in detects each error mic over
    whole periods after 0.3 s settling, and reports Pa/V per ear with PASS/
    FAIL against the 17 Pa/V the SPICE study requires at 63 Hz. Datasheets
    don't give in-cup Pa/V, so candidate drivers are qualified in the real
    earcup; the same test serves as an end-of-line check.
    - dsp_misc: tone_t (renormalised rotator + two-channel lock-in)
    - test_fil.py: lock-in through the plant's secondary path with mic noise
    matches |S(f)| x amplitude within 0.03 % at 63 Hz and 1 kHz; ALL PASS
    - anc_tool.py d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
    [anc_tool.py, app.c, main.c]
2026-09-25 main-board: fully routed (0 unconnected), DRC clean, fab files
    From 11 unrouted after Freerouting to 0, with hardware/gen/finish_route.py:
    a grid A* router over F.Cu/In2.Cu/B.Cu that
    - routes a boxed-in signal after ripping up the net that walls it in
    (AMP_INLN at U10.1; SPK_L re-routed at 0.2 mm - <= 56 mA peak)
    - fans GND pads out to a via, an existing GND via or a tied GND pour
    - rips up a whole wall net or only its segments near a pad, and saves only
    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
    [main-board-B_Cu.gbl, main-board-B_Mask.gbs, main-board-B_Paste.gbp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]
2026-09-25 mechanical: printable STLs + export script
    export_stl.sh renders every part (left/right trays and baffles, mic pod
    and its drill template, light pipe + button plunger) to mechanical/stl/.
    Checked in at the nominal 72 x 62 x 32 mm earmuff so a first print is
    possible; re-run after measuring the real earmuff and passing check_fit.py.
    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
    [cup_insert_left-baffle.stl, cup_insert_left-tray.stl, cup_insert_right-baffle.stl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]
2026-09-25 Acceptance test runner + build / bring-up / TRL-6 procedure
    tools/acceptance_test.py: the per-helmet evidence run over USB - health,
    mic trims, path identification, driver Pa/V, seal baseline, passive vs
    ANC in ~100 dB(A) noise (with a reference SPL meter), seal leak with a
    glasses temple, 10 min soak. Operator prompts where hands are needed;
    writes reports/<unit>-<date>/acceptance.{md,json}, every limit citing
    the study it comes from. --self-test runs it against a simulated helmet
    (19/19; a stricter limit correctly fails with exit 1).
    docs/bringup_and_test.md: ordering (JLCPCB settings, BOM matching without
    guessed LCSC numbers), parts to buy, mechanical measure/print, bring-up
    with rail l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
    [acceptance_test.py]
